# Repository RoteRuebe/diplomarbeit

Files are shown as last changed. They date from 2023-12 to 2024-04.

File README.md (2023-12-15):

Repository mit allen Files für die Diplomarbeit. An der Diplomarbeit arbeiten:

1. Lukas Lucut     (Hardware)
2. Bastian Eismann (3D - Modeling)
3. Yannick Zickler (Software)

---

# Hardware

Hier sind die Kicad - Platinendesigns von Roboter und Controller zu finden. Beide haben jeweils zwei Versionen, Rev A und Rev B.

# 3D - Modeling

Hier werden alle 3D Modelle und Cura 3D Setting sein.

# Software

Hier sind alle Codes der Diplomarbeit zu finden. Es gibt Testcodes für einzelne Module sowie die zusamengesetzten Hauptcodes

# Misc.

Außerdem sind die derzeitige Version der Diplomarbeit, Arbeitzeiterfassung (AZE) und der Projektplan hochgeladen.

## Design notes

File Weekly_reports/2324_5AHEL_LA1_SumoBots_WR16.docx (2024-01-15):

Weekly Report 16

Jahrgang/Klasse: 5AHEL
Übungsleiter: | Prof. Dipl.-Ing. Michael Zatl
Übungsdatum: | 01.01.2024 – 06.01.2024
Abgabedatum: | 13.01.2024
Gruppe: | SumoBots
Projektteilnehmer: | Lukas Lucut Yannick Zickler Bastian Eismann
Beurteilung:
Vermerke des Übungsleiters:

Inhaltsverzeichnis

# 1 Tätigkeiten

## 1.1 3D-Design und Konstruktion (EISMANN)

Aufgrund von mehreren Arbeitsaufträgen und Prüfungen, konnte im Arbeitspaket 3D-Desgin und Konstruktion nicht gearbeitet werden.

## 1.2 Hardware-Entwicklung (LUCUT)

Da noch auf die PCB-Bestellung gewartet wird, wurde die Zeit genutzt, um weitere Kapiteln in der Diplomarbeit zu schreiben, sowie ältere Kapiteln zu Verbessern.

## 1.3 Software-Entwicklung (ZICKLER)

Es wurde ein Code geschrieben, mit welcher die Sensordaten vom Roboter auf einer HTML-Seite in einem Diagramm illustriert werden. Des Weiteren wurden einige Kapitel in der Diplomarbeit überarbeitet und hinzugefügt.

# 2 Next Steps

## 2.1 3D-Design und Konstruktion (EISMANN)

Der Designprozess des letzten Gehäuses wird mit der Ankunft des PCBs begonnen.

## 2.2 Hardware-Entwicklung (LUCUT)

Falls kommende Woche die Platine da sein sollte, wird diese Bestückt und bereits in Betrieb genommen.

## 2.3 Software-Entwicklung (ZICKLER)

Mit einer fertig bestückten Platine, beginnt der Debug-Ablauf von neu, um alle Funktionen des Mikrocontrollers sicherzustellen. Dazu werden die Sensoren in den Code implementiert, um diese mit dem Funkmodul an einem Raspberry Pi zu senden, welcher diese auf einer Website in einem Diagramm darstellt.

LABOR Seite 11 von 11

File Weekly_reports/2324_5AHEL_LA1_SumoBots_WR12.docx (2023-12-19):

Weekly Report 12

Jahrgang/Klasse: 5AHEL
Übungsleiter: | Prof. Dipl.-Ing. Michael Zatl
Übungsdatum: | 08.12.2023
Abgabedatum: | 15.12.2023
Gruppe: | SumoBots
Protokollersteller: | Lukas Lucut
Übungsteilnehmer: | Yannick Zickler
| Bastian Eismann
Beurteilung:
Vermerke des Übungsleiters:

Inhaltsverzeichnis

# 1 Tätigkeiten

## 1.1 3D-Design und Konstruktion (EISMANN)

Im Laufe der Woche traten vermehrt Druckprobleme und Instabilitäten bei den 3D-Drucken auf, welche sich nach einiger Fehlersuche als ein Problem mit dem Extruder des Ender 3s herausstellte. Bei diesem ist eines der beiden Zahn-räder bis auf den letzten Zahn abgerundet worden, wodurch sich oben genannte Probleme zeigten. Die nötigen Ersatzteile wurden bestellt. Ein weiterer Punkt der Woche war die Verbesserung von alten 3D-Modellen, um auf die Wünsche der anderen Abteilungen einzugehen. Dies beinhaltet: Sensorenhalterungen, LCD-Screen-Aushebung, Platzierung des An-Aus-Schalters sowie die Inkludierung einer RGB-Status-LED.

## 1.2 Hardware-Entwicklung (LUCUT)

Zunächst wurden die Sensoren für das Roboter Rev B PCB ausgewählt und die jeweilige KiCAD Library wurde recherchiert und nach Richtigkeit überprüft. Die jeweiligen Sensoren wurden bereitgestellt und werden in nächster Zeit programmiert, um sie nach der Bestückung der Platine, auf Funktion testen zu können. Die restliche Zeit wurde für die Dokumentation der bereits vollbrachten Arbeit investiert, um mit dem konkurrierenden Aufbaulehrgang mitzuhalten.

## 1.3 Software-Entwicklung (ZICKLER)

Die Verbindung zwischen den Roboter und einem Raspberry mit einem Funkmodul wurde ermöglicht, ohne das die Kommunikation zwischen Controller und Roboter zu stören. Damit wurde ein Meilenstein der Diplomarbeit vollbracht, welche durch den gezielten Einsatz von Alufolie, ermöglicht wurden.

# 2 Next Steps

## 2.1 3D-Design und Konstruktion (EISMANN)

Es sollen erhaltene Ersatzteile des Druckers verbaut und getestet werden und im anschluss weitere Drucke gestartet werden.

## 2.2 Hardware-Entwicklung (LUCUT)

Der Schaltplan wird weiterentwickelt und versucht bis zum Ende der Ferien fertigzustellen. Falls dies nicht zutreffen sollte, werden in den letzten zwei Tagen Vorbereitungen getätigt, um die Arbeit im „Home-Office“ weiterführen zu können.

## 2.3 Software-Entwicklung (ZICKLER)

Es werden Testcodes für jegliche Zusatzmodule geschrieben, die die Arbeit des Debugging erleichtern soll. Falls während diesen Tätigkeiten keine Probleme auftreten sollten, wird an dem vollständigen „Main-Code“ weitergearbeitet.

LABOR Seite 11 von 11

Next Steps

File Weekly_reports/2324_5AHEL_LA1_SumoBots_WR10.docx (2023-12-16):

Weekly Report 10

Jahrgang/Klasse: 5AHEL
Übungsleiter: | Prof. Dipl.-Ing. Michael Zatl
Übungsdatum: | 10-24.11.2023
Abgabedatum: | 21.11.2023
Gruppe: | SumoBots
Projektteilnehmer: | Lukas Lucut Yannick Zickler Bastian Eismann
Beurteilung:
Vermerke des Übungsleiters:

Inhaltsverzeichnis

# 1 Tätigkeiten

## 1.1 3D-Design und Konstruktion (EISMANN)

Im Bereich 3D-Design und Konstruktion wurden Anpassungen am Gehäuse und am Antriebssystem vorgenommen. Eine Umstrukturierung bestimmter Komponenten im Gehäuse ermöglicht nun einen kompakteren Aufbau. Feste Positionen für die Antenne des Funkmoduls, den Farbsensor, einen Ausschalter, eine Status-LED und weitere Komponenten wurden erfolgreich festgelegt. Die Konstruktion des Controller-Gehäuses hat erste Design-Schritte durchlaufen, um eine grobe Bauart und Größe zu ermitteln.

## 1.2 Hardware-Entwicklung (LUCUT)

Es wurden alte Schaltungen und Komponenten überdacht. Dabei wurde besonderes Augenmerk auf die Integration zusätzlicher Sensoren gelegt. Die Umleitung einzelner Komponenten wie dem Funkmodul, dem Farbsensor und der Ladebuchse auf feste Positionen im Gehäuse wurde mit der 3D-Moedllierung besprochen. Die Anpassung der alten Akkuschrauber Trigger mit einem Tiefpass zur Bestückung des Controllers wurde ebenfalls als Plan festgelegt.

## 1.3 Software-Entwicklung (ZICKLER)

Es wurde sich konzentrierte auf weitere Tests zur Verbindung der Funkmodule. Die ersten Tests zur Integration des Raspberry Pi zur Ausarbeitung der Daten der vorgesehenen Sensoren wurden gestartet. Die Verbindungen zwischen dem Roboter und dem Controller wurden weiter überarbeitet, um die Funktion der Status-LED als verbessertes Diagnose-Tool zu nutzen.

# 2 Next Steps

## 2.1 3D-Design und Konstruktion (EISMANN)

Weitere Verbesserung an sowohl Roboter als auch Controller Gehäuse mit Rücksicht auf die Wünsche der anderen Abteilungen.

## 2.2 Hardware-Entwicklung (LUCUT)

Erstellung der neuen Roboterplatine nach Sicherstellung einer stabilen Funkmodul Verbindung in Zusammenarbeit mit der Abteilung Software.

## 2.3 Software-Entwicklung (ZICKLER)

Weiter Tests in Sachen Verbindung des Roboters und Controllers sowie Fehler Behebung bei der Raspberry Verbindung.

LABOR Seite 11 von 11

Next Steps

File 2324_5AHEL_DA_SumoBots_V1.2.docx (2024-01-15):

# DIPLOMARBEIT

# SumoBots

# Schuljahr 2023/24

Ausgeführt im Schuljahr 2023/24 von:

EISMANN Bastian | 5AHEL

LUCUT Ioan Lukas | 5AHEL

ZICKLER Yannick | 5AHEL

Betreuer/Betreuerin:

DI (FH) Michael Zatl

Erklärung über die eigenständige Verfassung

der Diplomarbeit

Wir, die Herren Bastian EISMANN, Ioan LUCUT und Yannick ZICKLER, Schüler der Klasse 5AHEL der Höheren Technischen Bundeslehranstalt Wien 10, erklären hiermit an Eides statt, dass wir die vorliegende Diplomarbeit selbständig und ohne fremde Hilfe verfasst haben, einschließlich auch andere als die angegebenen Quellen und Hilfsmittel nicht benutzt und die benutzten Quellen, wörtlich und inhaltlich entnommenen Stellen, als solche erkenntlich in der Diplomarbeit gekennzeichnet haben.

Wien am 31.05 2024

Verfasser:

Bastian EISMANN | 5AHEL U: ___________________

Ioan Lukas LUCUT | 5AHEL U: ___________________

Yannick ZICKLER | 5AHEL U: ___________________

# 1 Danksagung

xxxxxxxx

# 2 Zusammenfassung (Deutsch)

Das Ziel dieser Diplomarbeit war es, einen Fahrzeugroboter, welcher durch eine Funkverbindung mit einem selbst entwickeltem Controller, gesteuert werden kann, zu entwickeln und konstruieren. Joystick und Schultertasten des Controllers geben Geschwindigkeit und Richtung des Roboters vor.

In diesem Projekt werden zwei separate Printed Circuit Boards (PCBs) entwickelt, die mithilfe von KiCAD entworfen werden. In jeden der beiden Platinen ist ein AVR-Mikrocontroller integriert, der für die Steuerung der jeweiligen Schaltung verantwortlich ist. Die Kommunikation zwischen den beiden erfolgt über das NRF24L01+ Funkmodul.

In der Diplomarbeit spielen die Auswahl des richtigen Materials und die Kalibrierung der 3D-Drucker eine zentrale Rolle. Die Gewährleistung des Druckererfolgs erforderte wesentliche Verbesserungen am Drucker. Ein weiterer entscheidender Schwerpunkt liegt auf der Modellierung von Gehäusen, Rädern, Antriebssystemen und dem Controller. Hierbei müssen zahlreiche Variablen berücksichtigt werden, um den Anforderungen verschiedener Abteilungen gerecht zu werden.

Die Mikrocontroller werden mit der Arduino – Umgebung und SPI – Schnittstelle programmiert. Der Code des Controllers muss seine Eingabeelemente einlesen und an den Roboter weiterschicken. Dieser muss die Werte einlesen, berechnen wie stark er den linken und rechten Motor ansteuern muss, und diesen Wert mit PWM – Signal an das Motorshield weiterleiten.

## 2.1 Abstract (English)

The goal of the diploma thesis is to develop and construct a vehicle robot that can be controlled through a wireless connection with a self-designed controller. The joystick and shoulder buttons of the controller determine the speed and direction of the robot.

In this project, two separate Printed Circuit Boards (PCBs) will be developed using KiCAD. Each of these boards will integrate an AVR microcontroller responsible for controlling its respective circuit. Communication between the two will be facilitated through the NRF24L01+ wireless module.

The thesis focuses on the selection of appropriate materials and the calibration of 3D printers, which are crucial for ensuring successful printing. Significant improvements to the printer were necessary to guarantee printing success. Another key emphasis is placed on modeling the robot's housing, wheels, propulsion systems, and the controller. This involves considering numerous variables to meet the requirements of different departments.

The microcontrollers will be programmed using the Arduino environment and SPI interface. The controller's code must read its input elements and transmit them to the robot. The robot, in turn, will need to read these values, calculate how much to control the left and right motors, and send this value to the motor shield using a PWM signal.

# 3 Einleitung – Projektbeschreibung

xxxx

Abbildung 1: Systemarchitektur des Projekts

## 3.1 Vorgeschichte – Ausgangslage

### 3.1.1 Projektwoche 2023

Im Zuge der vergangenen Projektwoche wurde bereits ein Roboter und eine Fernsteuerung entwickelt und in Betrieb genommen. Beide Prototypen wurden von dem
AVR-Mikrocontroller ATMEGA 328p angesteuert. Die Kommunikation zwischen den beiden, wurde durch das Funkmodul NRF24L01+ ermöglicht, welches die Daten vom Controller an den Roboter sendet. Mit diesen Daten steuert das implementierte Motorshield Cytron MDD3A die Motoren. Als Spannungsquelle wurde ein 12V Bleiakku genutzt.

### 3.1.2 CLIL 2023

Während des CLIL-Unterrichts 2023, wurde als Ziel die Weiterentwicklung der entwickelten SumoBots, sowie die Verbesserung von Konstruktion und Hardwarefehlern gesetzt, um die Milestones der Diplomarbeit genau definieren zu können. Bei der Konstruktion wurde auf das Arbeiten mit Fusion 360 gesetzt, um verbesserte und professionellere 3D-Modelle konstruieren zu können. In der Hardwareentwicklung wurde ein Fehler, welcher im Zusammenhang mit den unterschiedlichen Logikpegeln des Mikrocontrollers und Funkmoduls steht, durch einen Logic-Level-Converter verbessert. Des Weiteren wurden einige Recherchen, sowie eine Testschaltung entwickelt. In der Software wurde der Fokus auf
In-System-Programming gelegt, in welchen einige Testcodes geschrieben wurden.

# 4 Struktur des Projekts – Arbeitspakete

## 4.1 Objektstrukturplan (OSP) / Arbeitspakete

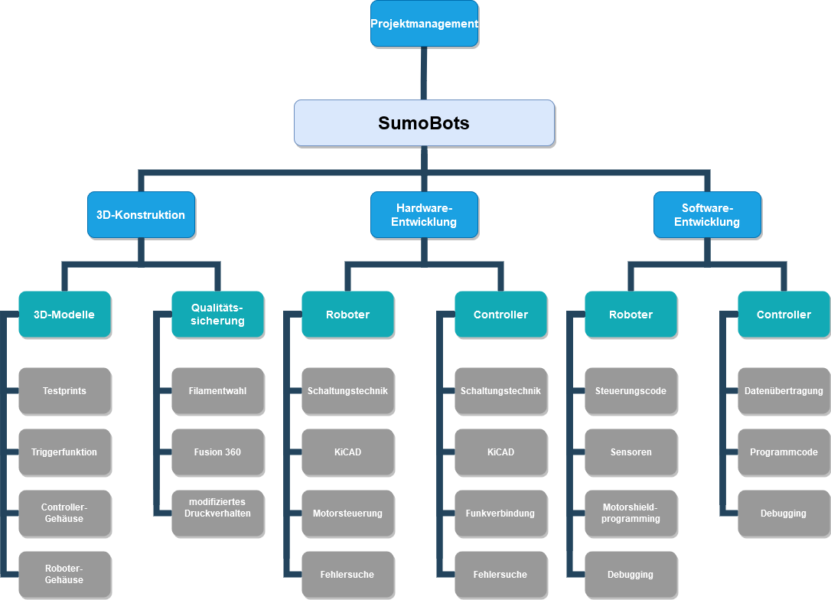
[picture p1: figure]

Abbildung 2: Objektstrukturplan (OSP) / Arbeitspakete

Um einen besseren Einblick der Tätigkeiten, sowie deren Aufteilung in den Arbeitspaketen zu gewähren, wird die Diplomarbeit in einem Objektstrukturplan dargestellt. Hier wurden die dazu gehörigen Hilfsmittel, Aufgaben, sowie die benötigten Fähigkeiten für das jeweilige Arbeitspaket genau beschrieben.

## 4.2 Projektstrukturplan (PSP)

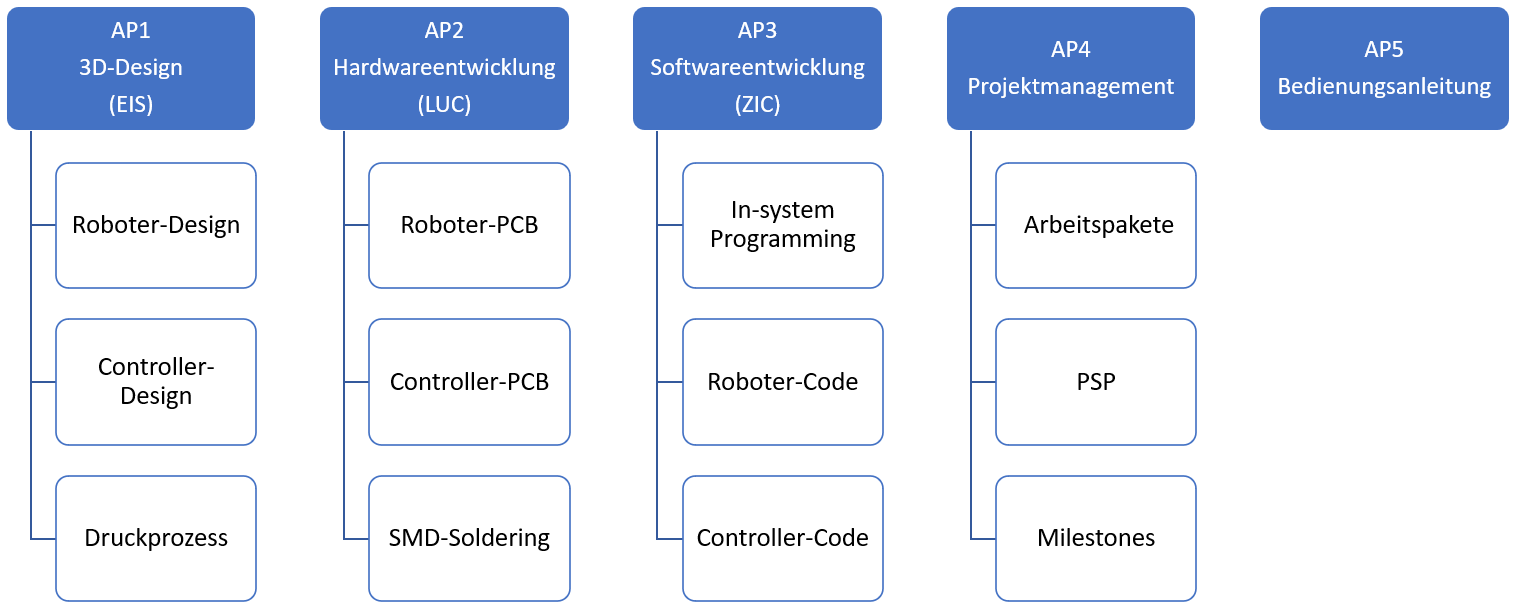
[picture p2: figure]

Abbildung 3:Projektstrukturplan (PSP) AP1-AP6

Die im oberen Diagramm beschriebenen Tätigkeiten wurden in Arbeitspakete und daraufhin auf die Diplomanden aufgeteilt.

## 4.3 Arbeitspaket 1 3D-Design (EIS)

Im Arbeitspaket „3D-Konstruktion“ wird neben den 3D-Modellen, ebenfalls Qualitätssicherung benötigt, da dieses Aufgabengebiet die Stabilität und Qualität der 3D-Prints sicherstellen.

## 4.4 Arbeitspaket 2 Hardware-Entwicklung (LUC)

Die Schaltungsentwicklung wird im Arbeitspaket „Hardware-Entwicklung“ bearbeitet, in welchen der Entwicklungsprozess des Roboters und des Controllers Schrittweise abgebildet ist. Der Hauptfokus liegt hierbei in der Entwicklung des Schaltplans und des darauffolgenden Platinenlayouts, welches in KiCAD designet wird. Es werden hierbei doppelseitige Platinen erstellt, um die in der Projektwoche eingebauten Drahtbrücken zu vermeiden. Diese Platinen werden zum Großteil mit SMD-Bauteilen bestückt, daher ist das SMD-Löten ein wichtiger Bestandteil und stellt damit auch ein Risikofaktor des Arbeitspakets da.

## 4.5 Arbeitspaket 3 Software-Entwicklung (ZIC)

Das Arbeitspaket „Software-Entwicklung“ beinhaltet Softwaredesign, Debugging, Ansteuerung der SPI und I2C Buse zur Programmierung von µC und einlesen verschiedener Sensormodule und die Kommunikation mithilfe von Funkmodulen zwischen Controller und Roboter sowie Roboter und Server.

## 4.6 Arbeitspaket 4 Projektmanagement

Die Struktur, Koordination und Organisation der Diplomarbeit wird im Arbeitspaket „Projektmanagement“ bearbeitet und beinhaltet sämtliche Pläne, Zielsetzung, sowie der dazugehörigen erstellten Milestones-Pläne und Arbeitszeiterfassungen. Um die Arbeitszeiten, samt den Tätigkeiten der Diplomanden im Blick zu behalten, werden diese erfasst und in eine Arbeitszeiterfassung AZE dokumentiert. Des Weiteren werden die Arbeitspakete in einem Projektstrukturplan auf die Diplomanden aufgeteilt, die die Tätigkeiten der Diplomanden auf gewählte Bereiche einschränken. Dazu wird der Fortschritt des jeweiligen Arbeitspakets in einem Granttchart in Projektlibre als Graph dargestellt.

## 4.7 Arbeitspaket 5 Bedienungsanleitung

Um die fertige Diplomarbeit nach Abgabe in Betrieb nehmen zu können, wurde eine Bedienungsanleitung geschrieben, in welcher die Inbetriebnahme, samt weiteren Konfigurationseinstellung, dokumentiert wird.

# 5 3D-Design und Konstruktion

Dieses Kapitel behandelt und beschreibt den Aufbau, sowie die Konstruktion der Mechanik des Roboters und der Controller-Fassung. Für den Bau dieser Komponenten wird das CAD-Programm Autodesk Fusion 360 in Verbindung mit dem Slicer-Programm Cura 3D angewandt. Der gesamte Aufbau des Roboters, sowie des Controllers soll mit eigenerstellten STL-Files 3D-gedruckt werden. Dabei liegt ein beträchtlicher Fokus auf der Wahl des richtigen Materials, beim 3D-Drucken Filament genannt, da diese zwischen den unterschiedlichen Werkstoffen viele differente Eigenschaften aufweisen können.

## 5.1 3D-Drucker Begriffserklärungen

### 5.1.1 Vom CAD-File zum Drucken

Der erste Schritt im 3D-Design und Druckvorgang beinhaltet die Wahl des gewünschten CAD oder auch Computer Aided Design Programmes, welches zum Erstellen der benötigten Dateien benutzt wird. Zur Auswahl stehen hier eine große Ansammlung von verschiedensten CAD-Programmen für den Heim- als auch Firmengebrauch. Durch persönliche Erfahrungen mit dem Programm Fusion 360 von Autodesk, wurde dies für die gesamte Konstruktion von Roboter als auch Controller benutzt. Das verwendete Dateiformat für die Modellierten Teile wurde auf .STL Files festgelegt, da diese am einfachsten durch ein Slicer-Programm weiterzuverarbeiten sind.

Ein sogenannter Slicer wird benötigt um die .STL Dateien auf eine Koordinatenorientierte Programmiersprache mit dem Namen G-Code zu übersetzen. 3D Drucker können diesen Ge-sliced G-Code dann auslesen und nach vorgaben der ursprünglichen .STL Datei nach drucken. Hierbei arbeitet der Drucker mit Seinen 3 Achsen X- , Y- und Z-Achse um die vorgegebenen Koordinaten und befehle im G-Code abzufahren, wodurch das gewünschte Modell entsteht.

Ein anderes Feature der Slicer ist es verschiedene Druckeigenschaften für den bestimmten Druckvorgang zu konfigurieren, wodurch zum Beispiel die Geschwindigkeit, Temperatur, Startposition sowie viele anderen Faktoren individuell für jeden Druck geändert werden können. Als Slicer für alle 3D-Modelle fiel die Wahl auf Ultimaker Cura 3D, wegen seiner vielfältigen Einstellmöglichkeiten und Optionen.

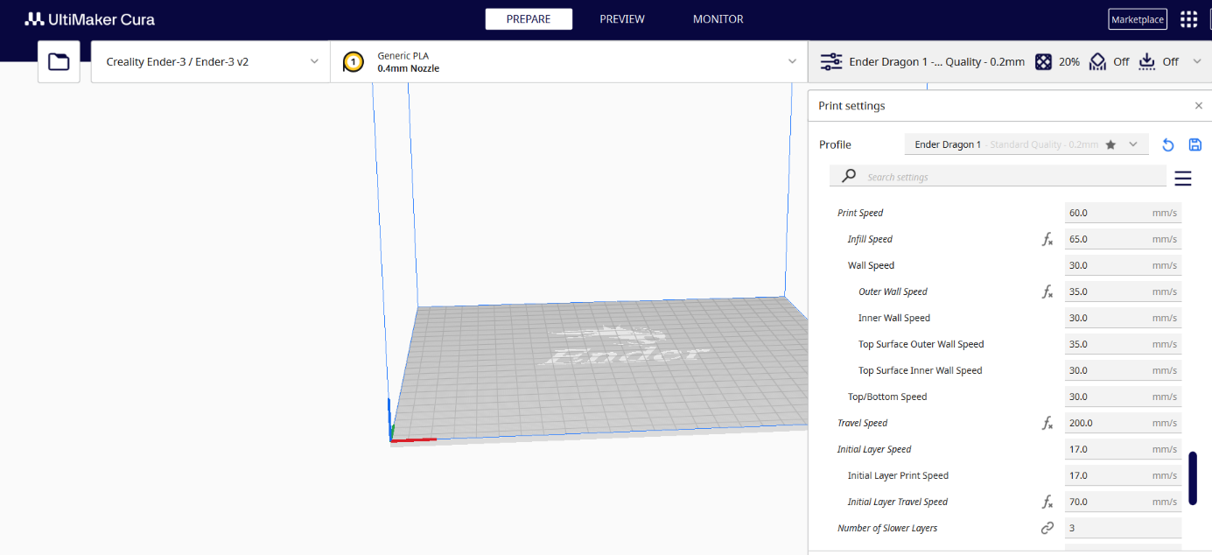
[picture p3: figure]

Wie in Abbildung 4: Cura 3D Interface zu sehen verfügt der Slicer über eine 3D-Ansicht in welcher der geplante Druck inspiziert und verschoben werden kann. Als Beispiel für die Einstellungsmöglichkeiten sind auf der rechten Seite der Abbildung die Geschwindigkeit Settings zu sehen welche den Travel Speed des Hotends sowie der restlichen Stepper-Motoren kontrolliert. Zu hohe Geschwindigkeiten können einen unsauberen Druck auslösen oder im schlimmsten fall sogar zum kompletten Fehldruck, siehe Abbildung 5: Kompletter Druckfehler, führen, welcher auch umgangssprachlich als „Spaghetti“ bekannt ist.

Abbildung 4: Cura 3D Interface

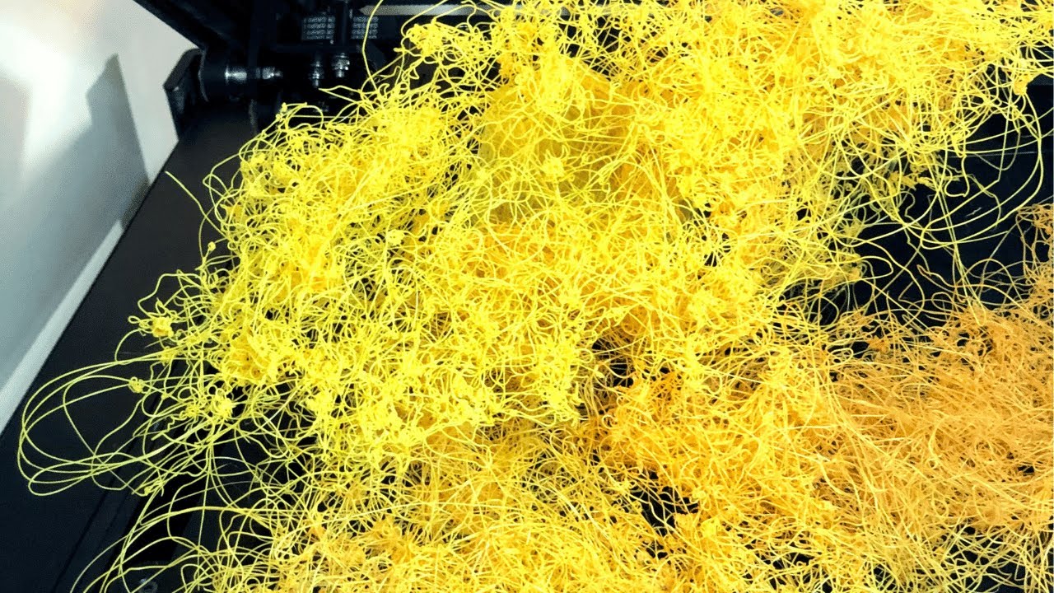
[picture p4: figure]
The Spaghetti Detective - YouTube

Abbildung 5: Kompletter Druckfehler

### 5.1.2 3D Drucker

Im laufe dieses Kapitels werden verschiedene begriffe und Beschreibungen für einzelne Komponenten eines typischen 3D Druckers verwendet. In diesem Abschnitt sollen die wichtigsten Begriffe aufgezeigt und erklärt werden.

## 5.2 Materialeigenschaften

Die Wahl des richtigen Filaments kann massive Auswirkungen auf sowohl Druckqualität wie auch Druckstabilität haben. Dadurch eignen sich manche Werkstoffe besser für gewisse Anwendungen als andere und können anhand verschiedener Anforderungen gewählt werden. Bei den 3D-Drucken verwendete Filamente sind PLA, PLA+, ABS und PETG, welche für diverse Anwendungen gebraucht oder getestet wurden.

### 5.2.1 PLA, PLA+

PLA auch Polylactide genannt, sind aus natürlichen Rohstoffen wie Maisstärke oder Zuckerrohr bestehende Polyester und sind eines der populärsten Filamente der Welt des 3D-Druckens. Das Material bietet eine, zu anderen Werkstoffen verglichen, niedrigere Schmelztemperatur was für einen besseren Druckvorgang und Druckqualität bei Temperaturschwankungen im Hotend des Druckers oder der Umgebungsluft.

Das Drucken von Standard PLA Filament ist theoretisch schon mit einer Temperatur von 190°C möglich, wird jedoch aus gesammelten Erfahrungen am besten mit einer Temperatur von 210-213 °C gedruckt. Dabei entwickelt das Filament die beste Haftung an der sogenannten Buildplate des 3D-Druckers, wodurch die Qualität und Stabilität des Drucks um ein Vielfaches gesteigert wird. Negative Aspekte des Filaments sind jedoch auch vielfach vorhanden. PLA ist durch seine Zusammensetzung aus natürlichem Polyester in der Theorie biologisch abbaubar, jedoch lässt sich aus Erfahrungswerten sagen, dass die Abbauzeit der Konstruktion des Controllers, oder der Roboter, keine beachtliche Rolle spielt da diese selbst mit Einwirkung von Regen, Wind und Sonne bis zu 80 Jahre dauern kann. Allerdings ist das Filament für tragende Anwendungen nicht geeignet, da die Festigkeit des Materials mit der Härte von ABS-Plastik nicht mithalten kann.

Zur Lösung dieses Problems gibt es den Stoff PLA+, welcher auf dem originalen PLA basiert, jedoch aber mit einer Reihe von anderen Stoffen kombinierten wurde, um seine positiven Druckeigenschaften zu verbessern und die Negativen, wo möglich, zu entfernen. So bietet dieses Material eine bis zu 10-mal höhere Schlagfestigkeit ohne die negativen Aspekte eines Stoffes wie ABS-Filament mit sich zu bringen.

### 5.2.2 ABS

ABS-Filament oder auch Acrylnitril-Butadien-Styrol ist ebenfalls ein Polyester, der jedoch auf synthetischer Basis hergestellt wird. Dadurch besitzt er nicht den Nachteil theoretisch biologisch abbaubar zu sein, wie PLA-Filament. Doch in der Praxis ist der bemerkenswerteste Unterschied die Schlagfestigkeit des Filaments. ABS besitz einen viel höheren Härtegrad als das übliche PLA-Filament und kann daher für mehr tragende Rollen eingesetzt werden als PLA.

Jedoch bietet dieses Material einen gewaltigen Nachteil im Gegensatz zu anderen Filamenten in Form eines weitaus schwierigeren Druckverfahrens. Die benötigte Temperatur um ABS-Filament stabil und mit guter Qualität Drucken zu können ist mit bis zu 260 °C weitaus höher und schwieriger konstant zu halten als bei vergleichbaren Stoffen, wodurch sich die Anwendung bei unserer Diplomarbeit als praktisch unmöglich herausstellte. Durch diese hohe Drucktemperatur ist das Filament äußerst anfällig für äußere Temperaturschwankungen der Umgebungsluft oder auch Druckplatte, wodurch ein Fehler namens Warping auftreten kann, siehe Abbildung 4 Warping.

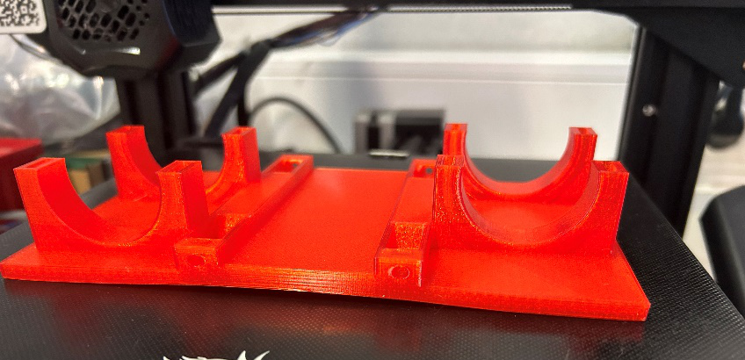
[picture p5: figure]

Abbildung 6: Warping

Hierbei „Warped“ oder verformt sich das Filament aufgrund von Temperaturschwankungen und vor allem große Flächen können deformiert und bis zur Unbrauchbarkeit verbogen werden. In der Theorie kann jeder Filament Stoff solche Ergebnisse hervorbringen, jedoch treten diese Fehler am häufigsten bei hohen Drucktemperaturen wie bei denen von ABS auf. Diese Instabilitäten kann durch konstante Temperaturhaltung ausgeglichen werden, jedoch erwies sich dies als unnötig für unsere Anwendungen da für ein solches Vorhaben eine Art „Druck-Behälter“ oder Kammer gebraucht wird.

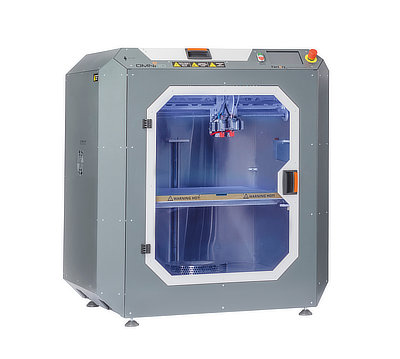
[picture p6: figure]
Omni3D Factory 2.0 NET Industrieller 3D-Drucker | 3D Prima - Top 3D-Drucker, 3D-Scanner, Filament, Resin & Zubehör günstig kaufen

Abbildung 7: 3D Druck Kammer

Diese sind meist extern Beheizt, um eine konstante Temperatur zu bieten und haben eine Luftfiltereinheit verbaut wodurch die Feinstaub- und Geruchs-belastung des ABS-Filament Druckvorgangs ebenfalls verringert wird. Diese Kammern, siehe Abbildung 5: 3D Druck Kammer, sind aber meist mit einem hohen Anschaffungspreis verbunden, wodurch die Hauptkonstruktion des Roboters nicht mit ABS-Filament vorgenommen wurde.

## 5.3 Konstruktionsvorgänge

Ein wichtiger Bestandteil der 3D Konstruktion besteht aus der Wahl der richtigen Teilkomponenten und passenden Verbindungsart.

### 5.3.1 Antriebsarten

Die Wahl der gewünschten Antriebsart wurde durch mehrere Tests und Prototypen festgelegt und durchlief teils massiven Veränderungen. Als Anfangskonzept wurde ein symmetrisches Motorlayout gewählt, bei dem der Roboter zwar nur über zwei Motoren verfügt, diese jedoch mit einer Übersetzung die anderen beiden Räder mitdrehen, um somit einen Allrad Antrieb zu haben der auf einem Ähnlichen Prinzip eines Kettenfahrzeugs oder Panzers basiert.

Durch die Symmetrie der beiden Roboterhälften wurde sowohl der Arbeitsaufwand als auch die Druck-Schwierigkeit enorm verringert.

### 5.3.2 Rahmen des Roboters

### 5.3.3 Verschraubungen und Normen

### 5.3.4 Embedded Components (EC)

## 5.4 3D-Modellierung des Roboters

## 5.5 3D-Modellierung des Controllers

# 6 Hardwareentwicklung

Im folgenden Kapitel werden die Funktionen, sowie die jeweiligen Entwicklungsschritte der Hardware des Roboters und Controllers erklärt. In Zuge dessen wird das Konzept der Steuerung, sowie der Kommunikation mit der dazugehörigen elektronischen Schaltung aufgegriffen.

## 6.1 Konzept

xxx

## 6.2 Entwicklungsablauf

Da in diesen Teil des Arbeitspakets mehrere Fehler auftreten können, wurde ein Flussdiagramm erstellt, das die Abläufe der Entwicklung, sowie weitere optionale Schritte darstellt. Das Vorplanen der Tätigkeiten ist hier besonders wichtig, aufgrund der aufkommenden Kosten der durch die PCB-Bestellungen von externen Firmen entsteht.

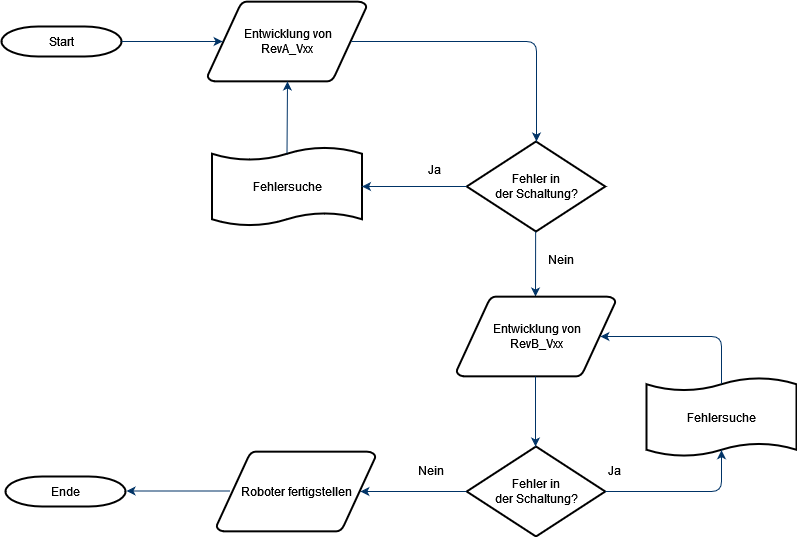
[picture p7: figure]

Abbildung 6 Entwicklungsablauf der Roboter Hardware

Dabei wurde die Hardware des Roboters in Revision A (RevA) und Revision (RevB) geteilt. In
Revision A wird eine Platine mit den elektronischen Grundkomponenten entworfen, die benötigt werden, um den Roboter zum Fahren zu bringen. Bei Revision A wird der Fokus auf dem Ermitteln und Korrigieren von vermeintlich auftretenden Fehlern. Falls in der ersten Version des PCBs gravierende Fehler auftreten, die das in Betrieb nehmen der Schaltung nicht ermöglichen, wird eine weitere Version von Revision A entwickelt. Wenn dieser optionale Fall nicht eintritt, wird die Revision B Schaltung entwickelt, bei der die funktionsfähige Schaltung von Revision A mit Sensoren und weiteren Bauelementen aufgewertet wird.

## 6.3 Hardware-Design Roboter Revision A

Wie bereits beschrieben, beschränken sich die Hauptaufgaben dieses Schaltungsentwurfs auf die Kommunikation mit einem Controller, die Steuerung der Motoren durch diesen sowie die In-System-Programmierung.

Abbildung 7 Blockschaltbild von Roboter Rev A V1.00

Als Mikrocontroller wird der ATMEGA2560 eingebaut, der als essentieller Teil der Schaltung gilt. Damit dieser funktioniert, muss eine 5V Gleichspannungsquelle und ein digitales Taktsignal vorhanden sein. Diese Versorgungsspannung wird durch das Motorshield ermöglicht, da auf diesem ein Spannungsregler verbaut ist, der die 12V vom Bleiakku in 5V umwandelt. Die 12V vom Bleiakku werden benötigt, um die Motoren zu versorgen. Das Taktsignal wird durch einen externen Quarzoszillator mit 16MHz generiert, der die Geschwindigkeit der Programmabläufe beeinflusst. Des Weiteren wird eine 3.3V Spannungsquelle benötigt, um das Funkmodul NRF24L01+ in Betrieb zu nehmen. Das Funkmodul arbeitet hierbei mit unterschiedlichen Logikpegeln als der Mikrocontroller. Um Fehler bei der Übertragung von Daten zu vermeiden, wird ein Logik-Pegel-Wandler (Logic Converter) dazwischengeschaltet, der die Pegeln von 3.3V auf 5V umwandelt. Da es sich hierbei um ein selbstentwickeltes PCB handelt, ist keine serielle Schnittstelle vorhanden. Um den Mikrocontroller programmieren zu können, wird über den SPI-Bus programmiert. Die
SPI-Pins (MOSI, MISO, SCK) sind auf den ICSP-Header vorhanden.

### 6.3.1 Roboter Revision A V1.00 PCB-Design

Das im Kapitel Error: Reference source not found illustrierte Blockschaltbild wurde in KiCAD als Schaltplan, sowie als Platinenlayout realisiert. Aufgrund der dünnen Bahnen von 0,25mm können beim Ätzen Fehler auftreten. Daher wird für die Roboterplatinen auf den schulexternen Hersteller Aisler zurückgegriffen.

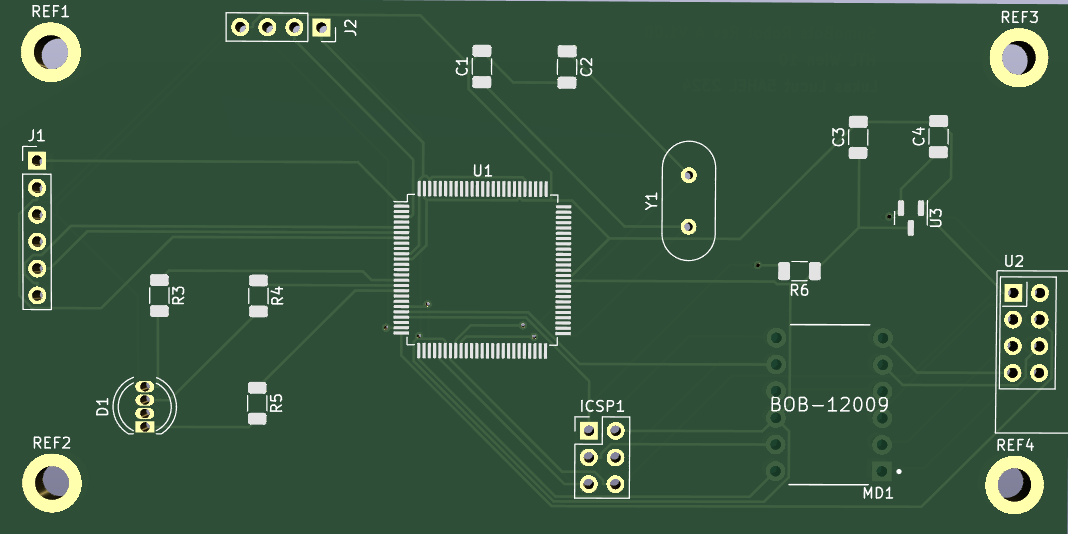
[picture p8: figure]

Abbildung 8 Roboter Rev A V1.00 PCB

Da hier das Löten mit SMD-Komponenten im Vordergrund steht, wurde der Platz zwischen den Bauteilen vergrößert, um leichter Fehler, die durch das Löten mit Heißluft zustande kommen, auszubessern. Im Fokus liegt hierbei der Mikrocontroller, der durch die Anzahl von 100 Pins, welche jeweils 0,25mm breit sind, fehleranfällig auf Kurzschlüsse ist. Der Quarz Y1, der als Taktgeber für den Mikrocontroller dient, sollte möglichst nah platziert werden, um kurze Signalwege zu gewährleisten. Durch die Minimierung von Leitungslängen werden Laufzeitverzögerungen reduziert, was die präzise Synchronisation des Mikrocontrollers verbessert. Gleichzeitig verringert dies die Anfälligkeit für elektromagnetische Störungen und trägt zur Gesamtstabilität und Leistungsfähigkeit des elektronischen Systems bei. Da das Motorshield über keine eigene KiCAD-Bibliothek verfügt, wurde stattdessen ein 6x1-Pinheader J1 implementiert, auf welchen dieser draufgelötet wird. Ein weiterer Grund für die Positionierung lag an seiner Größe und den Verbindungen, bei denen breitere Drähte mit den Motoren und dem Bleiakku verbunden werden müssen. Der 4x1 Pinheader J2 besteht aus zwei digitalen Pins, Vcc und Masse. Diese waren dazu vorgesehen, weitere Komponenten anzuschließen und auf Fehler zu überprüfen. Um das In-System-Programming zu ermöglichen wurde dieser ICSP-Header als 2x3 Pinheader ICSP1 realisiert. Dabei wurde die Reihenfolge der Pins vom Arduino UNO übernommen, um Fehler zu vermeiden. Das Funkmodul U2 wurde aufgrund seiner herausstechenden Antenne, am Rand der Platine positioniert, sodass ein Großteil des Gehäuses sich außerhalb des PCB befindet. Da für die Kommunikationskomponente eine Bibliothek existiert, gibt KiCAD bei dem Design Rule Check (DRC) eine Warnung aus, dass die Lötstoppmaske geschnitten wird. Aus diesem Grund wurde, wie in Abbildung 8 Roboter Rev A V1.00 PCB dargestellt, nur ein Teil des Umrisses (Front Silkscreen) auf der Platine realisiert. Für den Logik-Pegel-Wandler wurde eine Bibliothek genutzt, die ein anderes Modell, aber dasselbe Footprint mit derselben Reihenfolge von Pins, beinhaltet. Wie in Abbildung 8 Roboter Rev A V1.00 PCB zu erkennen ist, sind die Pin-Verbindungen nicht vergoldet. Dies hat zur Folge, dass es nicht möglich ist, den Logik-Pegel-Wandler an die Platine zu löten. Der Grund hierfür liegt an dem vorkonfiguriertem Footprint, dessen Pins keinem Layer (Front Mask/ Back Mask) zugewiesen wurden.

Bild vom fertig gelötetem PCB Vorderseite

Der Mikrocontroller wurde zunächst auf den Lötpads positioniert, und anschließend wurde jeder einzelne Pin mittels einer dünneren Lötspitze mit Flussmittel verlötet. Durch diesen Prozess konnten die Anzahl der Kurzschlüsse minimiert werden und leichter ausgebessert werden. Die restlichen SMD-Komponenten (Widerstände, Kondensatoren, Längsregler) wurden mit einer Lötpaste auf die Lötpads platziert, welche durch eine Erhitzung einer Heißluftstation, in den Schaltkreis implementiert wurde. Da es sich bei den restlichen Komponenten um THT-Bauteile handelt, wurden diese mit einem herkömmlichen Lötkolben verlötet.

### 6.3.2 Roboter Revision A V1.00 Erkenntnisse

Nach dem Erhalt der Platinen machte sich der Fehler, welcher durch den Logik-Pegel-Wandler zustande kam, bemerkbar. Dadurch war das Funkmodul nicht mit dem SPI-Bus verbunden. Da jedoch der ICSP-Header mit den benötigten Pins des Buses verbunden ist, wurden vom Funkmodul an den Pins MOSI, MISO, SCK Drähte an die entsprechenden Pins des ICSP-Headers verlötet. Zusätzlich wurden zwei digitale Pins (CE, CSN) benötigt, welche durch den Pinheader J2 zur Verfügung standen. Diese wurden ebenfalls mit einer Drahtbrücke miteinander verbunden. Zunächst wurden der Logik-Pegel-Wandler dazwischen gelötet, um den entwickelten Schaltplan zu befolgen. In diesem wird beschrieben, dass MISO, MOSI und SCK auf 5V konvertiert werden. Nach diesem Aufbau konnte das Funkmodul zwar eine Verbindung herstellen, bekam allerdings nur zufällige fehlerhafte Werte.

Der Fehler lag hierbei an dem MISO-Pin, welcher nicht umgewandelt werden durfte. Als dieser Fehler verbessert wurde, konnten die richtigen Werte erhalten werden. Nach diesem Test wurde aus dem Datenblatt die Information entnommen, in welcher beschrieben wird, dass kein Logik-Pegel-Wandler benötigt wird, da der NRF24L01+ 5V tolerant ist. Daher wurde für einen weiteren Test der Wandler nicht mit eingebaut.

Xx Bild von der Rückseite der Platine xX

Mit der anschließenden bestückten Platine konnte die Kommunikation, samt der Fernsteuerung des Motorshields getestet werden und resultierte eine erfolgreiche Schaltung.

## 6.4 Komponenten des Roboters Revision A

### 6.4.1 Motorshield

Da die Information, die der Mikrocontroller ausgibt, lediglich 0 oder 1 ist (0V / 5V) kann ein einzelner DC-Motor diese nicht verarbeiten. Bei einer direkten Verbindung zwischen dem Motor und des Mikrocontroller würde sich dieser nur mit einer konstanten Geschwindigkeit in einer Richtung oder gar nicht bewegen. Deswegen ist es möglich mit Hilfe eines dazwischen geschalteten Motorshields einen Motor mit Software in verschiedenen Modi anzusteuern.

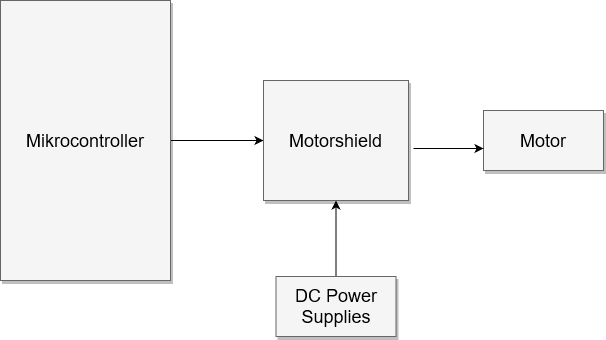
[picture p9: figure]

Abbildung 9 Motorshield-Blockschaltbild

Das Motorshield steuert den Motor mittels einer „H-Brücke“ mit PWM-Signalen an. Je nach Motorgröße ist eine zusätzliche Spannungsquelle notwendig, da nicht jeder mit 5V in Betrieb genommen werden kann. Da in der Diplomarbeit ein 12V Motor verwendet wurde, wird im Blockschaltbild die entsprechende Spannungsquelle integriert.

### 6.4.2 H-Brücke

Eine H-Brücke besteht aus vier Transistoren, die in einer „H“-Form geschaltet sind, um den Stromfluss in zwei Richtungen durch den Motor steuern zu können. In diesem Motorshield besteht die H-Brücke aus N- und P-Channel MOSFETs.

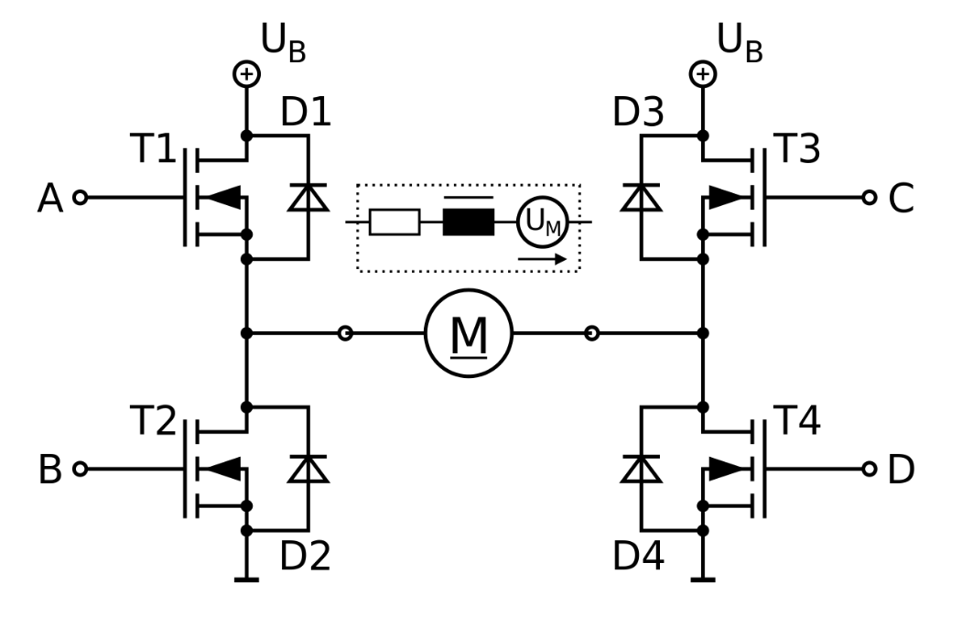
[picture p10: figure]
undefined

Abbildung 10 H-Brücke Schaltplan ( https://de.wikipedia.org/wiki/Vierquadrantensteller)

Um die Steuerung eines Motors zu ermöglichen, werden die Gate-Eingänge an den PWM-Pins des Mikrocontroller angeschlossen. Durch das Duty-Cycle-Verhältnis ist es nun möglich den Motor in verschiedenen Drehrichtungen mit einer dazugehörigen Geschwindigkeit rotieren zu lassen.

### 6.4.3 NRF24L01+ Funkmodul

Die Kommunikation zwischen dem Controller und dem Roboter wird durch das Funkmodul NRF24L01+ ermöglicht. Das Funkmodul arbeitet auf einem 2.4GHz ISM-Frequenzband, mit welchen ein drahtloser Austausch ermöglicht wird. Entwickelt von der Firma Nordic Semiconductor, zeichnet sich der NRF24L01+ durch seine hohe Effizienz und niedrige Leistungsaufnahme. Zusätzlich zur integrierten Antenne, die die Grundlage für die drahtlose Kommunikation bildet, besteht die Möglichkeit, externe Antennen anzuschließen, um die Reichweite des Moduls zu erweitern. Im Vergleich zum Vorgänger NRF24L01 bietet dieses Modell eine größerer Reichweite und unterstützt höhere Datenraten bis zu 2Mbit/s, je nach Konfiguration.

Abbildung 11 NRF24L01+ Funkmodul

Die Funktionsweise kann im folgenden Blockschaltbild abgelesen werden:

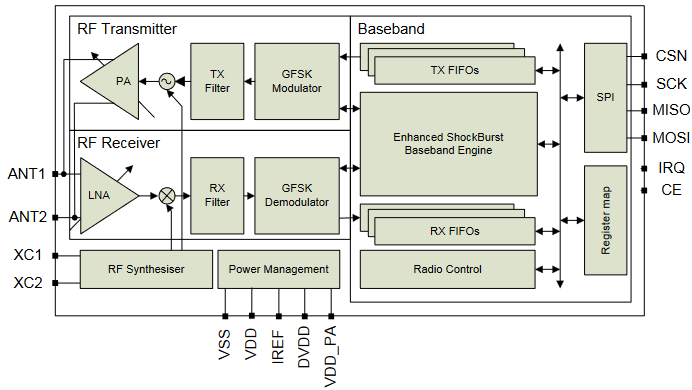
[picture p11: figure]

Abbildung 12 NRF24L01 Blockschaltbild (https://www.sparkfun.com/datasheets/Components/SMD/nRF24L01Pluss_Preliminary_Product_Specification_v1_0.pdf)

Die Informationen werden mittels der GFSK-Modulation (Gaussian frequency-shift keying) übertragen. Bei dieser handelt es sich um eine Art der Frequenzmodulation, bei der zwei Frequenzen für die Übertragung von Binärdaten verwendet werden. Hierbei verwendet der Sender RF-Transmitter („Radio Frequency“) das GFSK-Modulationsverfahren, wodurch digitale Daten in hochfrequente Funksignal im 2,4GHz-Band umgewandelt werden. Diese modulierten Signale enthalten Informationen für die drahtlose Übertragung an andere NRF24L01+-Empfänger. Zusätzlich implementiert dieser Kollisionsvermeidungstechniken, um sicherzustellen, dass mehrere Module im gleichen Netzwerk nicht gleichzeitig senden und kollidieren. Die Möglichkeit automatischer Wiederholungen von Datenpaketen kann bei Bedarf aktiviert werden, um eine zuverlässige Kommunikation zu gewährleisten. Der RF-Receiver übernimmt die Rolle des Empfänger der Signale. Er dekodiert hochfrequente Funksignale, die durch den RF-Transmitter moduliert wurden. Der Empfänger des NRF24L01+ nutzt das GFSK-Verfahren, um die Frequenzverschiebungen im Signal zu interpretieren und die ursprünglichen digitalen Daten wiederherzustellen. Der Baseband-Block im NRF24L01+ ist für die Verarbeitung der digitalen Daten auf der Basisbandebene verantwortlich. Dieser übernimmt die Aufgabe der Modulation der digitalen Daten in ein hochfrequentes Funksignal, die Implementierung von GFSK, sowie der Demodulation empfangener Signale. Durch den SPI-Bus kann das Modul die empfangenen Daten an einem Mikrocontroller übertragen oder weitere Informationen übertragen und gesteuert werden.

#### 6.4.3.1 Spannungsversorgung des Funkmoduls

Für den Betrieb des Funkmoduls ist eine Spannungsversorgung von 3,3V erforderlich. Daher wird eine Schaltung benötigt, die die 5V Betriebsspannung des Mikrocontrollers in 3,3V umwandelt. Um dies zu ermöglich wird der MCP1703A als Längsregler eingebaut, da dieser einen simplen Schaltungsaufbau zur Stabilisierung der Spannung bietet. Aufgrund der Fehler, die durch Spannungsabweichungen beim Übertragen, sowie Senden der Daten auftreten können, können Fehler vorgebeugt werden. Ein Längsregler ist ein Spannungsregler, der überschüssige Energie in Form von Wärme abführt, um die Ausgangsspannung zu stabilisieren. Im Gegensatz zu einem Querregler kann die Ausgangsspannung mittels Dimensionierung von Widerständen nicht geändert werden, da diese vom Hersteller in der Entwicklung festgelegt wurden.

Abbildung 13 3,3V-Längsreglerschaltung

Um Spannungsschwankungen und Rauschauftreten zu verhindert, wird im Datenblatt empfohlen zwei gleichgroße Kondensatoren am Eingang und Ausgang parallel zu schalten. Durch den Kondensator C1 wird sichergestellt, dass der Reger in einem stabilen Betriebszustand bleibt. Der Ausgangskondensator C2 dient dazu, die Ausgangsspannung zu stabilisieren und Spannungsspitzen zu minimieren, damit die Ausgangsspannung auch bei sich ändernden Lastbedingungen konstant bleibt.

#### 6.4.3.2 Spannungsschwankungen des NRF24L01

Wenn man das Funkmodul als Receiver betreibt, können Spannungsschwankungen beim Empfangen von Daten auftreten, die den Datenaustausch hindern können.

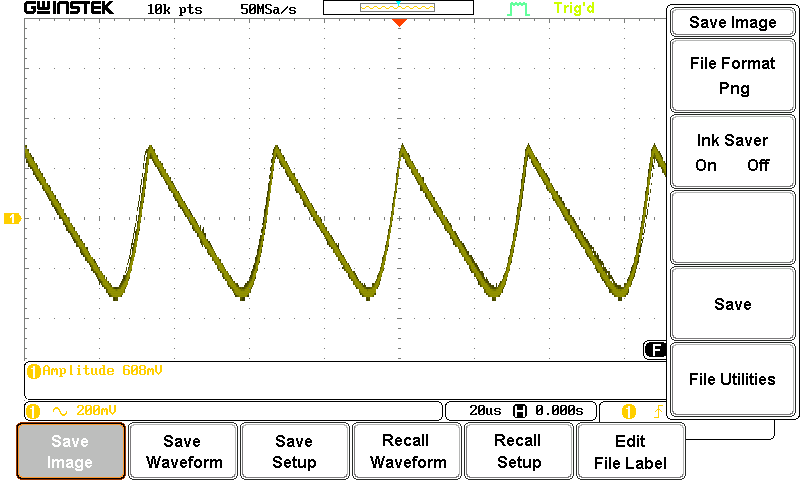
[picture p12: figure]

Abbildung 14 NRF24L01 Messung der Spannungsversorgung

In der oberen Messung wurde die Versorgungsspannung des Funkmoduls mit einem Oszilloskop gemessen. Hierbei kann man die Schwankungen, welche von 600mV – 800mV variieren erkennen, die während der Kommunikation zwischen zwei Modulen auftreten. Daher wurde ein C=10µF Elko zwischen den der Spannungsversorgung eingebaut. Um die resultierende Messung besser interpretieren zu können, wurde ein GPIO-Pin des Arduinos auf „1“ geschaltet.

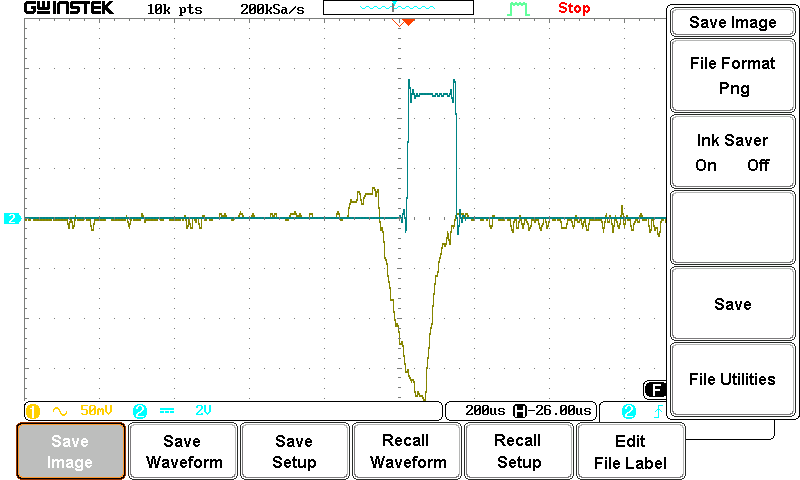
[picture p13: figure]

Abbildung 15 NRF24L01 Messung der Spannungsversorgung mit C = 10µF Elko und Logiksignal

Die in der oberen Messung erkennbaren Störung tritt nur einmal zu Beginn des Datenaustausch auf. Mit einem größeren Kondensator ist eine Verbindung, samt einen korrekten Datenaustausch möglich.

### 6.4.4 Serial Peripheral Interface Bus

Die Serial Peripheral Interface (SPI) ist ein synchroner serieller Bus ermöglicht eine effiziente bidirektionale Datenübertragung zwischen einem Master-Gerät und mehreren Slave-Geräten. Der Bus besteht typischerweise aus vier Hauptleitungen, wobei jede Leitung eine spezifische Funktion erfüllt.

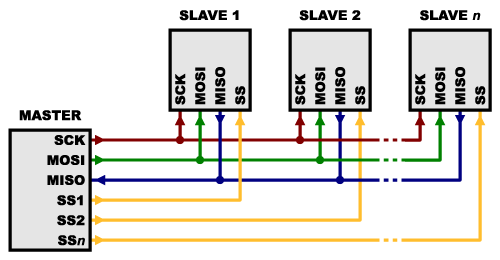
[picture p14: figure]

Abbildung 16 SPI-Bus (https://www.rc-modellbau-portal.de/index.php?threads/spi-schnittstelle-beim-arduino-co.6994/)

Die MOSI-Leitung (Master Out Slave In) dient dazu, dass der Master Daten an die Slaves übertragen kann. Umgekehrt ermöglicht die MISO-Leitung (Master In Slave Out) den Slaves, Daten an den Master zu senden. Die SCLK-Leitung (Serial Clock) überträgt den Takt vom Master an die Slaves, wodurch eine synchronisierte Datenübertragung möglich wird. Die SS/CS-Leitung (Slave Select/Chip Select) wird für jedes Slave-Gerät separat verwendet, um es auszuwählen und die Kommunikation mit dem Master zu initiieren.

Abbildung 17 SPI-Bus CLK-Konfiguration (https://edistechlab.com/wp-content/uploads/2020/11/Screenshot-2020-11-22-at-09.37.57.png)

Des Weiteren muss eine Synchronisation des Protokolls geeinigt werden, welche mit der CLK-Leitung gewählt wird. Dadurch ist es möglich den Zeitpunkt der Datenübertragung, welche durch fallende oder steigender Flanke, sowie des aktiven Zustandes (LOW/HIGH) zu konfigurieren.

Abbildung 18 SPI-Bus Kommunikation (https://edistechlab.com/wie-funktioniert-spi/?v=fa868488740a)

Die Kommunikation erfolgt durch das gleichzeitige Senden und Empfangen von Daten, in einem vorher festgelegten Taktzyklus. Zuerst wird mit der CS-Leitung bestimmt, ob der Master oder der Slave senden darf. Danach kommt es auf die Konfiguration des Clocksignal an, in welcher bestimmt wird, wann die Daten übertragen werden. Als letztes werden die Daten über der MOSI- oder MISO-Leitung Bit für Bit in Serie versendet.

### 6.4.5 In-System-Programming Hardware-Setup

XXX

### 6.4.6 Pierce-Oszillator

Da für die Inbetriebnahme des Mikrocontrollers ein Taktsignal benötigt wird, ist eine Oszillatorschaltung notwendig. Mit den Informationen aus dem Datenblatt wird ein Quarzoszillator dazu gebaut, der den ATMEGA2560 mit einem Rechtecksignal mit 16MHz versorgt.

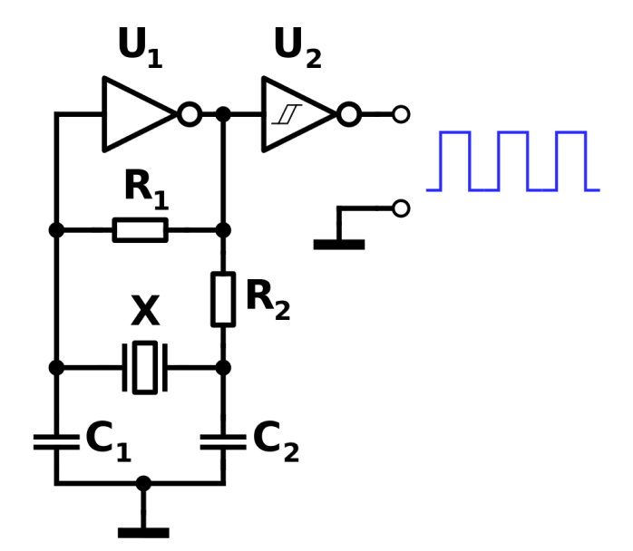
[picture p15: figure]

Abbildung 19 Schaltplan Pierce-Oszillator (https://de.wikipedia.org/wiki/Quarzoszillator)

Die Bauteile sind essentiell, um die Erzeugung und Stabilisierung der Taktfrequenz zu sichern. Der Quarz fungiert als frequenzbestimmendes Element, indem er aufgrund seiner piezoelektrischen Eigenschaften Schwingungen erzeugt, die als präzise Taktfrequenz dienen. Die Kondensatoren sind in der Regel parallel zum Quarz geschaltet. Sie dienen dazu, die nötige Kapazität für die Schwingungsbildung des Quarzes bereitzustellen. Die Kondensatorwerte von 22pF wurden gemäß den Angaben im Datenblatt ausgewählt, das die Gleichheit der Kapazitäten für beide vorschrieb. In einigen Schaltungen werden Widerstände parallel zu den Kondensatoren geschaltet, um die Impedanz des Oszillators zu beeinflussen. Die Widerstände können dazu beitragen, die Schwingungsfrequenz zu stabilisieren und unerwünschte Schwingungsmoden zu unterdrücken. Der Inverter U1 erzeugt eine um 180° phasenverschobene Ausgangsspannung, die für die positive Rückkopplung und Stabilisierung der Schwingungen im Oszillatorkreis, insbesondere bei Verwendung eines Quarzresonators, entscheidend ist. Der Schmitt-Trigger dient dazu, das Ausgangsignal des Oszillators zu stabilisieren und sicherzustellen, dass das Signal sich im Pegelbereich des Mikrocontroller befindet. Beim ATMEGA 2560 ist der Großteil der Oszillatorschaltung im IC implementiert, daher sieht die Beschaltung wie folgt aus:

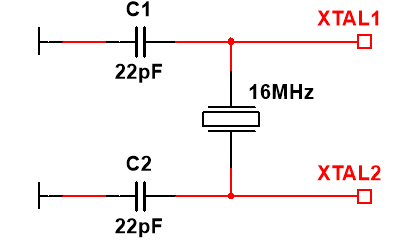
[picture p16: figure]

Abbildung 20 Oszillatorschaltung beim ATMEGA2560

Da der Mikrocontroller mit einer Taktfrequenz von 16MHz arbeitet, wird ein Quarz mit diesem Wert eingebaut. Die Pins XTAL1 und XTAL2 stellen hierbei die Anschlüsse des im IC eingebauten Oszillator da. Die Frequenz kann somit mit dem Wert des Quarzes gewählt werden.

## 6.5 Hardware-Design Roboter Revision B

Aufgrund der funktionierenden Schaltung im Kapitel 7.3 Hardware-Design Roboter Revision A wird der Entwicklungsplan konsequent umgesetzt. und ein Nachfolger der Roboterschaltung mit Verbesserungen entworfen. Es wird eine Weiterentwicklung der Roboterschaltung mit gezielten Verbesserungen konzipiert, wobei diese als zusätzliche Features integriert werden, ohne die grundlegende Fahrzeugsteuerung zu beeinträchtigen. Die primäre Zielsetzung besteht darin, den Roboter aufzuwerten. Die implementierten Erweiterungen sind im nachfolgenden Blockschaltbild detailliert dargestellt:

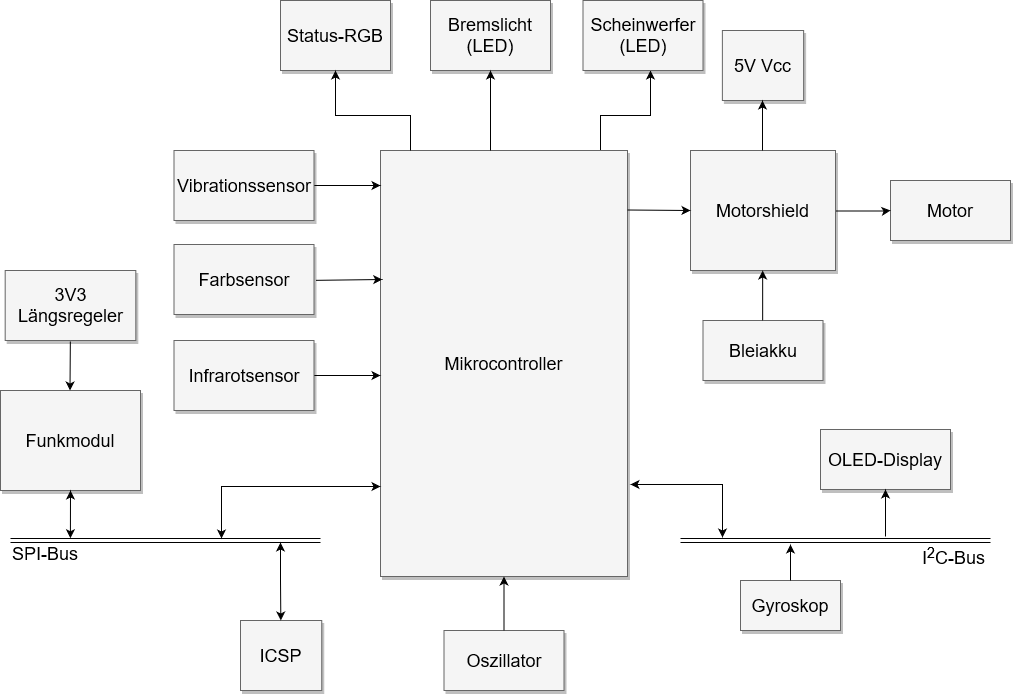
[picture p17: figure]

Abbildung 21 Blockschaltbild von Roboter Rev B V1.00

Wie bereits in der vorherigen Version bleiben die Grundkomponenten (Motoransteuerung, Funkmodul, Oszillator), welche für das Ansteuern des Fahrzeugs benötigt werden unverändert. Allerdings wird der Logik-Pegel-Wandler nicht mehr verwendet, da dieser für den Datentausch zwischen den Funkmodul und dem Mikrocontroller nicht notwendig ist. Der genaue Grund für diese Entscheidung wird im Kapitel 7.3.2 Roboter Revision A V1.00 Erkenntnisse beschrieben. Um dem Roboter autonomes Fahren zu ermöglichen, werden Infrarotsensoren integriert. Diese Sensoren ermöglichen es dem Fahrzeug, Hindernisse eigenständig zu umfahren, ohne dabei von der Steuerung beeinflusst zu werden. Zu diesem Zweck werden drei Infrarotsensoren eingebaut, um eine präzise Erfassung der Umgebung sicherzustellen. Ergänzend dazu wird ein Farbsensor integriert, der es dem Roboter ermöglicht, Farben in seiner Umgebung zu erkennen und darauf zu reagieren. Dadurch sollen einprogrammierte Software-Funktionen ausgeführt werden. Darüber hinaus wird im Fahrzeug ein Vibrationssensor eingebaut, der bei intensiven Bewegungen des Roboters ein HIGH-Signal an den Mikrocontroller sendet. Auch mit diesem Sensor können Softwareprogramme aufgerufen werden. Zusätzlich ermöglicht ein Gyroskop eine Messung der Geschwindigkeit, welches durch ein 3-Achsen Accelerometer die Messwerte ermittelt. Des Weiteren ist dieser in der Lage die Temperatur seines Umfelds zu erfassen. Die Kommunikation mit dem Mikrocontroller erfolgt über den integrierten I²C-Bus. Hierfür wird ein OLED-Display eingebaut, das durch einen Softwarealgorithmus auf Sensoren reagiert. Zusätzlich empfängt das OLED-Display Informationen über den I²C-Bus. Um den Roboter mit zusätzlicher Unterhaltungselektronik auszustatten, werden LEDs als Scheinwerfer- und Bremslichter eingebaut. Die Software wird darauf zugreifen und die entsprechenden LEDs aktivieren, abhängig von der Fahrtrichtung des Roboters.

### 6.5.1 Roboter Revision B V1.00 PCB

Das Blockschaltbild, wie in 7.5 Hardware-Design Roboter Revision B dargestellt, wurde erfolgreich in KiCAD als Schaltplan und Platinenlayout umgesetzt. Wie bereits bei seinem Vorgänger wird für die Produktion dieses PCBs auf dem externen Dienstleister Aisler zurückgegriffen.

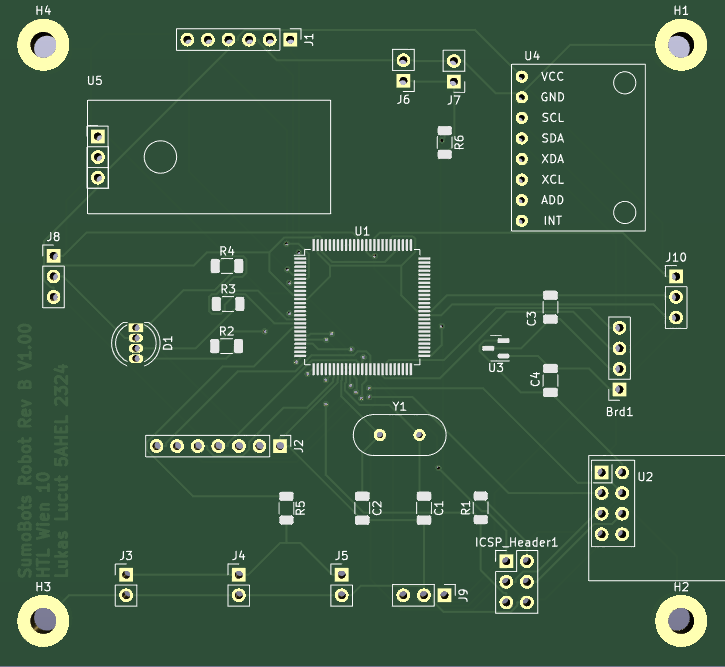
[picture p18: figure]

Abbildung 22 Roboter Rev B V1.00 PCB

Durch die gewonnenen Erkenntnisse im Fachbereich SMD-Löten wurde der damit verbundene Risikofaktor eliminiert, was es ermöglichte, die Platine mit kleineren Abmessungen zu dimensionieren. Zusätzlich zu den implementierten Sensoren befinden sich nun mehrere Bauteile auf der Platine. Einige dieser Bauteile, wie das OLED-Display, LEDs, Funkmodul und Farbsensor, müssen am Gehäuse des Roboters befestigt werden, um ihre Funktion sicherzustellen. Diese wurden auf einer Lochrasterplatine verlötet und mit Drähten an der Hauptplatine angeschlossen, weshalb sie als Pinheader auf dem PCB realisiert wurden. Dies führte dazu, dass die Positionierung dieser Bauteile ein zu berücksichtigender Faktor während des Designs wurde.Aus diesem Grund wurden die LEDs J6 & J7, die als Scheinwerfer fungieren sollen, an der Vorderseite des PCB positioniert. Gleiches gilt für die LEDs J3 & J4 & J5, die als Bremslichter dienen sollen. Die RGB-LED bleibt auf der Hauptplatine, da sie dazu dient, das Debuggen zu erleichtern. Der Farbsensor wird an der Unterseite des Robotergehäuses angebracht, um während der Fahrt die darunter liegenden Farben zu erkennen. Der Vibrationssensor und das Gyroskop werden hingegen auf der Platine befestigt, da sie aufgrund ihrer einstellbaren Sensitivität auf ruckartige Bewegungen reagieren würden und somit eine präzise Messung gewährleisten sollen. Zusätzlich wurden die Bohrlöcher, durch die die Platine am Gehäuse befestigt wird, mit der Masse verbunden.

### 6.5.2 Roboter Revision B V1.00 Erkenntnisse

Noch nicht da ☹

## 6.6 Komponenten des Roboters Revision B

In diesem Abschnitt werden die Erweiterungen des Roboters in Revision B im Detail erläutert. Da die bereits in Revision A verbauten Bauteile in Kapitel in Kapitel 7.4 Komponenten des Roboters Revision A beschrieben wurden, wird hier auf eine erneute Beschreibung verzichtet.

### 6.6.1 I²C-Bus

xxxx

### 6.6.2 OLED Display XXX

Xxx

### 6.6.3 Vibrationssensor SW-420

Das SW-420 Vibrationssensor-Modul besteht aus einem SW-420 Vibrationsschalter und einem LM393 Spannungsvergleicher. Im SW-420 Vibrationsschalter befinden sich eine Feder und ein Stab innerhalb eines Rohres. Bei auftretenden Vibrationen kommt es zum Kontakt zwischen der Feder und dem Stab, wodurch der Stromkreis geschlossen wird. Der integrierte Vibrationssensor im Modul erfasst diese Schwingungen und wandelt sie in elektrische Signale um. Der LM393 Komparator vergleicht diese Signale mit einer Referenzspannung, die über den Trimmer eingestellt wird. Wenn die Amplitude des Signals die Referenzspannung überschreitet, gibt der Komparator ein HIGH-Signal aus, andernfalls ein LOW-Signal. Auf der Platine befinden sich auch LED-Anzeigen für die Stromversorgung und den digitalen Ausgangsstatus. Es hat eine einfache und klare 3-Pin-Schnittstelle: VCC, GND und DO (digitaler Ausgang). Es unterstützt eine Stromversorgung von 3,3V oder 5V. Dieses Modul ist mit jedem Mikrocontroller kompatibel, der über einen digitalen Eingang verfügt. Daher sind natürlich auch beliebte Mikrocontroller wie PIC, Arduino und Raspberry Pi kompatibel.

Abbildung 23 Vibrationssensor SW-420 (https://www.canadarobotix.com/products/1886)

### 6.6.4 Infrarotsensor XXX

Xxx

### 6.6.5 Gyroskop MPU6050

Der MPU6050 – Sensor verfügt über ein 3-Achsen Accelerometer, ein 3-Achsen Gyroskop und einen Temperatursensor. Der MPU6050 besitzt intern einen eigenen DMP (Digital Motion Processor). Der DMP wurde ausgelegt für Sensorfusion und Bewegungserkennung. Der Prozessor kombiniert die Daten des Accelerometer und des Gyroskop, um Fehler innerhalb der einzelnen Sensoren zu minimieren. Er kann die Daten außerdem verrechnen und das Ergebnis in Euler-Winkel umrechnen. Der Algorithmus, auf welche Weise die Daten kombiniert werden, wird vom Hersteller Invensense nicht offen gelegt. Die Daten werden über den I2C – Bus eingelesen. Im Sensor befinden sich MEMS (= „Micro-Electrical-Mechanical Systems“). Das sind winzige elektro-mechanische Systeme die billig und in Masse produziert werden können.

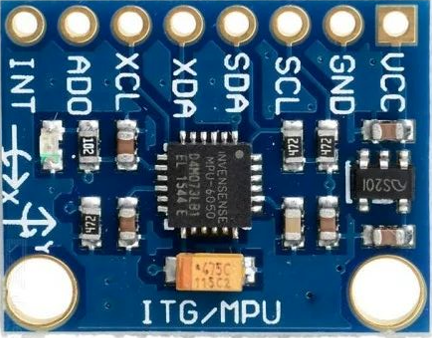
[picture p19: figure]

Abbildung 24 Gyroskop MPU6050

Im rechten Bild von Abb. 9 drückt die Beschleunigung nach links die mittlere Kondensatorplatte näher zur rechten. Das verändert die Kapazität zwischen den Platten. Misst man die Kapazitäten kann man so auf die Beschleunigung rückschließen.

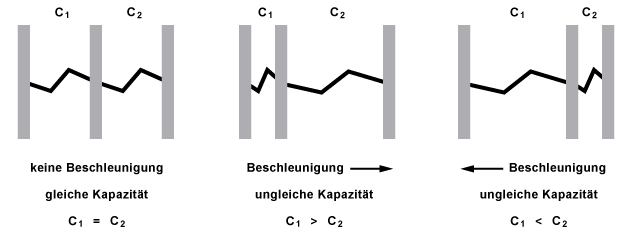
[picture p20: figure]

Abbildung 25 Funktionsweise des Accelerometers (https://www.elektronik-kompendium.de/sites/bau/1503041.htm)

Der Accelerometer misst Beschleunigungen entlang der x, y, z-Achsen, während das Gyroskop Geschwindigkeiten um die x,y,z – Achsen misst.

## 6.7 Hardware-Design Controller

Die Steuerung des Roboters erfolgt über einen eigens dazu entwickelten Controller. Der Controller verfügt über zwei Joysticks, mit dem der Roboter hinsichtlich der Bewegung gesteuert werden kann. Zusätzlich……(welche weiteren Funktionen ?)

Die Daten, die von den Bedienelementen des Controllers durch den uC erfasst werden, werden mittels des Funkmoduls NRF24L01+ zum Receiver, welcher hierbei der Roboter ist, übertragen.

xxxxxBlockschaltbildxxxxxx

Als Mikrocontroller wird der ATMEGA328p genutzt, welcher für die Nutzung des Controllers ausreichend ist. Das Taktsignal wird durch einen externen Quarzoszillator mit 16MHz generiert, der die Geschwindigkeit der Programmabläufe beeinflusst.

Die Platine wird mit 4,5V betrieben, die durch drei 1,5V AAA-Batterien zustande kommen.

Die Spannungsversorgung wird mit einem Schalter getrennt, der ein Ausschalten der kompletten Hardware ermöglicht. Des Weiteren wird eine 3.3V Spannungsquelle benötigt, um das Funkmodul NRF24L01+ in Betrieb zu nehmen. Da der Controller als Transmitter fungiert ist kein Logik-Pegel-Konverter notwendig und kann das Funkmodul direkt mit den Pins des SPI-Bus verbunden werden. Der ATMEGA328p wird mit einem Sockel in die Schaltung integriert und wird für die Programmierung in einem Arduino UNO Evaluierungsboard eingesteckt. Daher wird die Schaltung nicht über den SPI-Bus programmiert und kein ICSP-Header wird benötigt.

Um die Fahrrichtung des Roboters ändern zu können, wird ein Joystick eingebaut, welcher einen Widerstandswert besitzt und von den Analog-Digital-Converter des Mikrocontrollers zu einem Wert bis 1024 konvertiert, da dieser eine Auflösung von 10 Bit besitzt. Des Weiteren besitzt der Joystick einen eingebauten Pushbutton, mit welchen XXXnoch fehlende FunktionXXX.

xxxxxTriggerfunktionxxxx

## 6.8 Hardware-Komponenten Controller

### 6.8.1 xxxTriggerxxx

### 6.8.2 Joystick

Die Fahrtrichtung des Roboters wird mittels eines 2-Achsen-Joysticks bestimmt, der sich in allen Richtungen bewegen lässt. Dieser besitzt jeweils einen Potentiometer für die X- und Y-Achse, welche als veränderbare Spannungsteiler fungieren.

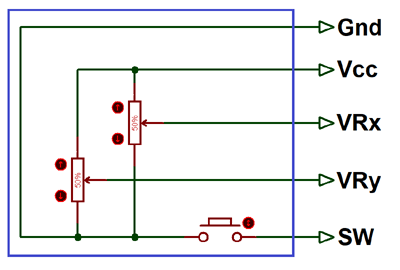
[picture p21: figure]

Abbildung 26 Joystick Schaltplan

Um die Daten des Spannungsteilers auslesen zu können, müssen die Pins VRx und VRy an den ADC-Pins des Mikrocontrollers verbunden sein. Dafür muss der Joystick zunächst mit 5V versorgt werden, da ansonsten unerwünschte Fehler beim Konvertieren auftreten könnten. Des Weiteren bietet der Joystick einen eingebauten Taster an, der eine logische „0“ oder „1“ ausgibt, daher wird der Pin SW an einem digitalen Pin angeschlossen.

< BILD : Verbindung Arduino Joystick >

# 7 Softwareentwicklung

In diesem Kapitel wird die Softwareentwicklung, für dieses Projekt, erklärt. Das reicht von: „Wie laden wir den Code hoch?“, „Wie dokumentieren wir Änderungen an den Codes?“,
„Wie benennen wir Variablen und Funktionen“ bis hin zu „Wie funktioniert der Code, was soll er tun?“

Alle Codes die in diesem Kapitel verwendet werden, sind an C angelehnte „Pseudocodes“. Diese sind nicht in einer Programmiersprache verfasst und sollen nur die Funktionsweise des tatsächlichen Codes erklären. Dabei können gewisse Funktionsaufrufe, Variablendeklarationen, Typecasting und andere Kleinigkeiten, die der Erklärung der eigentlichen Funktionsweise des Codes im Weg stehen könnten, ausgelassen werden. Teilweise wird auf diese Kleinigkeiten in Fußnoten eingegangen. Im Anhang ist allerdings eine gut kommentierte Version der tatsächlich verwendeten Codes zu finden.

## 7.1 Konzept, Programmierung und Debugging

### 7.1.1 Konzept

Grundsätzlich beinhaltet das Projekt drei separate Codes die alle mit RF24 – Funkmodulen miteinander kommunizieren:

1) Der Controller, welcher Buttons einlesen und an den Roboter weiterschicken soll.

2) Der Roboter, welcher Daten des Controllers engegenehmen soll, Motoren ansteuern soll und Sensordaten an den Server weiterschicken soll und

3) Der Server, welche Sensordaten des Roboters entgegennehmen soll.

Da wir den µC eines Arduinos verwenden, kann in der gewöhnlichen Arduino-Umgebung programmiert werden. Versioniert und gespeichert werden die Programmie mithilfe von GitHub. Ein Link zum Repository ist im Anhang zu finden. XXX noch nicht

### 7.1.2 Programmierung und Debugging

In diesem Kapitel wird der Style Guide definiert und die Weise, wie wir den Code hochladen und Textnachrichten vom µC bekommen erklärt. Der Roboter und Controller verwenden jeweils den atMega2560 und atMega328p µC. Das sind beides µC die für verschiedene Arduino Boards verwendet werden, weshalb für die Softwareentwicklung die gewöhnliche Arduino Umgebung verwendet werden kann. Ein gewöhnliches Arduino-Board wird mit einem USB – Kabel mit dem Computer verbunden. Ein zweiter µC ermöglicht „Serial over USB“ also eine (virtuelle) serielle Verbindung über die USB – Schnittstelle. Auf dem Arduino läuft ein Bootloader, ein kleines Programm welches beim Hochfahren des Arduinos startet, und das Programmieren über die Serielle Verbindung ermöglicht. Über diese können auch Debug – Nachrichten an den Computer übertragen werden. Wir haben allerdings weder den zweiten µC noch den Bootloader, da wir die µC direkt vom Händler kaufen. Deshalb mussten für Programmierung und Debugging andere Methoden verwendet werden, die folgend näher beschrieben werden.

### 7.1.3 In-System-Programming über SPI-Bus

Um Funktionalitäten von Arduino-Boards verwenden zu können schalten wir für Programmierung und Debugging einen zweiten Arduino dazwischen, wie folgt:

Abbildung 27: Blockschaltbild In-System-Programming

Programmiert kann der µC über den SPI – Bus werden. Für diesen Zweck haben Arduinos einen veränderten SPI - Bus am ICSP[^1] – Header ausgeführt:

Abbildung 28: ICSP – Header der Arduinos

Verändert, weil statt dem üblichen „Slave Select“, der „Reset“ Pin ausgeführt ist. Auf unserem PCB ist der gleiche Header implementiert.

Das Programmieren erfolgt wie folgt:

1. Zunächst muss das Programmierer-Board selbst den Code „Programmer.ino“ hochgeladen bekommen.
2. Danach kann man die von uns erstellten ICSP – Stecker miteinander verbinden. Der Stecker mit zusätzlichem Jumper-Draht wird auf die ICSP - Schnittstelle des Programmierer-Boards angesteckt, das zusätzliche Kabel auf Pin 10. Dieser ist mit Pin 5: „reset“ verbunden. Die andere Seite wird auf das ICSP – Interface des zu programmierenden Boards angesteckt. Die schwarz angemalte Seite zeigt nach oben, ist also näher an Pin 1 der Schnittstelle.
3. Nun kann das Programm hochgeladen werden. Als Board wird „Arduino Mega2560“ ausgewählt, als Programmer „ArduinoISP“ und „Upload with Programmer“ betätigt.
    5.1.4. Debugging over Serial

Für das Debugging müssen einfach nur die seriellen Schnittstellen von µC und Arduino verbunden werden. Der Computer bekommt dann die Nachrichten des µC, als würden sie vom Arduino kommen.

### 7.1.4 Versionsverwaltung und Style – Guide

Jedes Programm bekommt einen Header, in folgender Form:

/**

* Author: Author

*

* Desc: Kurzbeschreibung des Programms

*/

### 7.1.5 Variablen- und Funktionsnamen

Alle Variablen und Funktionen sind Englisch[^2] und im „Camel case“ benannt. Statt einem Abstand wird also das nächste Wort großgeschrieben (z.B. doDebug). Konstanten beginnen mit einem Großbuchstaben.

Alle Pinnummern beginnen mit p_. Einige Wörter werden so oft verwendet, dass sie mit einzelnen Buchstaben abgekürzt werden dürfen:

l … left, r … right

b … backwards, f … forwards

Die Reihenfolge ist Left / Right dann Backwards / Forwards. Der Pin, mit dem der Rechte Motor nach vorne angesteuert werden kann heißt somit:

p_rf

In den Pseudo-Codes der Diplomarbeit sind diese Wörter der Klarheit halber oft ausgeschrieben.

## 7.2 Software-Design Controller

In diesem Kapital wird der Code des Controllers erklärt. Dieser soll die elektronische Komponente auslesen, die Daten kurz verarbeiten und anpassen, um diese dan an den Roboter weiterzusenden. Um den Status zu erkennen, soll eine Status-LED angesteuert werden.

### 7.2.1 Ansteuerung der Status-LED

Die ersten Zeilen im Code des µC schalten die LED ein. Das zeigt 1) das der richtige Code hochgeladen ist und 2) das der µC mit Strom versorgt ist. Danach wird das Funkmodul gestartet und es wird versucht, ein Paket an den Roboter zu senden. Wird diese angenommen, blinkt die LED kurz auf und leuchtet dann wieder konstant. Somit kann auf einem Blick erkannt werden, ob eine Verbindung hergestellt wurde.

### 7.2.2 Auslesen der Elektronik

Der Controller muss die verschiedenen elektrischen Komponenten, also den Joystick und die Schultertasten auslesen und an den Roboter weiterschicken. Unabhängig von der Hardware wurden die Wertebereiche in Kapitel 8.4.2 definiert. Die Schultertasten entsprechen diesem Standard bereits, der Wertebereich des Joysticks muss jedoch darauf angepasst werden. (XXX richtiger code in lukas laptop)

array[0] = analogRead(p_joyX)

array[1] = analogRead(p_joyY)

array[2] = analogRead(p_lSchoulder)

array[3] = analogRead(p_rShoulder)

radio.write(array)

“radio.write()” verwendet das Funkmodul, um diese Daten an den Roboter zu senden. Die Ansteuerung des Funkmoduls wird im Kapitel 8.4.1 genauer beschrieben.

## 7.3 Software-Design Roboter

In diesem Kapitel wird der Code des Roboters erklärt. Dieser soll Daten des Controllers empfangen, und damit die Motoren ansteuern. Um den Status zu erkenn soll eine RGB-LED angesteuert werden.

### 7.3.1 Ansteuerung der Status-LED

Die ersten Zeilen im Code des µC schalten die LED auf Rot. Das zeigt, dass 1) der richtige Code hochgeladen ist und 2) dass der Roboter mit Strom versorgt ist. Danach wird das Funkmodul gestartet und es wird versucht, ein Paket vom Controller zu empfangen. Ist das geschehen, blinkt die LED kurz auf und leuchtet dann konstant grün. Somit kann auf einem Blick erkannt werden, ob eine Verbindung hergestellt wurde.

### 7.3.2 Berechnung der Motorsteuerung

Als Input – Größen bekommt der Roboter die Position des Joysticks und der zwei Schultertasten. Die Ansteuerung der Motoren wird anhand dieser berechnet. Die Schultertaste bestimmt die Geschwindigkeit der Motoren, das Verhältnis zwischen den Motoren bleibt aber unverändert. Je nachdem ob die rechte oder linke Schultertaste gedrückt wird, fährt der Roboter nach vorne oder hinten. Es wird der Wert der stärker gedrückten Schultertasten verwendet. Durch die Wrapper – Funktion, auf die später noch eingegangen wird, laufen Motoren durch negative Werte rückwärts. Die linke Schultertaste gibt also dieselbe Magnitude, aber ein negatives Vorzeichen.

Damit kommen wir auf folgenden Code:

if (rSchulter > lSchulter)

speed = rSchulter

else

speed = -lSchulter

lMotor = lMotorTurn * speed

rMotor = rMotorTurn * speed

lMotorTurn und rMotorTurn geben das Verhältnis zwischen linkem und rechtem Motor an. Sie sind also Variablen, die von -1 bis 1 gehen und sich aus der x-Achse des Joycons berechnen lassen.

Nimmt man an, das „joyX“ eine floating-point-Zahl ist, die von -1 (ganz links) bis +1 (ganz rechts) geht[^3], kommen wir auf folgendes Diagramm:

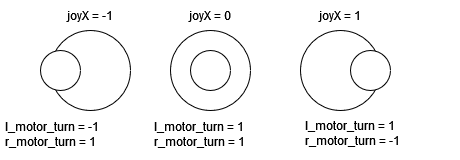
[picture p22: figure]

Abbildung 29: Diagramm für Veranschaulichung der Berechnung von motorTurn Werten

Ist der Stick ganz links positioniert, soll der Roboter sich im Stand nach links drehen. Deshalb soll sich die linke Kette Rückwärts und die rechte vorwärts bewegen. Die Anderen Positionen können mit einer ähnlichen Argumentation verstanden werden. Zwischen diesen Extrempositionen sollen die Variablen kontinuierlich und linear alle Zwischenwerte einnehmen. Mittels map – Befehl[^4] werden diese Wertebereiche aneinander angepasst.

if (joyX < 0) {

l_motor_turn = map(joyX, -1, 0, -1, 1)

r_motor_turn = 1

}

else if (joyX >= 0) {

l_motor_turn = 1

r_motor_turn = map(joyX, 0, 1, 1, -1)

}

lMotor = lMotorTurn * speed

rMotor = rMotorTurn * speed

Steuert dieser Code die Motoren direkt an und falls der Fahrer nicht vorsichtig ist und schnelle Richtungsänderungen vornimmt, kann das die Motorbrücke überlasten (XXX Erklärung im Hardware teil?). Deshalb sollen diese Änderungen nur langsam übernommen werden. Der Controller ändert nur die „_soll Werte“, tatsächlich an das Motorshield weitergegeben werden die „_ist Werte“. Sind ein Soll-Wert und Ist-Wert nicht gleich, wird der Ist-Wert nur einen Schritt Richtung Soll-Wert verändert.

lMotor_soll = lMotorTurn * speed

if (lMotor_ist > lMotor_soll)

lMotor_ist -= 1

else if (lMotor_ist < lMotor_soll)

lMotor_ist += 1

Dieser Code gilt genauso für den rechten Motor.

### 7.3.3 Ansteuerung des Motorshields

Wie die Motorbrücke funktioniert wurde im Kapitel 7.4 bereits genauer beschrieben, wird hier aber noch einmal zusammengefasst. Er hat für beide Motoren zwei Pins die ein PWM – Signal akzeptieren; eins, falls sich der Motor nach vorne drehen soll, eins falls sich der Motor rückwärts drehen soll. Diese Ansteuerung wurde, wie oben bereits erwähnt, durch eine Wrapper – Funktion „versteckt“ werden. Diese könnte auf unterschiedliche Weise designed werden, es wurde aber beschlossen, dass sie für rechten und linken Motor Werte von -255 bis 255 akzeptieren soll. Negative Werte stehen hier für einen sich rückwärts-drehenden Motor. Wie man im vorherigen Kapitel erkennen konnte, macht das die Mathematik ein wenig bequemer.

In der Funktion muss dann nur abgeprüft werden, ob der Wert negativ oder positiv ist, und je nachdem auf den Vorwärts- oder Rückwärtspin der absolute Wert[^5] des Arguments als PWM – Signal angelegt werden.

Wie im Kapitel XXX zu sehen ist der linke Motor des Roboters verkehrt herum eingebaut. Deshalb indem negieren wir den linken Wert und kehren somit seine Fahrtrichtung um.

drive(left, right) {

left = -left

if (left > 0) {

analogWrite(left_forward, |left|)

analogWrite(left_backward, 0)

}

else {

analogWrite(left_forward, 0)

analogWrite(left_backward, |left|)

}

}

Auch dieser Code gilt, abseits der Negation des Wertes, genauso für den rechten Motor.

### 7.3.4 Gyroskop – Code

Abbildung 30 Setup- Code für das Gyroskop

Am Anfang werden Wertebereiche des MPUs definiert. Der Accelerometer misst jetzt bis zu ± 8G also bis zu 78.4 m/s². Das Gyro ±500 °/s. setFilterBandwidth() setzt die Grenzfrequenz eines digitalen Filters, der Teil des Moduls ist. Ist die Grenzfrequenz niedriger wird über mehr Messdaten integriert. Das macht den Sensor langsam aber weniger „shaky“. Des Weiteren wurde das Modul zunächst kalibriert. Es wurde eine Messung im Ruhezustand getätigt und diese wurden von folgenden Messungen abgezogen. Das lässt Gravitation und Potentielle Sensor-Drifts wegfallen. Dann wurden die absoluten Werte aller Sensoren addiert und ausgegeben.

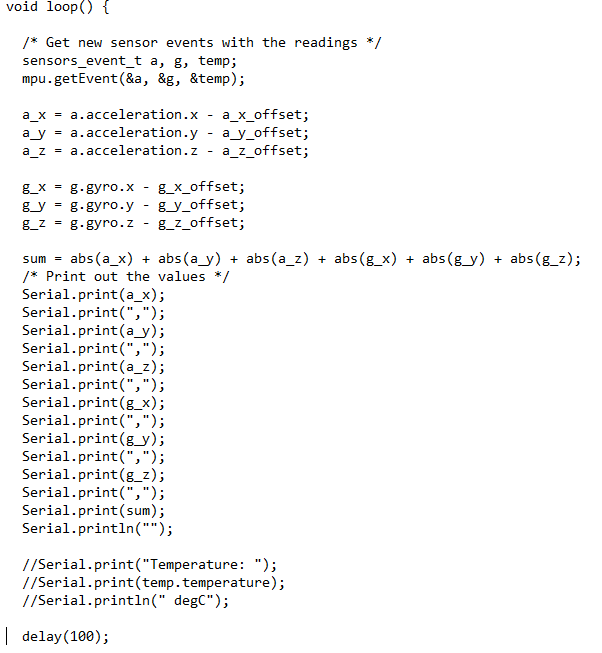
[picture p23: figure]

Abbildung 31 Main-Loop für Gyroskop

Im Zuge der Recherche fiel jedoch auf, dass hier lineare Beschleunigungen einfach mit Winkelgeschwindigkeiten addiert werden, was nur bedingt Sinn macht. Für einen sehr groben Richtwert genügt es jedoch.

### 7.3.5 Einstellen des Timers

Der Timer soll eingerichtet werden, um einen periodischen Interrupt alle 150ms zu erzeugen. In der dazugehoerigen Interrupt Service Routine werden Sensoren eingelesen und die eingelesenen Daten an den Server weitergeleitet.

### 7.3.6 Debug - Mode

Um das Projekt debuggen zu können wurde ein Debug – Mode implementiert. Der Roboter bekommt die Daten des Controllers, steuert aber nicht die Motoren an, sondern gibt die vom Controller kommenden Daten und die sich ausgerechneten Daten an den Serial Monitor aus. Dieser besteht also nur aus einer if – Anweisung und einer Reihe an „Serial.print“ befehlen vor dem Wert wird der Name des Wertes und sein Wertebereich angegeben.

if (doDebug) {

Serial.print("X: ")

Serial.println(inputs[0])

Serial.print("Y: ")

Serial.println(inputs[1])

…

}

## 7.4 Networking

Es gibt drei verschiedene Komponente, die über das im Kapitel XXX beschriebene Funkmodel miteinander kommunizieren. Außerdem sollen beliebig Viele Roboter miteinander kommunizieren können.[^6] Das daraus resultierende Netzwerk kann durch folgendes Diagramm veranschaulicht werden:

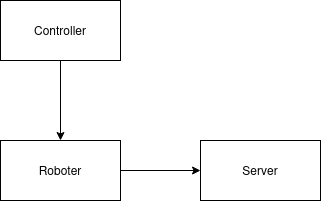
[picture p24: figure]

Abbildung 32: Blockschaltbild der Netzwerkarchitektur

Der Controller schickt dem Roboter die (verarbeiteten) Zustände des Joysticks und der Schultertasten. Der Roboter schickt dem Server im 250ms Takt Daten seiner verschiedenen Sensoren.

### 7.4.1 Initialisierung des Moduls

Software-seitig verwenden wir für die Ansteuerung des Funkmoduls die dazugehörige Library “nRF24L01.h”. Einige der anfänglichen Befehle zur Initialisierung des Moduls bleiben bei allen Komponenten gleich.

RF24 radio(p_CE, p_CSN);

radio.begin();

Der Sender, startet eine „Pipe“ also eine Verbindung mit einem anderen Modul mit “radio.openWritingPipe(address)”, der Empfänger mit “radio.openReadingPipe(n, address)“. Jedes Modul kann eine Writing-pipe und 6 Reading-pipes offen haben. Es kann also einem Modul schreiben, aber Daten von 6 anderen Modulen empfangen. Jede Pipe muss einer Unterschiedlichen Adresse zugeteilt werden. Um zwischen Schreib-Modus und Lese-Modus zu wechseln gibt es die Befehle “radio.stopListening()” und “radio.startListening()”.

radio.openReadingPipe(controllerAddress)

radio.startListening()

radio.read(inputData)

if ( 250ms passed ) {

radio.stopListening()

radio.openWritingPipe(serverAddress)

radio.write(sensorData)

radio.startListening()

}

Für die Verbindung zwischen Funkmodul und Roboter verwenden wir das nRF24L01+ Modul. Die elektrischen Charakteristiken sind im Kapitel XXX beschrieben, hier wird auf die Software-seitige Ansteuerung eingegangen. Das Modul wird angesteuert über die nRF24L01.h library.

(XXX Quelle: https://nrf24.github.io/RF24/classRF24.html#a025fcbad6f062d18252485c1d6ba574f)

### 7.4.2 Standard – Datenpakete

Zwischen Controller und Roboter werden Packete in folgender Form gesendet:

[lSchulter, rSchulter, joyX, joyY]

lSchulter 0 (losgelassen) … 255 (vollstaendig gedrueckt)

rSchulter 0 (losgelassen) … 255 (vollstaendig gedrueckt)

joyX -255 (ganz links) … 255 (ganz rechts)

joyY -255 (ganz unten) … 255 (ganz oben)

Zwischen Roboter und Server werden Pakete in folgender Form gesendet:

[sensor0, sensor1 , …]

(XXX wie viele und was für Sensoren wir haben noch nicht klar)

# 8 Projektmanagement

xxx

# 9 Bedienungsanleitung

# 10 Finale Ergebnisse

# 11 Tabellen und Abbildungsverzeichnis

# 12 Literaturverzeichnis und Quellenangaben

# 13 Anhänge

# 14 3D-Modelle und Konstruktionszeichnungen

# 15 Schaltpläne und PCB Designs

# 16 Programm-Codes

# 17 Mess & Labor-Protokolle

[^1] ICSP (= „In Circuit Serial Programming“), ist eine andere Abkürzung für ISP (= „In System Programming“) und meint das Programmieren eines µC, während dieser im System eingebaut ist.
[^2] Die einzigen Ausnahmen sind die _soll und _ist Suffixe.
[^3] Tatsächlich ist diese nach Kapitel 8.4.2 eine Integer-Zahl zwischen -255 und 255. Diese wird zuerst auf einen Float gecasted und dann durch 256 dividiert, um auf den Wertebereich [-1; 1] zu kommen.
[^4] Der Map – Befehl von Arduino verwendet nur Integer Mathematik. Deshalb ist im Code ein eigener floating-point-map Befehl implementiert. lMotor und rMotor werden dann wieder zurück auf einen Integer – Wert gecasted, um als PWM – Signal an das Motorshield weitergeleiten werden zu können.
[^5] Im Code wurde der Einfachheit halber, der positive Wert gelassen und der Negative negiert.
[^6] Tatsächlich sind wir dank technischer Limitationen des Funkmodul auf 6 Roboter begrenzt.

SumoBots Diplomarbeit 23/24

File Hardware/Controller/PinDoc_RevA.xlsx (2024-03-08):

Connector | Arduino-Pin | ATMEGA-Pin
Funkmodul
CSN | PB1 | 9
CE | PB2 | 10
Joystick
X-Achse | PC0 | A0
Y-Achse | PC1 | A1
Button | PD0 | 0
RGB
R | PD4 | 4
G | PD5 | 5
B | PD6 | 6
LCD-Display (I2C)
SDA | PC4 | A4
SCL | PC5 | A5
Trigger
Gas | PC2 | A2
Rückwerts | PC3 | A3
Buzzer 🤠
Dig | PB0 | 8

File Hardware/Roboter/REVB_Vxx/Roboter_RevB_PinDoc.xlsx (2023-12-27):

Connector | Arduino-Pin | ATMEGA-Pin
Funkmodul
CSN | 12 | PB6
CE | 13 | PB7
Motorshield
M1A | 5 | PE3
M1B | 2 | PE4
M2A | 3 | PE5
M2B | 4 | PG5
Gyroscope
SCL | 21 | PD0
SDA | 20 | PD1
OLED
SCL | 21 | PD0
SDA | 20 | PD1
SW-420 Vibrationsensor
DO | 46 | PL3
Farbsensor
S0 | 45 | PL4
S1 | 44 | PL5
S2 | 48 | PL1
S3 | 47 | PL2
OUT | 49 | PL0
Status-RGB
DO | 8 | PH5
VDD | 7 | PH4
DI | 6 | PH3
Bremslicht-LED
Dig | 9 | PH6
Scheinwerfer-LED
Dig | 41 | PG0
seitlicher Infrarotsensor_1
Vo | A12 | PK4
seitlicher Infrarotsensor_2
Vo | A8 | PK0
mittlerer Infrarotsensor
Vo | A10 | PK2

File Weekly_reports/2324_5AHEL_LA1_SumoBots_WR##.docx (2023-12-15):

Weekly Report XXX

Jahrgang/Klasse: 5AHEL
Übungsleiter: | Prof. Dipl.-Ing. Michael Zatl
Übungsdatum: | XXXXXX
Abgabedatum: | XXXXX
Gruppe: | SumoBots
Projektteilnehmer: | Lukas Lucut Yannick Zickler Bastian Eismann
Beurteilung:
Vermerke des Übungsleiters:

Inhaltsverzeichnis

# 1 Tätigkeiten

## 1.1 3D-Design und Konstruktion (EISMANN)

XXX

## 1.2 Hardware-Entwicklung (LUCUT)

XXX

## 1.3 Software-Entwicklung (ZICKLER)

XXX

# 2 Next Steps

## 2.1 3D-Design und Konstruktion (EISMANN)

XXX

## 2.2 Hardware-Entwicklung (LUCUT)

XXX

## 2.3 Software-Entwicklung (ZICKLER)

XXX

LABOR Seite 11 von 11

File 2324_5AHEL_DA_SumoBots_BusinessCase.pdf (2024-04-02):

# Businessplan SumoBots

## Jahrgang/Klasse: 5AHEL

Projektteilnehmer: | Lukas Lucut
| Yannick Zickler
| Bastian Eismann

Beurteilung:

Vermerke des
Übungsleiters:

### Executive Summary (LUCUT)

__________________________________________________________________________________

Diplomarbeit | Seite 1 von 10

## Inhaltsverzeichnis

### Executive Summary (LUCUT)

### 1 Executive Summary (LUCUT)

Geschäftsidee

In vielen höheren Schulen ist es eine Herausforderung für Professoren, Schüler für Technik zu begeistern. Oft sind Lernkits komplex gestaltet und erfordern ein gewisses Vorwissen oder Lehrerunterstützung, um sich in der Technik zurechtzufinden. Aus diesem Grund wird ein einfacher Fahrzeugroboter entwickelt, der speziell für den technischen Unterricht in Schulen konzipiert ist. Dieser Roboter wird mit klaren Anweisungen und einer Schritt-für-Schritt-Anleitung geliefert, um Schülern und Studenten praxisnahe Erfahrungen zu vermitteln.

Zielgruppe

❖ HTL mit Schwerpunkt im technischen Bereich ❖ Workshops für Technik
❖ AHS
❖ Interessierte Studenten bzw. Hobbybastler

Marktpotenzial

Das Marktpotenzial für SumoBots und verwandte Technologien ist bedeutend, da sie eine vielfältige Anwendungspalette haben und die steigende Nachfrage nach Robotertechnologien in Bildungseinrichtungen, Unterhaltungssektoren und der Industrie reflektieren, wobei spezifische Punkte wie das Wachstum im Bildungssektor und die Nutzung im Unterhaltungssektor hervorgehoben werden.

Kundennutzen

Durch die innovative Entwicklung und den einfachen Aufbau kann ein SumoBot problemlos von Lehrkräften, auch ohne Abschluss in technischen Studiengängen, im Unterricht eingesetzt werden, um bei Heranwachsenden das Interesse an Technik zu wecken.

Unique Selling Point

Aufgrund ihrer Entwicklung nach dem Technologiestandard des Jahres 2023/24 bieten SumoBots im Vergleich zu Konkurrenten wie Arduino mehr Möglichkeiten für die Umsetzung kreativer und innovativer Ideen, bleiben jedoch trotz des technologischen Fortschritts in derselben Preisklasse, was ihre erfolgreiche Positionierung im Markt unterstützt und Schulleiter oder Organisatoren an Universitäten dazu neigen lässt, sich für SumoBots anstelle der Konkurrenz zu entscheiden.

### Detailbeschreibung (LUCUT)

Meilensteine

### 2 Detailbeschreibung (LUCUT)

Die SumoBots sind eigenständig konstruierte und entwickelte Fahrzeugroboter, die mithilfe einer selbstentwickelten Fernsteuerung gesteuert werden können. Diese Fernsteuerung ermöglicht es, das Fahrzeug in einem Umkreis von bis zu 1 km zu steuern. Der Roboter ist mit diversen programmierbaren Sensoren ausgerüstet, die es ihm ermöglichen, in verschiedenen Umgebungen eingesetzt zu werden. Zusätzlich stellt das Projekt eine Open-Source-Programmierumgebung bereit, die es leichter ermöglichen, Software-Änderung durchzuführen.

### 3 Unique Selling Proposition USP (LUCUT)

Da die SumoBots gemäß dem Technologiestandard des Jahres 2023/24 entwickelt wurden, bieten sie im Vergleich zu ihren Konkurrenten, wie beispielsweise Arduino, mehr Möglichkeiten, kreative und innovative Ideen umzusetzen. Trotz des technologischen Fortschritts befinden sie sich in derselben Preisklasse, was ihnen ermöglicht, sich erfolgreich im Markt zu behaupten.

Basierend auf diesen Fakten würden Schulleiter oder Organisatoren an einer Universität sich eher für die SumoBots als für die Konkurrenz entscheiden.

### SWOT-Analyse (LUCUT)

### 4 SWOT-Analyse (LUCUT)

SWOT-Analyse | Interne Analyse
Stärken (Strenghts) | Schwächen (Weaknesses)
| Chancen (Opportunities) | Aufgrund der begrenzten Anzahl von Wettbewerbern kann das Produkt durch einen herausra-genden Qualitätsstandard eine wettbewerbsfähige Position auf dem Markt einnehmen. | Da bisher wenig Erfahrung auf dem internationalen Markt ge-sammelt wurden, kann das zu Problemen führen. Daher wird überlegt, das Produkt auf Social-Media erstmalig zu bewerben.
| Gefahren (Threats) | Die Optimierung der SumoBots durch Upgrades und die Erschlie-ßung neuer Marktsegmente stärken ihre Position gegenüber Konkurrenten und fördern lang-fristiges Wachstum. | Durch Fortbildung der Mitarbei-ter, um das Produkt aktuell zu hal-ten, beabsichtigt das Projekt, neue Märkte zu erschließen und das Produktangebot mit mehre-ren Modellen zu variieren.

Externe Analyse

### 5 Kundennutzen (LUCUT)

Das Angebot, die SumoBots als „Lernkit“ an technischen Universitäten und Höheren Technischen Lehranstalten einzusetzen, eröffnet eine vielversprechende Perspektive. Durch die Integration in den Lehrplan können Studierende im technischen Bereich nicht nur ihr theoretisches Wissen vertiefen, sondern auch ihre kreative Entfaltung fördern. Die SumoBots bieten eine innovative Plattform, die es den Studierenden ermöglicht, ihre Ideen in die Praxis umzusetzen und dabei programmierbare Sensoren sowie selbstentwickelte Fernsteuerungen zu nutzen. Diese praxisorientierte Herangehensweise stärkt nicht nur die technischen Fähigkeiten der Studierenden, sondern ermöglicht auch eine anwendungsbezogene Auseinandersetzung mit aktuellen technologischen Entwicklungen.

### Entwicklungsstand (EISMANN)

### 6 Entwicklungsstand (EISMANN)

Die ersten Prototypen der SumoBots wurden vor zwei Jahren fertiggestellt, um das Konzept und die Funktion für den zukünftigen Verlauf zu garantieren. Seitdem wurden mehrere funktionierende Prototypen und neue Versionen der SumoBots zum Test gebaut, um eventuelle Problembereiche und Konstruktionsschwächen zu erkennen. Der aktuelle Prototyp mit dem stand 2023/24 verfügt über eine neu entwickelte Elektronik, neue Sensoren, einen eigenen Server zur Verarbeitung der Sensordaten und einen neuen Gehäuseaufbau, der die Modularität der Roboter noch weiter fördern soll. Die ersten Konstruktionskonzepte des Controllers wurden begonnen, um die Elektronik- und Softwarekommunikation zwischen dem Controller und dem Roboter kontinuierlich zu testen und zu verbessern.

### 7 Schutzrecht (EISMANN)

Da die SumoBots als Lern- und Übungsroboter konzipiert sind, steht die Open-Source-Philosophie und Modularität im Vordergrund. Dies ermöglicht es den Kunden, die Technologie an verschiedene Lernszenarien oder Übungen anzupassen. Sowohl der Programmiercode als auch die Konstruktionspläne werden frei zur Verfügung gestellt. Durch diese Offenheit können Lehrer, Studenten und Entwickler die SumoBots an ihre spezifischen Bedürfnisse anpassen und anpassen, sei es durch die Implementierung neuer Funktionen, die Anpassung an unterschiedliche Lehrpläne oder die Integration in spezifische Projekte.

### 8 Marktvolumen (EISMANN)

In Österreich gibt es laut den Daten von 2022/23 etwa 1,5 Millionen Schüler, die auf insgesamt 5661 schulischen Einrichtungen verteilt sind. Davon befinden sich 996 im höheren Ausbildungsbereich, was als das Hauptmarktpotenzial für SumoBots angesehen werden kann. Es ist jedoch schwierig, das genaue Marktvolumen für SumoBots zu ermitteln, da es kein vergleichbares Angebot an Lernrobotern gibt, anhand dessen man die Zahlen genau einschätzen könnte. Dennoch deutet die beträchtliche Anzahl von Schulen und Schülern darauf hin, dass das Marktpotenzial für SumoBots erheblich ist und durch gezielte Marketingstrategien und die Bereitstellung innovativer Lösungen weiter ausgeschöpft werden kann.

### 9 Marktpotenzial/Marktvolumen (Zickler)

Das Marktpotenzial für Sumobots und verwandte Technologien ist signifikant, da sie eine breite Palette von Anwendungen und Einsatzmöglichkeiten bieten. Die steigende Nachfrage nach Robotertechnologien in Bildungseinrichtungen, Unterhaltungssektoren und der Industrie unterstreicht das wachsende Interesse an solchen Produkten. Einige spezifische Punkte könnten sein:

- Wachstum des Bildungssektors: Bildungseinrichtungen integrieren vermehrt Robotik und Technologie in ihre Lehrpläne, was die Nachfrage nach Lernrobotern wie Sumobots erhöht. Gerade in HTLs oder anderen Berufsbildenden Schulen könnte es Interesse geben.

### Marktsegmentierung (Zickler)

- Unterhaltungssektor: Sumobots bieten ein unterhaltsames Erlebnis für Menschen aller Altersgruppen und könnten in Freizeitparks, auf Messen oder bei Veranstaltungen eingesetzt werden.

### 10 Marktsegmentierung (Zickler)

Die potenziellen Zielgruppen für Sumobots können vielfältig sein:

- Bildungseinrichtungen: Schulen, Universitäten und Bildungszentren, die Robotik in ihren Lehrplan integrieren möchten.
- Freizeit- und Unterhaltungssektor: Freizeitparks, Veranstaltungsorganisatoren und Unternehmen, die nach einzigartigen Unterhaltungsmöglichkeiten suchen.
- Technologie-Enthusiasten: Einzelpersonen und Gruppen, die sich für Robotik, Programmierung und technische Innovationen interessieren.

### 11 Wettbewerbsanalyse (Zickler)

Direkte Konkurrenten:

Andere Sumobot-Hersteller: Es gibt bereits Unternehmen, die Sumobots herstellen und auf dem Markt anbieten. Diese Unternehmen könnten etablierte Produkte und einen bestehenden Kundenstamm haben. Außerdem ermöglicht hier Massenprodultion niedrigere Herstellkosten.

Markteintrittsbarrieren:

Technische Expertise: Die Entwicklung und Herstellung von Sumobots erfordert fundierte Kenntnisse in den Bereichen Robotik, Elektronik und Programmierung.

Ressourcen: Der Zugang zu Finanzierungsmöglichkeiten und Produktionskapazitäten könnte eine Hürde für neue Unternehmen sein.

Differenzierung zur Konkurrenz:

- Innovative Technologie: Unser Sumobot-System könnte sich durch fortschrittliche Sensortechnologie, präzise Steuerung und benutzerfreundliche Schnittstellen von anderen Produkten abheben.
- Einzigartige Funktionen: Die Integration von Funktionen wie automatischem Labyrinthfahren und Echtzeitdatenvisualisierung könnte unseren Sumobots einen Wettbewerbsvorteil verschaffen.
- Kundensupport und Schulungen: Wir könnten einen erstklassigen Kundensupport sowie Schulungen und Ressourcen für Lehrkräfte und Technologie-Enthusiasten anbieten.

### Produktpolitik (Zickler)

Positionierung am Markt:

- Unser Ziel ist es, hochwertige Sumobots anzubieten, die sowohl für Bildungseinrichtungen als auch für den Freizeit- und Unterhaltungssektor attraktiv sind.
- Wir streben danach, einen Ruf für Innovation, Zuverlässigkeit und erstklassigen Kundensupport aufzubauen.
- Durch kontinuierliche Produktverbesserungen und die Berücksichtigung der Bedürfnisse unserer Kunden möchten wir langfristige Beziehungen und Partnerschaften aufbauen.

### 12 Produktpolitik (Zickler)

Robotyping bietet anderen Unternehmen das Entwickeln, Testen und Bestellen von PCBs (=”Printed Circuit Boards”). Die bestellten PCBs können ebenfalls, für einen Aufpreis, bestückt werden. Sollte das Unternehmen das brauchen kann es bei uns auch Beratungen im Vorhinein beanspruchen.

### 13 Preispolitik (Zickler)

Da wir ein sehr individualisiertes Produkt anbieten, wird auch der erzielte Preis je nach Größe des Auftrags stark variieren müssen. Wir erwarten uns aber jedenfalls Preise im hohen 3 – bis 4 stelligen Bereich. Es kann während dem Testen des Auftrags zu unvorhergesehenen Komplikationen kommen. In Absprache mit dem Unternehmen können Änderungen am Produkt vorgenommen werden. Alle zusätzlichen Kosten die in diesem Fall anfallen werden von uns übernommen; Wir bieten somit eine Preisgarantie. Auch Qualität wird garantiert: sollte ein Fehler in unseren PCBs bis zu 3 Jahre nach Abschluss des Auftrags zu Komplikation geführt haben, erstellen wir kostenlos neue Platinen mit überarbeitetem Design.

### 14 Vertriebspolitik (Eismann)

### 15 Kommunikationspolitik (Eismann)

### Unternehmen und Management (Lucut)

### 16 Unternehmen und Management (Lucut)

Firmenname | SumoBots
Standort | Landgutgasse 53/3, Wien 1100
Gründungsdatum | 01.04.2024
Rechtsform | GmbH
Geschäftsführer | Lukas Lucut

Teammitglieder und deren Kompetenzen

Lukas Lucut | Hardware-Entwicklung, Team-Koordination
Bastian Eismann | 3D-Design und Konstruktion
Yannick Zickler | Software-Entwicklung, Planung
Unternehmensgegenstand | Ingenieurbüro

Externe Partner

Steuerberater | Wolfgang Waltner (https://www.waltner.at/Default.htm)
Lieferant | Aisler (https://aisler.net/)

Kooperationsverträge

Sponsoring der Bauelemente | Conrad

### Finanzierung (Zickler)

### 17 Finanzierung (Zickler)

Das Gründen einer GmbH benötigt ein Stammkapital von 10.000 EUR. Zu den Fixkosten im ersten Jahr zählt nur die Inneneinrichtung des Büros, was sich auf 3500 EUR beläuft. Da wir nur Schaltungen designen und bei anderen Firmen herstellen lasse, fallen hier keine zusätzlichen Kosten an. Dazu kommen laufende Kosten: ein Unternehmerlohn von 2.500 EUR netto also ca. 3.500 EUR brutto pro Person und Monat und eine Miete für das Büro von 700 EUR pro Monat. Insgesamt beträgt das 134.400 EUR die es pro Jahr zu decken gilt.

Gerade in den ersten Jahren müssen wir die Firma zu fast 100% aus Fremdkapital finanzieren. Das langfristige Ziel ist jedoch die 100% Eigenkapitalfinanzierung, mittelfristig nur 30%. Bevor das nicht erreicht wird, kommen neue Investitionen oder das Anstellen von weiterem Personal nicht in Frage.

Um ein Jahr vollständig finanzieren zu können, bräuchte es, je nach Größe des Auftrags, 130 bis 150 verschiedene Aufträge, da außerhalb der Miete und des Lohns keine weiteren Kosten anfallen. Für eine Eigenkapitalquote von 30% ca. 40 bis 45. Dieses mittelfristige Ziel soll zumindest innerhalb der ersten fünf Jahre erreicht werden.

### 18 Finanzierungsformen (Eismann)

Der Businessplan der SumoBots umreißt ein Projekt mit dem Fokus auf Technologie, Modularität, und Open-Source-Programmierumgebung wodurch sich das Angebot insbesondere an technische Universitäten und Höhere Technische Lehranstalten richtet. Angesichts dieser spezifischen Merkmale und des Zielmarktes können mehrere Finanzierungsformen in Betracht gezogen werden, um das Projekt Sponsoren. Es ist ratsam, eine Kombination dieser Finanzierungsquellen zu verwenden, um die Risiken zu diversifizieren und eventuellen Krisen vorzubeugen.

1. Eigenfinanzierung: Die Gründer könnten persönliche Ersparnisse einsetzen, um die ersten Phasen der Entwicklung und Markteinführung zu finanzieren. Diese Methode birgt jedoch das Risiko persönliche Finanzen zu gefährden.
2. Fördermittel und Zuschüsse: Aufgrund des innovativen und bildungsorientierten Ansatzes der SumoBots könnten spezielle Förderprogramme von der Regierung, der EU oder des Staates in Frage kommen.
3. Angel-Investoren und Venture Capital (VC): Investoren, die sich auf Startups im Technologie- und Bildungssektor spezialisieren, könnten an einer Finanzierung interessiert sein. Angel-Investoren bringen oft neben Kapital auch wertvolles Know-how und Netzwerke mit, während VC-Firmen größere Summen für die Skalierung bereitstellen können.

### Finanzierungsformen (Eismann)

4. Crowdfunding: Plattformen wie Kickstarter oder Indiegogo bieten eine Möglichkeit, sowohl Kapital zu sammeln als auch Marktinteresse und -validierung zu testen. Durch Vorverkäufe oder Spenden kann das Projekt finanziert werden, während gleichzeitig ein Markt aufgebaut wird.
5. Bankkredite und Kreditlinien: Traditionelle Kreditoptionen können für die Finanzierung von Produktion und Expansion in Betracht gezogen werden.
6. Partnerschaften mit Bildungseinrichtungen: Durch die direkte Zusammenarbeit mit technischen Universitäten oder anderen höheren technischen Lehranstalten könnten sowohl finanzielle als auch ressourcenbasierte Partnerschaften entstehen. Diese Einrichtungen könnten an einer Beteiligung interessiert sein, um ihren Schülern neue Lernwerkzeuge anzubieten.

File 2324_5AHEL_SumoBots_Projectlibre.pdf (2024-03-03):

2 | 2 | Recherche | 1 tag | 07.12.23 08:00 | 07.12.23 17:00
3 | 2.1 | Recherche Elektronik | 1 tag | 07.12.23 08:00 | 07.12.23 17:00
4 | 2.2 | Recherche Software | 1 tag | 07.12.23 08:00 | 07.12.23 17:00
5 | 2.3 | Recherche Konstruktion | 1 tag | 07.12.23 08:00 | 07.12.23 17:00
6 | 2.4 | Recherche Lieferanten | 1 tag | 07.12.23 08:00 | 07.12.23 17:00
7 | 3 | Planung | 1 tag | 08.12.23 08:00 | 08.12.23 17:00 | 2
8 | 3.1 | Bestellung | 1 tag | 08.12.23 08:00 | 08.12.23 17:00
9 | 3.2 | 3D - Drucker aufsetzen | 1 tag | 08.12.23 08:00 | 08.12.23 17:00
10 | 3.3 | Lötgeräte anschaffen | 1 tag | 08.12.23 08:00 | 08.12.23 17:00
11 | 4 | Konstruktion | 14 tage | 08.12.23 08:00 | 27.12.23 17:00
12 | 4.1 | Materialauswahl | 1 tag | 08.12.23 08:00 | 08.12.23 17:00 | 5
13 | 4.2 | Qualitätssicherung | 1 tag | 11.12.23 08:00 | 11.12.23 17:00 | 12
14 | 4.3 | 3D - Modeillieren | 10 tage | 12.12.23 08:00 | 25.12.23 17:00 | 13
15 | 4.4 | Druckvorgang sicherstellen | 2 tage | 26.12.23 08:00 | 27.12.23 17:00 | 14
16 | 5 | Elektronik | 14 tage | 08.12.23 08:00 | 27.12.23 17:00 | 3
17 | 5.1 | Entwickeln und Planen | 9 tage | 08.12.23 08:00 | 20.12.23 17:00
18 | 5.2 | Auswahl von Sensoren | 1 tag | 08.12.23 08:00 | 08.12.23 17:00
19 | 5.3 | Entwicklung von Fernste... | 5 tage | 08.12.23 08:00 | 14.12.23 17:00
20 | 5.4 | Fehlerbehebung | 5 tage | 21.12.23 08:00 | 27.12.23 17:00 | 17;19
21 | 6 | Software | 14 tage | 08.12.23 08:00 | 27.12.23 17:00 | 4
22 | 6.1 | Testcodes für einzelne M... | 2 tage | 08.12.23 08:00 | 11.12.23 17:00
23 | 6.2 | Debugging von Testcodes | 2 tage | 12.12.23 08:00 | 13.12.23 17:00 | 22
24 | 6.3 | Hauptprogramm schreiben | 5 tage | 14.12.23 08:00 | 20.12.23 17:00 | 23
25 | 6.6 | Debugging Haubtprogramm | 5 tage | 21.12.23 08:00 | 27.12.23 17:00 | 24
26 | 7 | Prototyping | 9 tage | 28.12.23 08:00 | 09.01.24 17:00 | 11;16;21
27 | 7.1 | Bau des Prototyps | 1 tag | 28.12.23 08:00 | 28.12.23 17:00
28 | 7.2 | Fehlersuche | 5 tage | 29.12.23 08:00 | 04.01.24 17:00 | 27
29 | 7.3 | Fertigstellung von finale... | 3 tage | 05.01.24 08:00 | 09.01.24 17:00 | 28
PSP | Name | Dauer | Start | Ende | Vorgänger | Ressourcen

SumoBots - Seite1

4 Dez 23; 11 Dez 23; 18 Dez 23; 25 Dez 23; 1 Jän 24; 8 Jän 24; 15 Jän 24; 22 Jän 24; 29 Jän 24; Fertigstellung A...; SumoBots - Seite2

F | S | S | M 5 Feb 24
D | M | D

SumoBots - ...

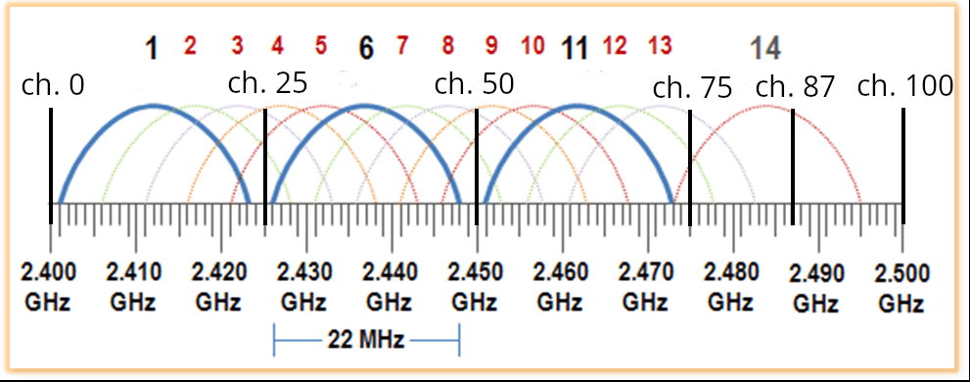
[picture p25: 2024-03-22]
code/wifi-channels+.png

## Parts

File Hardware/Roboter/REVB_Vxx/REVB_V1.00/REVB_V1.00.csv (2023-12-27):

Source: | C:\Users\lukas\Desktop\Diplomarbeit\Hardware\Roboter\REVB_V1.00\REVB_V1.00.kicad_sch
Date: | 27.12.2023 16:48:39
Tool: | Eeschema (6.0.10)
Generator: | C:\Program Files\KiCad\6.0\bin\scripting\plugins/bom_csv_grouped_by_value.py
Component Count: | 29
Individual Components:
Item | Qty | Reference(s) | Value | LibPart | Footprint | Datasheet
 |  | Brd1 | SSD1306 | SSD1306-128x64_OLED:SSD1306 | Connector_PinSocket_2.54mm:PinSocket_1x04_P2.54mm_Vertical
 |  | C1 | 22p | Device:C | Capacitor_SMD:C_1206_3216Metric | ~
 |  | C2 | 22p | Device:C | Capacitor_SMD:C_1206_3216Metric | ~
 |  | C3 | 470nF | Device:C | Capacitor_SMD:C_1206_3216Metric | ~
 |  | C4 | 470nF | Device:C | Capacitor_SMD:C_1206_3216Metric | ~
 |  | D1 | APA-106-F5 | LED:APA-106-F5 | LED_THT:LED_D5.0mm-4_RGB | https://cdn.sparkfun.com/datasheets/Components/LED/COM-12877.pdf
 |  | ICSP_Header1 | Conn_02x03_Odd_Even | Connector_Generic:Conn_02x03_Odd_Even | Connector_PinHeader_2.54mm:PinHeader_2x03_P2.54mm_Vertical | ~
 |  | J1 | Motorshield | Connector:Conn_01x06_Male | Connector_PinHeader_2.54mm:PinHeader_1x06_P2.54mm_Vertical | ~
 |  | J2 | Farbsensor TCS230 | Connector:Conn_01x07_Male | Connector_PinHeader_2.54mm:PinHeader_1x07_P2.54mm_Vertical | ~
 |  | J3 | Bremslicht_1 | Connector:Conn_01x02_Male | Connector_PinHeader_2.54mm:PinHeader_1x02_P2.54mm_Vertical | ~
 |  | J4 | Bremslicht_2 | Connector:Conn_01x02_Male | Connector_PinHeader_2.54mm:PinHeader_1x02_P2.54mm_Vertical | ~
 |  | J5 | Bremslicht_3 | Connector:Conn_01x02_Male | Connector_PinHeader_2.54mm:PinHeader_1x02_P2.54mm_Vertical | ~
 |  | J6 | Scheinwerfer_1 | Connector:Conn_01x02_Male | Connector_PinHeader_2.54mm:PinHeader_1x02_P2.54mm_Vertical | ~
 |  | J7 | Scheinwerfer_2 | Connector:Conn_01x02_Male | Connector_PinHeader_2.54mm:PinHeader_1x02_P2.54mm_Vertical | ~
 |  | J8 | Seitensensor_2 | Connector:Conn_01x03_Male | Connector_PinHeader_2.54mm:PinHeader_1x03_P2.54mm_Vertical | ~
 |  | J9 | MittlererSensor | Connector:Conn_01x03_Male | Connector_PinHeader_2.54mm:PinHeader_1x03_P2.54mm_Vertical | ~
 |  | J10 | Seitensensor_1 | Connector:Conn_01x03_Male | Connector_PinHeader_2.54mm:PinHeader_1x03_P2.54mm_Vertical | ~
 |  | R1 | 10k | Device:R | Resistor_SMD:R_1206_3216Metric | ~
 |  | R2 | 330E | Device:R | Resistor_SMD:R_1206_3216Metric | ~
 |  | R3 | 330E | Device:R | Resistor_SMD:R_1206_3216Metric | ~
 |  | R4 | 330E | Device:R | Resistor_SMD:R_1206_3216Metric | ~
 |  | R5 | 220E | Device:R | Resistor_SMD:R_1206_3216Metric | ~
 |  | R6 | 220E | Device:R | Resistor_SMD:R_1206_3216Metric | ~
 |  | U1 | ATmega2560-16A | MCU_Microchip_ATmega:ATmega2560-16A | Package_QFP:TQFP-100_14x14mm_P0.5mm | http://ww1.microchip.com/downloads/en/DeviceDoc/Atmel-2549-8-bit-AVR-Microcontroller-ATmega640-1280-1281-2560-2561_datasheet.pdf
 |  | U2 | NRF24L01_Breakout | RF:NRF24L01_Breakout | RF_Module:nRF24L01_Breakout | http://www.nordicsemi.com/eng/content/download/2730/34105/file/nRF24L01_Product_Specification_v2_0.pdf
 |  | U3 | MCP1703Ax-120xxTT | Regulator_Linear:MCP1703Ax-120xxTT | Package_TO_SOT_SMD:SOT-23 | http://ww1.microchip.com/downloads/en/DeviceDoc/20005122B.pdf
 |  | U4 | module_mpu6050 | usini_sensors:module_mpu6050 | usini_sensors:module_mpu6050
 |  | U5 | SW-420 | Custom_Symbols:SW-420 | CustomFootprints:SW-420
 |  | Y1 | 16MHz | Device:Crystal | Crystal:Crystal_HC49-4H_Vertical | ~
Collated Components:
Item | Qty | Reference(s) | Value | LibPart | Footprint | Datasheet
1 | 1 | Brd1 | SSD1306 | SSD1306-128x64_OLED:SSD1306 | Connector_PinSocket_2.54mm:PinSocket_1x04_P2.54mm_Vertical
2 | 2 | C1, C2 | 22p | Device:C | Capacitor_SMD:C_1206_3216Metric | ~
3 | 2 | C3, C4 | 470nF | Device:C | Capacitor_SMD:C_1206_3216Metric | ~
4 | 1 | D1 | APA-106-F5 | LED:APA-106-F5 | LED_THT:LED_D5.0mm-4_RGB | https://cdn.sparkfun.com/datasheets/Components/LED/COM-12877.pdf
5 | 1 | ICSP_Header1 | Conn_02x03_Odd_Even | Connector_Generic:Conn_02x03_Odd_Even | Connector_PinHeader_2.54mm:PinHeader_2x03_P2.54mm_Vertical | ~
6 | 1 | J1 | Motorshield | Connector:Conn_01x06_Male | Connector_PinHeader_2.54mm:PinHeader_1x06_P2.54mm_Vertical | ~
7 | 1 | J2 | Farbsensor TCS230 | Connector:Conn_01x07_Male | Connector_PinHeader_2.54mm:PinHeader_1x07_P2.54mm_Vertical | ~
8 | 1 | J3 | Bremslicht_1 | Connector:Conn_01x02_Male | Connector_PinHeader_2.54mm:PinHeader_1x02_P2.54mm_Vertical | ~
9 | 1 | J4 | Bremslicht_2 | Connector:Conn_01x02_Male | Connector_PinHeader_2.54mm:PinHeader_1x02_P2.54mm_Vertical | ~
10 | 1 | J5 | Bremslicht_3 | Connector:Conn_01x02_Male | Connector_PinHeader_2.54mm:PinHeader_1x02_P2.54mm_Vertical | ~
11 | 1 | J6 | Scheinwerfer_1 | Connector:Conn_01x02_Male | Connector_PinHeader_2.54mm:PinHeader_1x02_P2.54mm_Vertical | ~
12 | 1 | J7 | Scheinwerfer_2 | Connector:Conn_01x02_Male | Connector_PinHeader_2.54mm:PinHeader_1x02_P2.54mm_Vertical | ~
13 | 1 | J8 | Seitensensor_2 | Connector:Conn_01x03_Male | Connector_PinHeader_2.54mm:PinHeader_1x03_P2.54mm_Vertical | ~
14 | 1 | J9 | MittlererSensor | Connector:Conn_01x03_Male | Connector_PinHeader_2.54mm:PinHeader_1x03_P2.54mm_Vertical | ~
15 | 1 | J10 | Seitensensor_1 | Connector:Conn_01x03_Male | Connector_PinHeader_2.54mm:PinHeader_1x03_P2.54mm_Vertical | ~
16 | 1 | R1 | 10k | Device:R | Resistor_SMD:R_1206_3216Metric | ~
17 | 3 | R2, R3, R4 | 330E | Device:R | Resistor_SMD:R_1206_3216Metric | ~
18 | 2 | R5, R6 | 220E | Device:R | Resistor_SMD:R_1206_3216Metric | ~
19 | 1 | U1 | ATmega2560-16A | MCU_Microchip_ATmega:ATmega2560-16A | Package_QFP:TQFP-100_14x14mm_P0.5mm | http://ww1.microchip.com/downloads/en/DeviceDoc/Atmel-2549-8-bit-AVR-Microcontroller-ATmega640-1280-1281-2560-2561_datasheet.pdf
20 | 1 | U2 | NRF24L01_Breakout | RF:NRF24L01_Breakout | RF_Module:nRF24L01_Breakout | http://www.nordicsemi.com/eng/content/download/2730/34105/file/nRF24L01_Product_Specification_v2_0.pdf
21 | 1 | U3 | MCP1703Ax-120xxTT | Regulator_Linear:MCP1703Ax-120xxTT | Package_TO_SOT_SMD:SOT-23 | http://ww1.microchip.com/downloads/en/DeviceDoc/20005122B.pdf
22 | 1 | U4 | module_mpu6050 | usini_sensors:module_mpu6050 | usini_sensors:module_mpu6050
23 | 1 | U5 | SW-420 | Custom_Symbols:SW-420 | CustomFootprints:SW-420
24 | 1 | Y1 | 16MHz | Device:Crystal | Crystal:Crystal_HC49-4H_Vertical | ~

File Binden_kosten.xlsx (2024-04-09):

Preis | Stück | Preis / Stück | Name | Stück | Kosten
234 | 4 | 58.5 | Lukas | 1.33 | 77.805
 |  |  | Yannick | 2.34 | 136.89
 |  |  | Basti | 0.33 | 19.305
 |  |  |  | 4.00 | 234

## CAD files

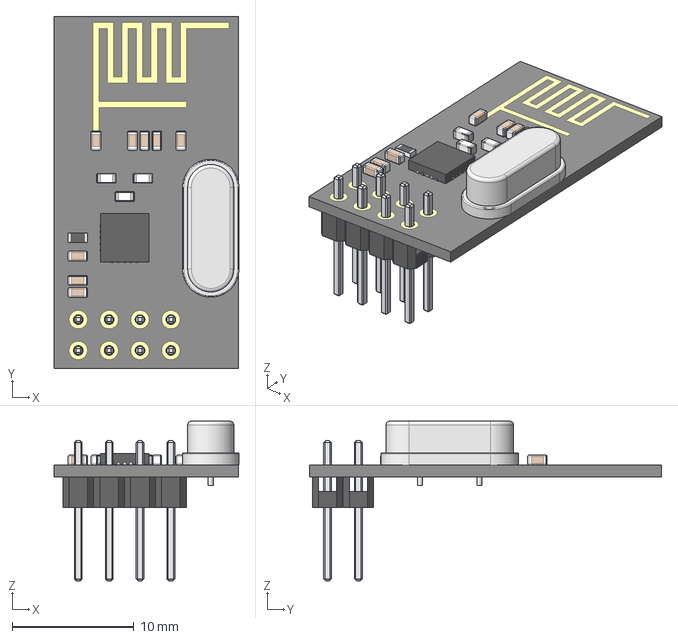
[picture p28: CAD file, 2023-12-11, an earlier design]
Hardware/Roboter/REVA_Vxx/REVA_V1.00/3D_Models_KiCAD/NRF24L01.step
15.2 x 29.0 x 13.1 mm

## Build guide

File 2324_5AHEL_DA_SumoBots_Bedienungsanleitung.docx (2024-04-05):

Bedienungsanleitung:

SumoBots

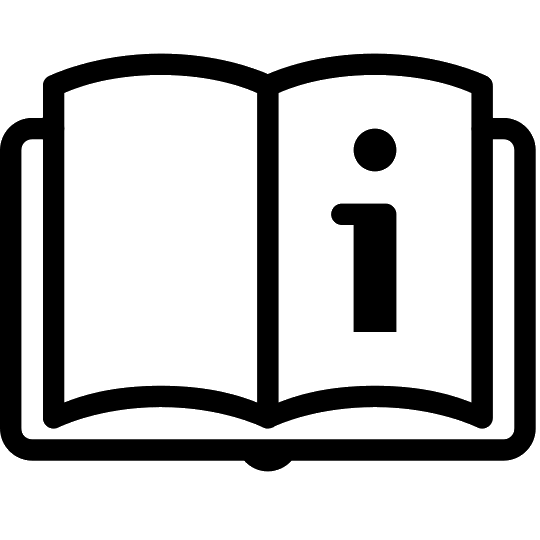
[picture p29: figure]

Inhaltsverzeichnis

# 1 Inbetriebnahme

## 1.1 Controller & Roboter

Mit den Switch auf der Seite, kann dieser eingeschalten werden. Nach dem Einschaltvorgang, kann mit der RGB-LED der Verbindungsstatus des Geräts ermittelt werden. Die Bedeutung der jeweiligen Farbe kann aus folgender Tabelle ausgelesen werden:

RGB-Farbe | Controller | Roboter-Status
Rot | Funkmodul nicht erkannt | Funkmodul nicht erkannt
Grün | Nur Roboter verbunden | Mit allem verbunden
Blau | Funkmodul erkannt, Roboter nicht verbunden | Controller verbunden, Server nicht verbunden
Cyan | --- | Funkmodul erkannt, Server und Controller nicht verbunden
Gelb | --- | Controller nicht verbunden, Server verbunden

Falls es zu Problemen der Verbindung kommen sollte, hilft ein Neustart der Komponenten, indem man diese von der Spannungsversorgung trennt.

## 1.2 Server

Da alle Konfigurationen bereits auf den Betriebssystem durchgeführt wurden, muss der Raspberry Pi lediglich an die Spannungsversorgung angeschlossen werden.

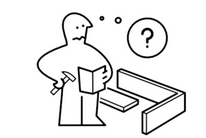
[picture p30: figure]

# 2 Aufladen

Falls der Roboter nicht stark genug beschleunigt, muss dessen Akku aufgeladen werden. Um den Ladevorgang durchzuführen, muss zunächst der Roboter abgeschaltet werden. Als nächstes wird entweder ein Labornetzteil auf 12V Output eingestellt und an den Buchsen (Plus-Ausgang vom Netzteil an roter Buchse und Minus-Ausgang vom Netzteil an schwarzer Buchse) angeschlossen.

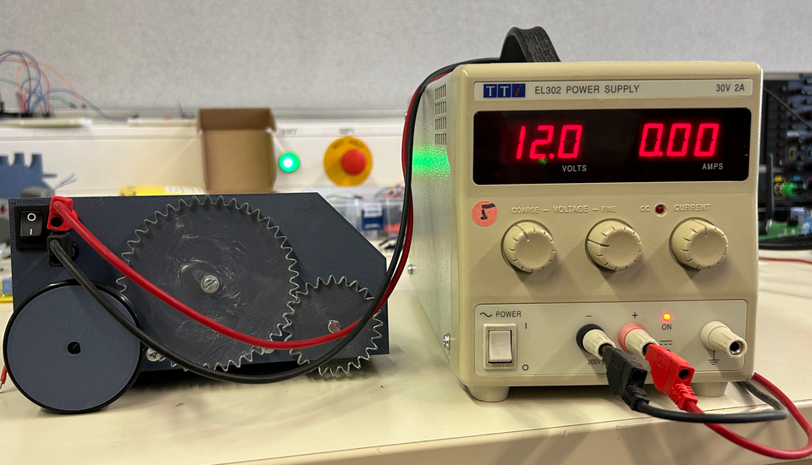
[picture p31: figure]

Falls kein Labornetzteil vorhanden sein sollte, kann ebenfalls ein Akku-Ladegerät genutzt werden und auf die selbe Weise mit den Buchsen verbunden werden.

# 3 Steuerung

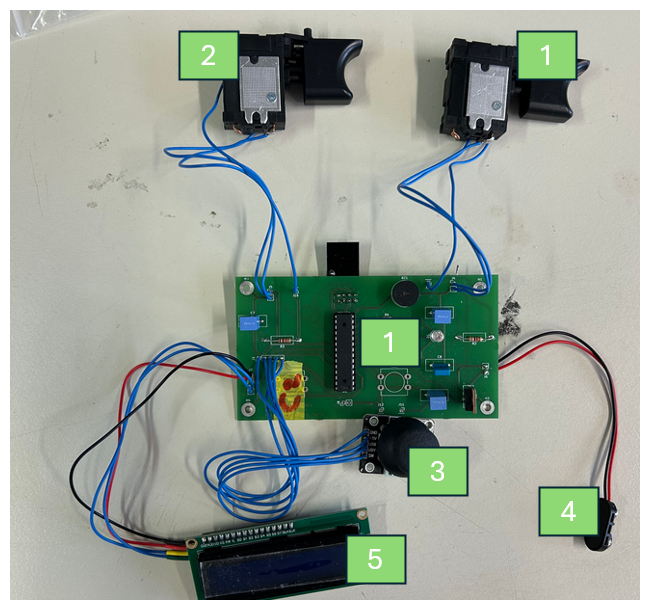
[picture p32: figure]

(1) Rechter Trigger: Geschwindigkeit nach vorne einstellbar
(2) Linker Trigger: Geschwindigkeit nach hinten einstellbar
(3) Joystick: Richtung ansteuern
(4) Akkuhalter: 9V Blockbatterie als Versorgung
(5) LCD-Display: Lädt sich auf, bei vollen Display den Joystick-Button drücken und der Roboter bekommt einen Speed-Boost

# 4 Code hochladen

Um einen neuen Code hochladen zu können und keine serielle Schnittstelle vorhanden ist, muss der Mikrocontroller des Roboters über ICSP programmiert werden. Hierfür muss folgende Vorkehrungen getroffen werden:

1. Arduino Uno als Programmer aufsetzen

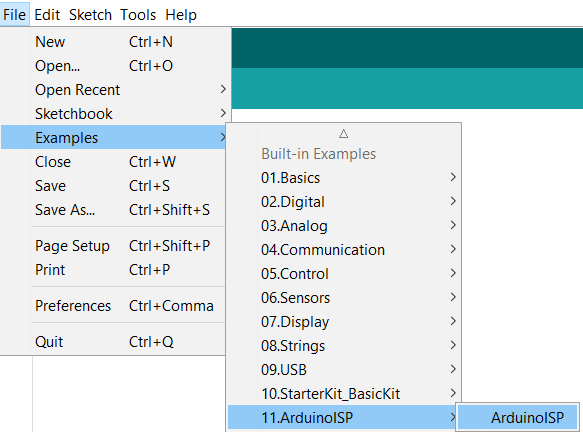
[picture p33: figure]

2. Programmer mit dem ICSP-Header verbinden

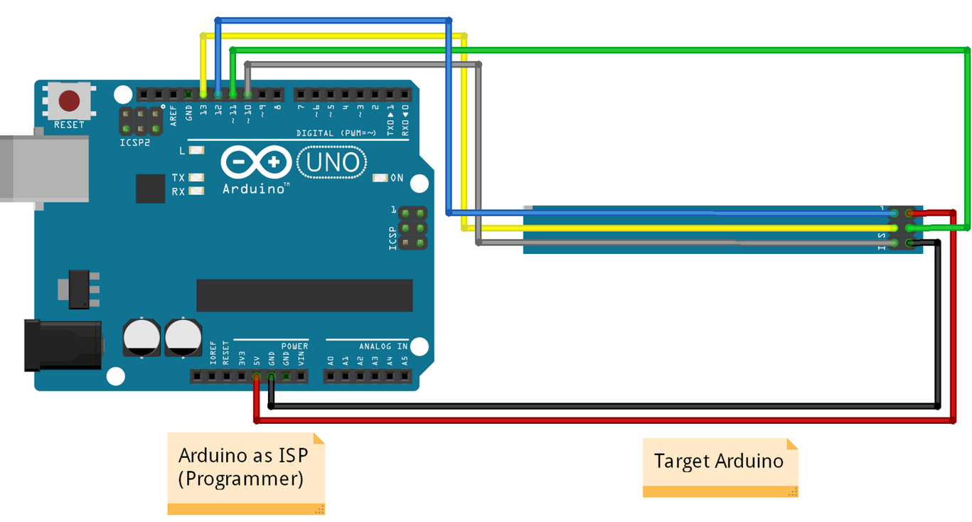
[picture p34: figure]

3. Code über ICSP hochladen

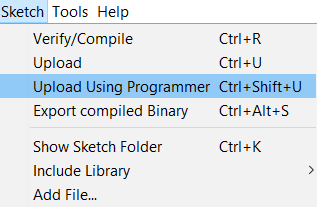
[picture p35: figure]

Nach Betätigung dieser Aktion oder die Tastenkombination Ctrl+Shift+U gedrückt wird, wird ein neuer Code auf dem Microcontroller Atmega2560 hochgeladen.

# 5 Mikrocontroller ausbauen

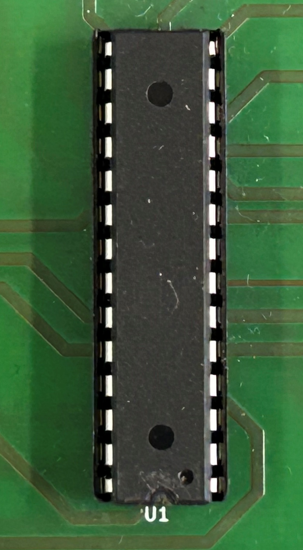
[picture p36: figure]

Wenn die Platine ausgebaut wurde, muss der Mikrocontroller vorsichtig aus dem Sockel entnommen werden. Nach diesem Schritt wird dieser in einem Arduino Uno eingesetzt und ein neuer Code hochgeladen.

Diplomarbeit Seite 11 von 11

Mikrocontroller ausbauen

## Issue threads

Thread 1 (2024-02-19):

Live Data Library

RoteRuebe, 2024-02-19:
chart.js ist eigentlich nicht gebaut um Live daten anzuzeigen. Besser dafür:

https://jscharting.com/tutorials/creating-js-charts/

RoteRuebe, 2024-03-03:
Passt jetzt eh denk ich 😌

Closed 2024-03-03.

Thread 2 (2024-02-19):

Große Textfiles

RoteRuebe, 2024-02-19:
Will man die Diagramme schnell haben, haben die txt files (die mehrmals pro sekunde abgerufen werden) sehr schnelle einige kB. Das verlangsamt alles

RoteRuebe, 2024-02-24:
Flask speichert Daten jetzt in Ringpuffer.

Closed 2024-02-24.

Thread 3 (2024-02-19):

Character array persistent

RoteRuebe, 2024-02-19:
In roboter.ino: sendSensorData() wird ein characterarray für alle radio.write's verwendet. Dieses wird dazwischen nicht neu initalisiert, überschreibt ein sprintf die vorherige Nachricht nicht völlig so bleiben manche der vorherigen Daten über und werden mitübertragen.

Lösung: statt sizeof(data) vllt andere größe nehmen damit er nicht den vollständigen string überträgt?

Closed 2024-02-20.

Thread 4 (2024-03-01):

3D Visualisierung mit MPU6050

RoteRuebe, 2024-03-01:
https://howtomechatronics.com/tutorials/arduino/arduino-and-mpu6050-accelerometer-and-gyroscope-tutorial/
- und dann die 3D - Modelle von unserem Roboter verwenden?

RoteRuebe, 2024-03-03:
Vielleicht mit
https://www.scribd.com/document/113347000/COMPLEMENTARY-FILTER
und
https://threejs.org/
?

RoteRuebe, 2024-04-16:
egal

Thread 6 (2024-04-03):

Tranquillo

RoteRuebe, 2024-04-03:
Ist Frequenzmultiplexc notwendig? Wenn ich mit den 100ms runterschraube (1ms von Controller zu Roboter!) weggehe werden nicht mehr so viele Pakete gesendet. Eine Koalission ist dann ziemlich unwarscheinlich. Und die Pipes unterscheiden mir eh zwischen den Sendern  im Server. Könnte die ganzen Verbindungen ein bisschen stabiler machen.

RoteRuebe, 2024-04-03:
Oder ich verwende statt strings c structs zur übertragung was mir die datenrate auch um so einige 100% verringern würde, bei gleicher Information

https://docs.python.org/3/library/struct.html

RoteRuebe, 2024-04-16:
hab ich jetzt so gemacht

Closed 2024-04-16.

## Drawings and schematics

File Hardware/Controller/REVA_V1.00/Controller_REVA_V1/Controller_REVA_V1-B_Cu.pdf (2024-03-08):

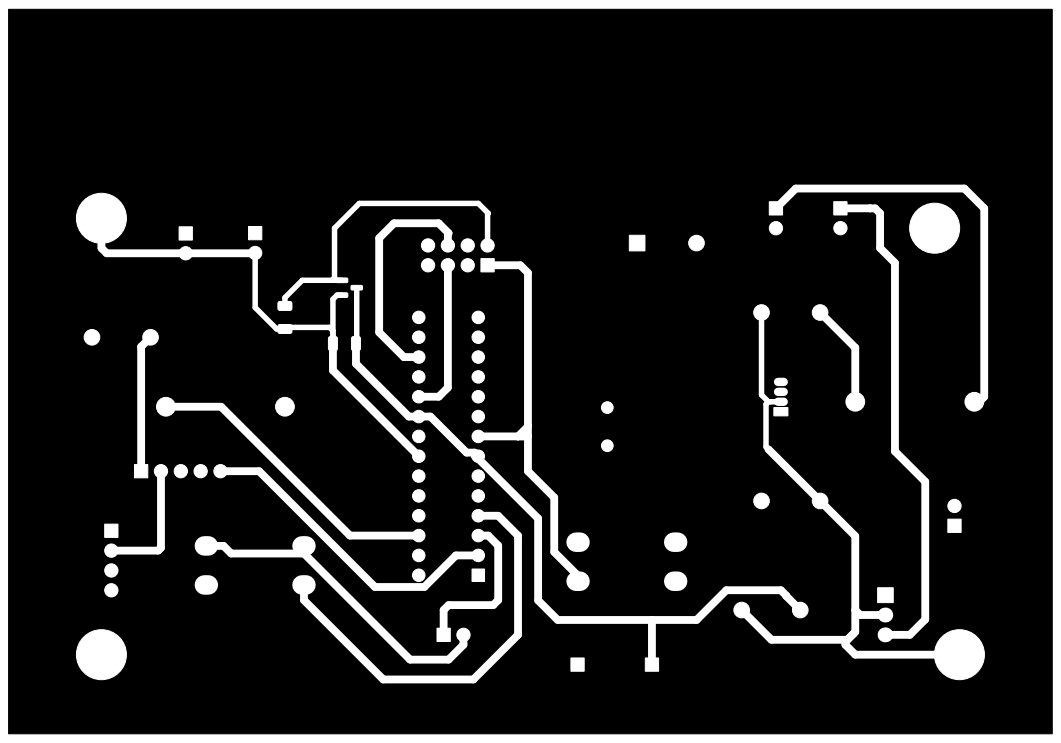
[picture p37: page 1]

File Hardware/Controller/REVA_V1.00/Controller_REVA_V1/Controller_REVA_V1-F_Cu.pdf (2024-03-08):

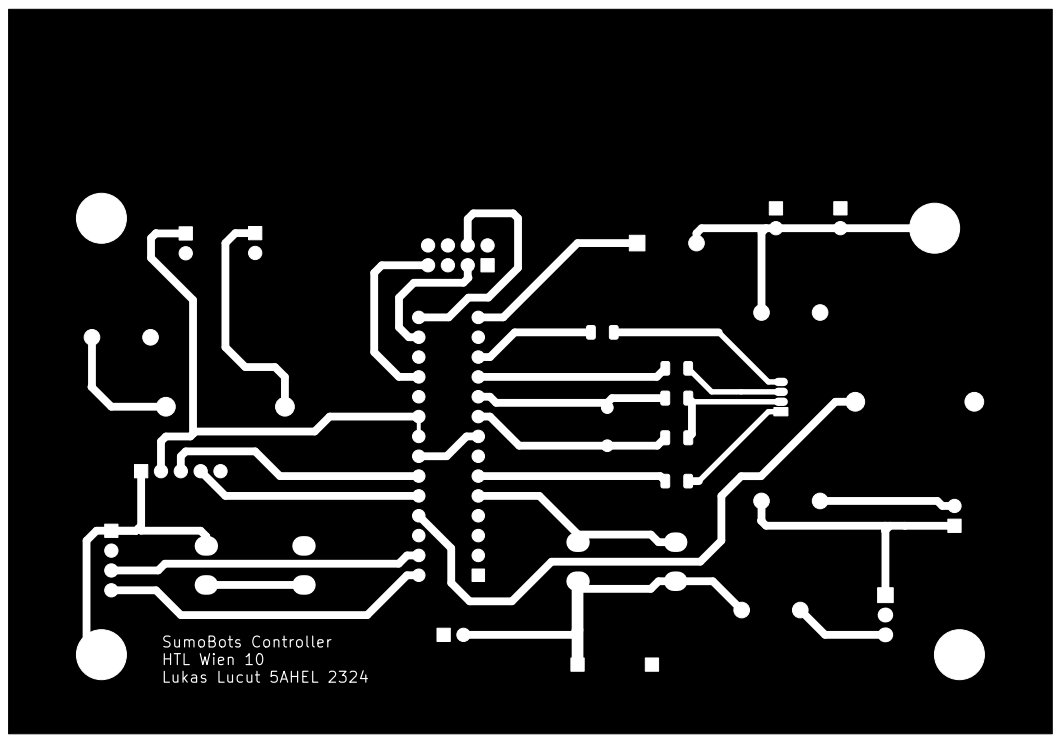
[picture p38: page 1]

SumoBots Controller HTL Wien 10 Lukas Lucut 5AHEL 2324

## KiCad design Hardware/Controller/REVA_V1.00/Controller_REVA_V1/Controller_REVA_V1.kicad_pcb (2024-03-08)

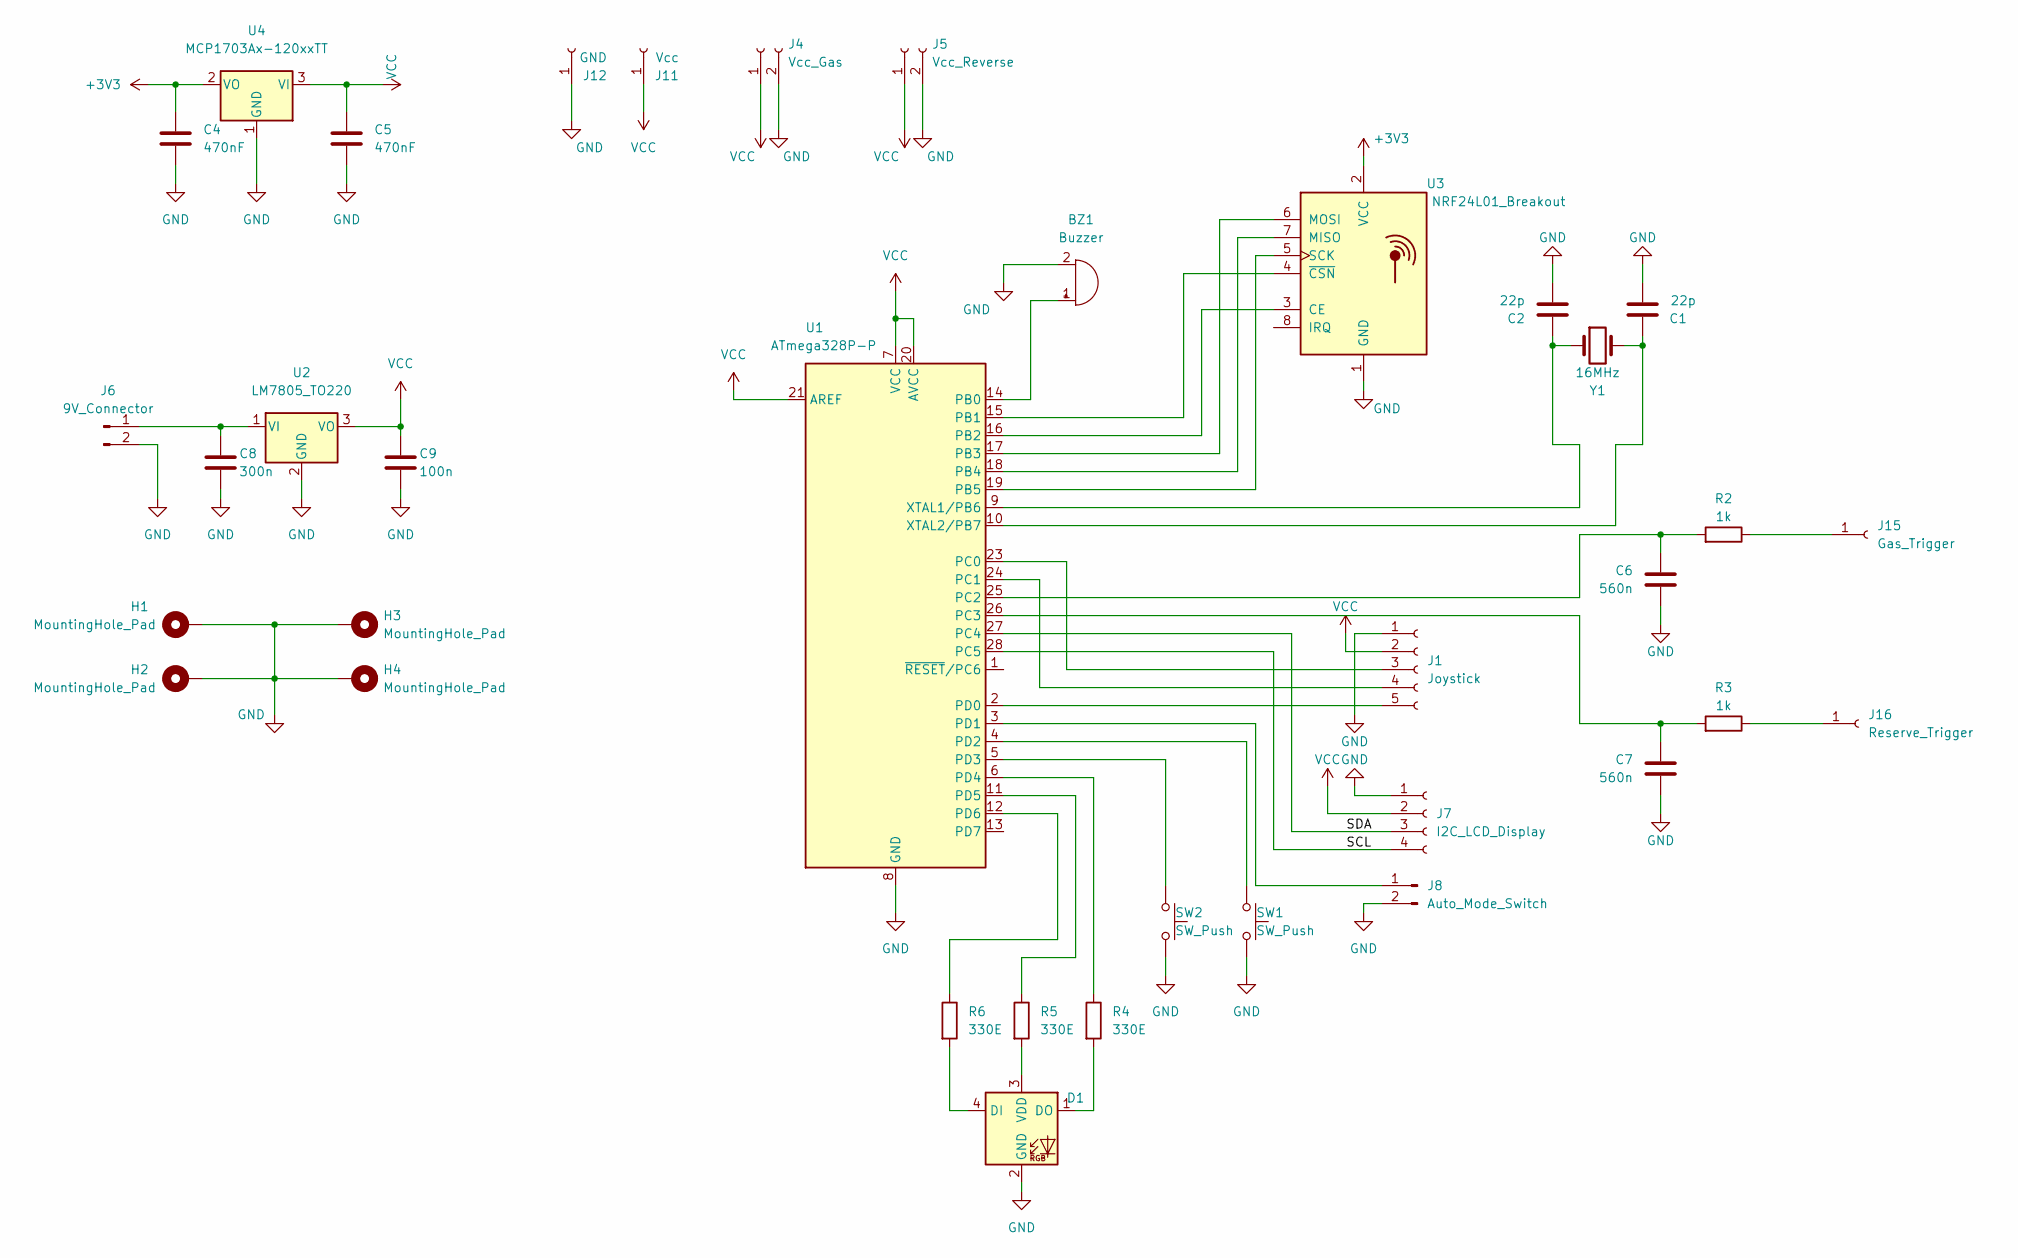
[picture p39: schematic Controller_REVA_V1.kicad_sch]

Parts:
BZ1: Buzzer; Buzzer_12x9.5RM7.6
C1, C2: 22p; C_1206_3216Metric
C4, C5: 470nF; C_1206_3216Metric
C6, C7: 560n; C_Disc_D12.5mm_W5.0mm_P7.50mm
C8: 300n; C_Disc_D12.5mm_W5.0mm_P7.50mm
C9: 100n; C_Disc_D12.5mm_W5.0mm_P7.50mm
D1: APA-106-F5; LED_D5.0mm-4_RGB
H1, H2, H3, H4: MountingHole_Pad; MountingHole_3.2mm_M3_Pad
J1: Joystick; PinHeader_1x05_P2.54mm_Vertical
J4: Vcc_Gas; PinHeader_1x02_P2.54mm_Vertical
J5: Vcc_Reverse; PinHeader_1x02_P2.54mm_Vertical
J6: 9V_Connector; PinHeader_1x02_P2.54mm_Vertical
J7: I2C_LCD_Display; PinHeader_1x04_P2.54mm_Vertical
J8: Auto_Mode_Switch; PinHeader_1x02_P2.54mm_Vertical
J11: Vcc; PinSocket_1x01_P2.54mm_Vertical
J12: GND; PinSocket_1x01_P2.54mm_Vertical
J15: Gas_Trigger; PinHeader_1x01_P2.54mm_Vertical
J16: Reserve_Trigger; PinHeader_1x01_P2.54mm_Vertical
R2, R3: 1k; R_Axial_DIN0411_L9.9mm_D3.6mm_P15.24mm_Horizontal
R4, R5, R6: 330E; R_1206_3216Metric
SW1, SW2: SW_Push; SW_PUSH-12mm_Wuerth-430476085716
U1: ATmega328P-P; DIP-28_W7.62mm
U2: LM7805_TO220; TO-220-3_Vertical
U3: NRF24L01_Breakout; nRF24L01_Breakout
U4: MCP1703Ax-120xxTT; SOT-23
Y1: 16MHz; Crystal_HC49-4H_Vertical

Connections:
+3V3: C4.1, U3.2 (VCC), U4.2 (VO)
/SCL: J7.4, U1.28 (PC5)
/SDA: J7.3, U1.27 (PC4)
GND: BZ1.2 (+), C1.2, C2.2, C4.2, C5.2, C6.2, C7.2, C8.2, C9.2, D1.2 (GND), H1.1, H2.1, H3.1, H4.1, J1.1, J4.2, J5.2, J6.2, J7.1, J8.2, J12.1, SW1.2, SW2.2, U1.8 (GND), U1.22 (GND), U2.2 (GND), U3.1 (GND), U4.1 (GND)
unnamed: BZ1.1 (-), U1.14 (PB0)
unnamed: C1.1, U1.10 (XTAL2/PB7), Y1.2
unnamed: C2.1, U1.9 (XTAL1/PB6), Y1.1
unnamed: C6.1, R2.2, U1.25 (PC2)
unnamed: C7.1, R3.2, U1.26 (PC3)
unnamed: C8.1, J6.1, U2.1 (VI)
unnamed: D1.1 (DO), R4.2
unnamed: D1.3 (VDD), R5.2
unnamed: D1.4 (DI), R6.2
unnamed: J1.3, U1.23 (PC0)
unnamed: J1.4, U1.24 (PC1)
unnamed: J1.5, U1.2 (PD0)
unnamed: J8.1, U1.3 (PD1)
unnamed: J15.1, R2.1
unnamed: J16.1, R3.1
unnamed: R4.1, U1.6 (PD4)
unnamed: R5.1, U1.11 (PD5)
unnamed: R6.1, U1.12 (PD6)
unnamed: SW1.1, U1.4 (PD2)
unnamed: SW2.1, U1.5 (PD3)
unnamed: U1.15 (PB1), U3.4 (~CSN)
unnamed: U1.16 (PB2), U3.3 (CE)
unnamed: U1.17 (PB3), U3.6 (MOSI)
unnamed: U1.18 (PB4), U3.7 (MISO)
unnamed: U1.19 (PB5), U3.5 (SCK)
VCC: C5.1, C9.1, J1.2, J4.1, J5.1, J7.2, J11.1, U1.7 (VCC), U1.20 (AVCC), U1.21 (AREF), U2.3 (VO), U4.3 (VI)

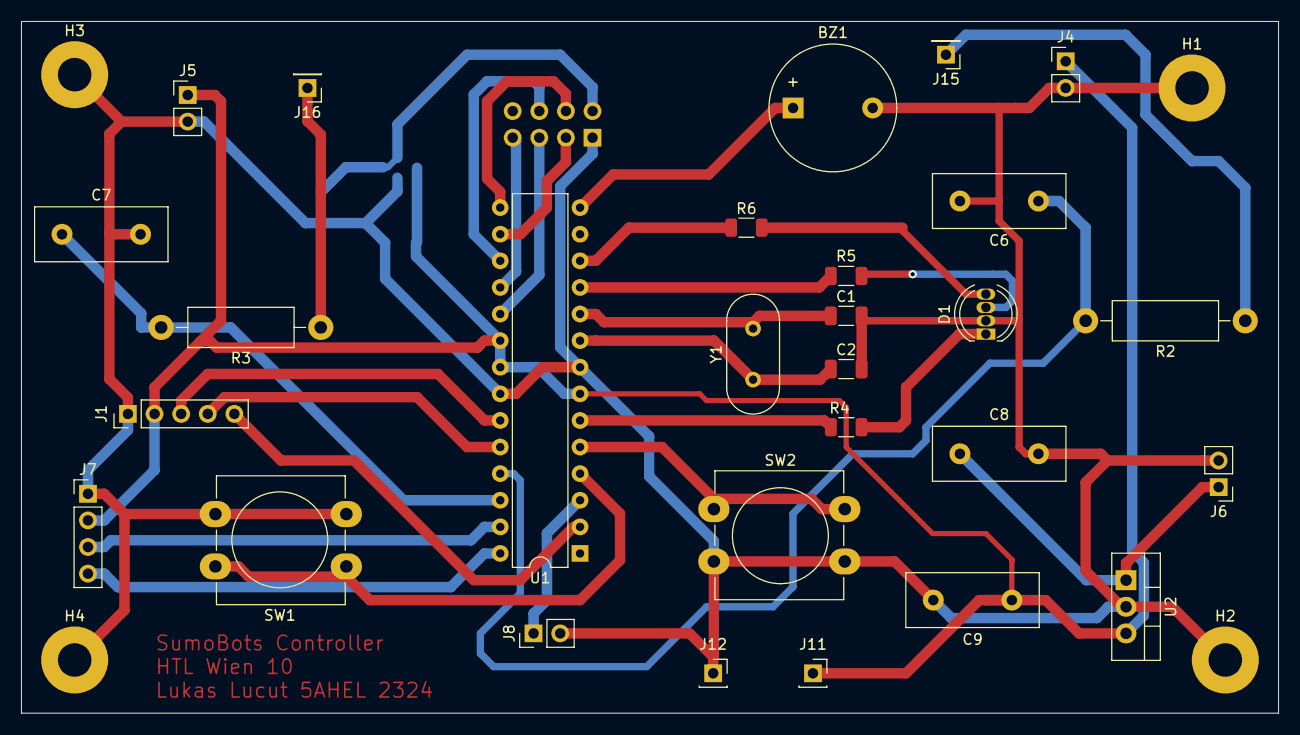
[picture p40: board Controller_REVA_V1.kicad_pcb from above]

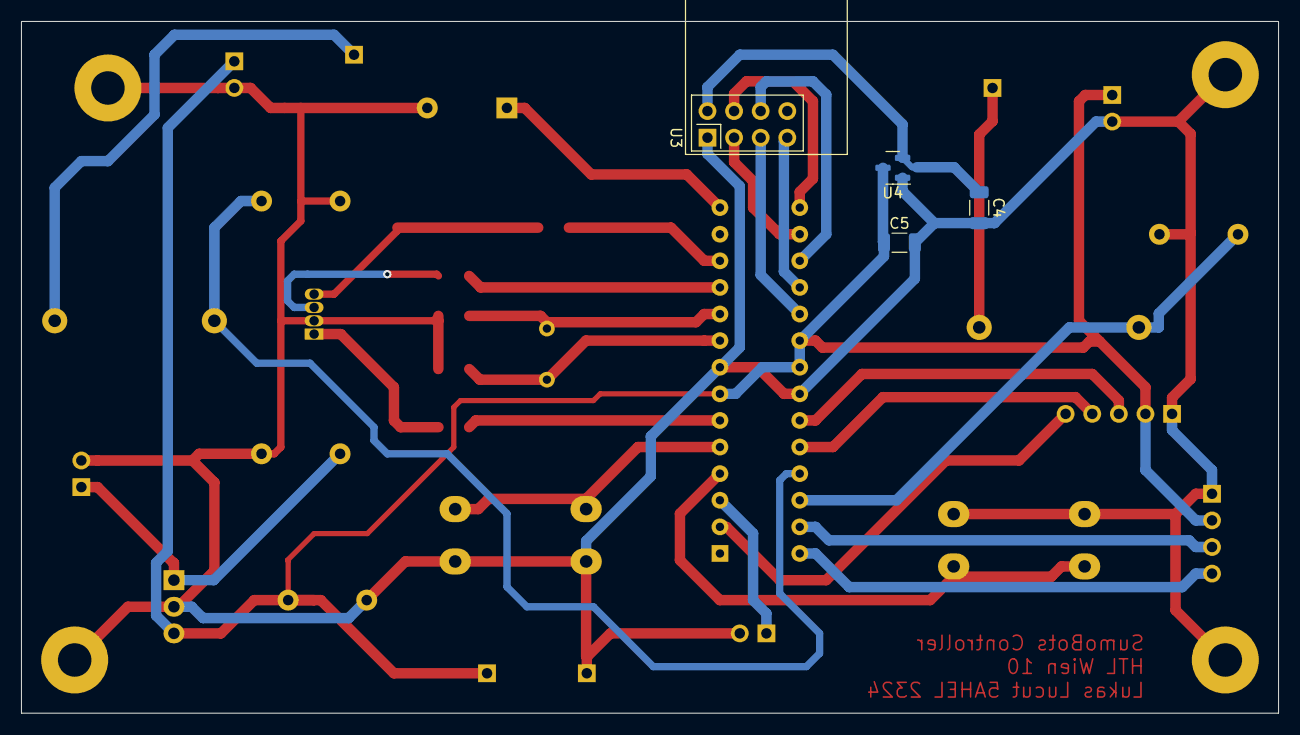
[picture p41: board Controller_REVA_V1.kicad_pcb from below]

Board: 2 copper layers, 120.0 x 66.0 mm, 36 parts (4 on the bottom side), 30 nets.

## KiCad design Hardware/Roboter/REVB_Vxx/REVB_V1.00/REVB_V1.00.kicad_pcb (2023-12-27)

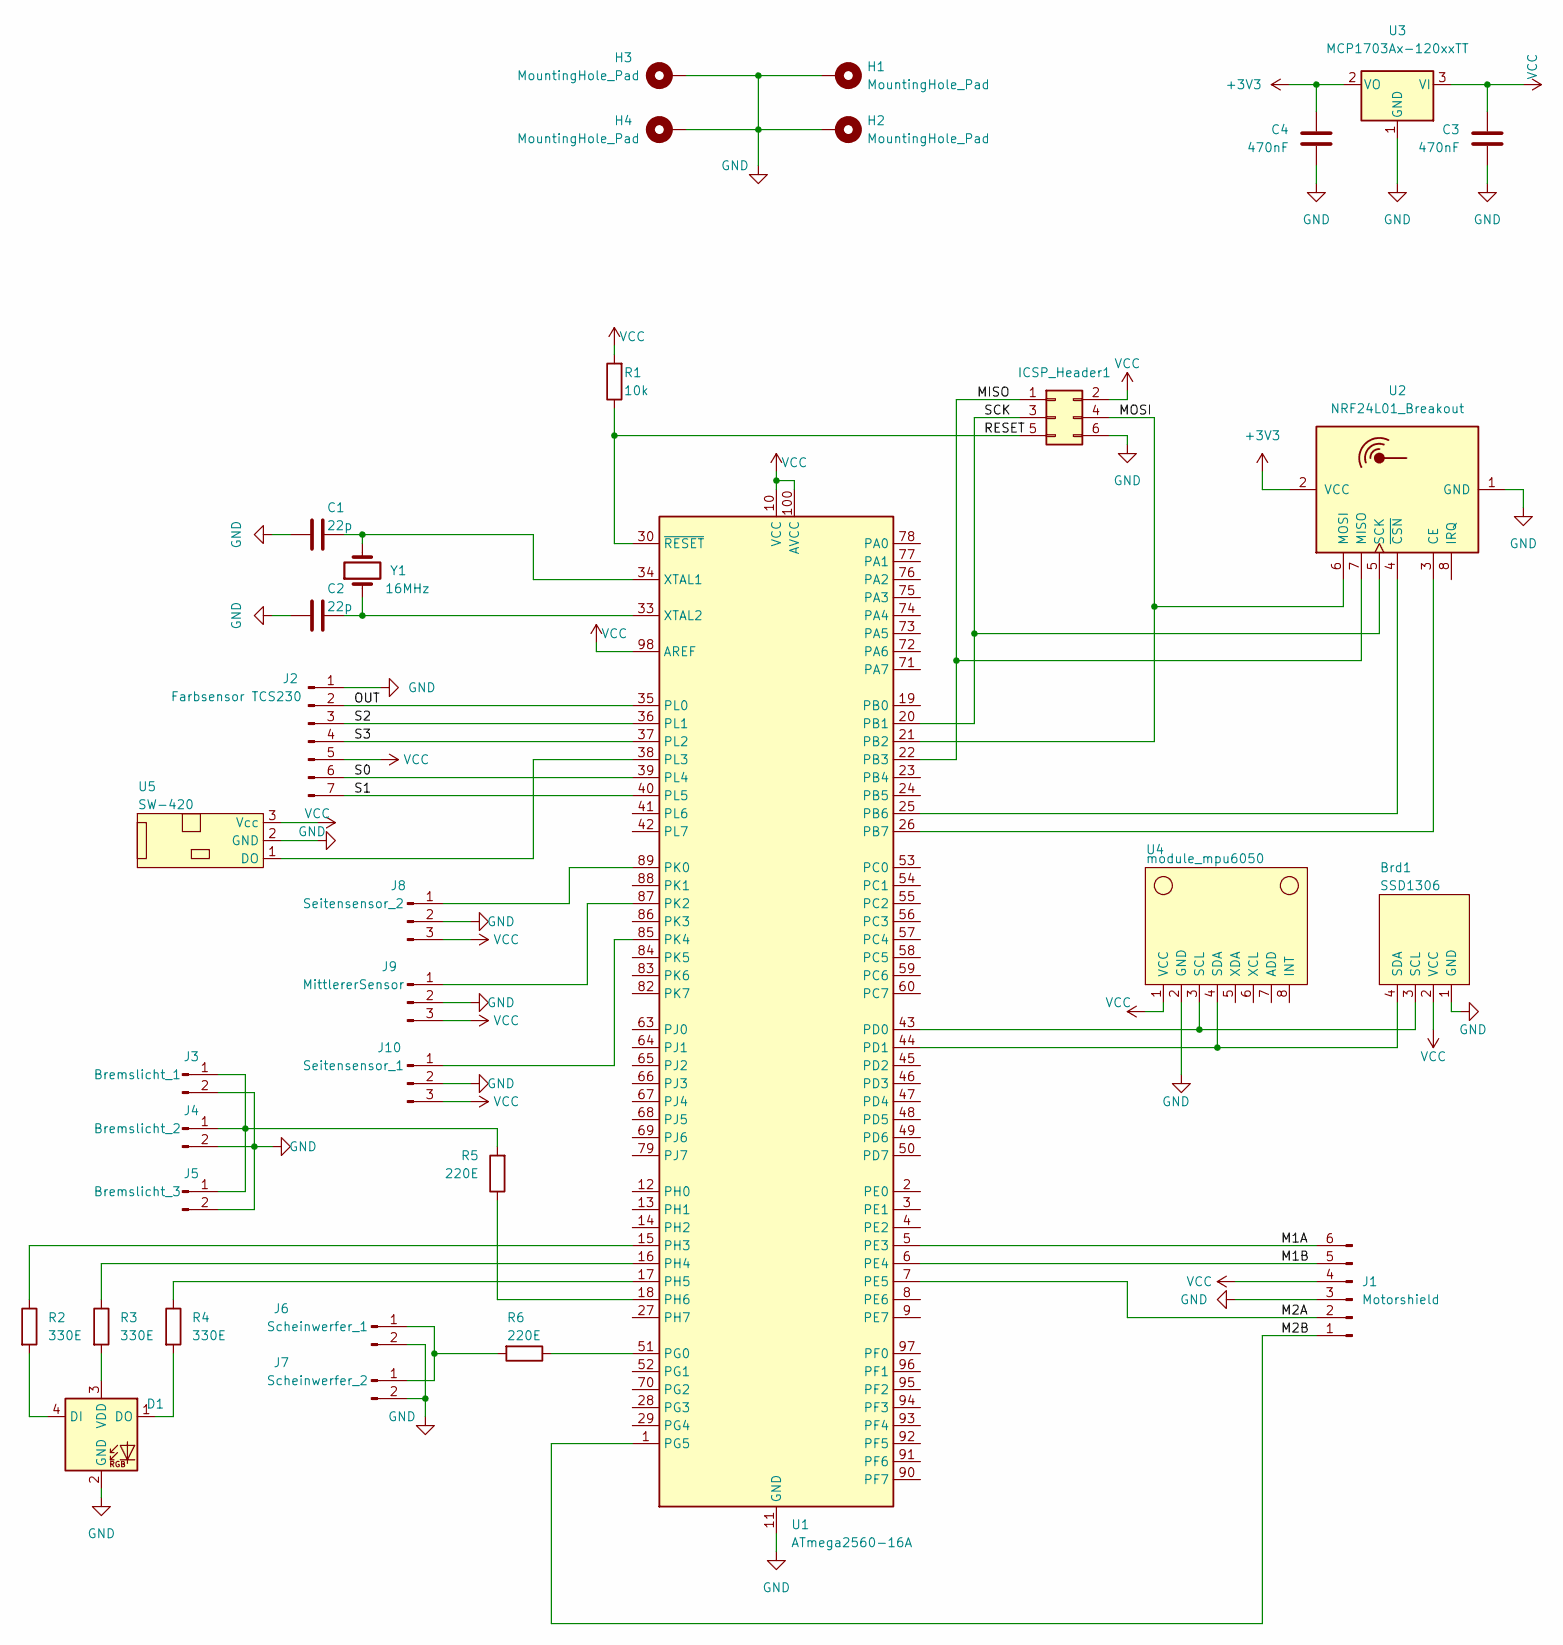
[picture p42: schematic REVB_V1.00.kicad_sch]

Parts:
Brd1: SSD1306; PinSocket_1x04_P2.54mm_Vertical
C1, C2: 22p; C_1206_3216Metric
C3, C4: 470nF; C_1206_3216Metric
D1: APA-106-F5; LED_D5.0mm-4_RGB
H1, H2, H3, H4: MountingHole_Pad; MountingHole_3.2mm_M3_Pad
ICSP_Header1: Conn_02x03_Odd_Even; PinHeader_2x03_P2.54mm_Vertical
J1: Motorshield; PinHeader_1x06_P2.54mm_Vertical
J2: Farbsensor TCS230; PinHeader_1x07_P2.54mm_Vertical
J3: Bremslicht_1; PinHeader_1x02_P2.54mm_Vertical
J4: Bremslicht_2; PinHeader_1x02_P2.54mm_Vertical
J5: Bremslicht_3; PinHeader_1x02_P2.54mm_Vertical
J6: Scheinwerfer_1; PinHeader_1x02_P2.54mm_Vertical
J7: Scheinwerfer_2; PinHeader_1x02_P2.54mm_Vertical
J8: Seitensensor_2; PinHeader_1x03_P2.54mm_Vertical
J9: MittlererSensor; PinHeader_1x03_P2.54mm_Vertical
J10: Seitensensor_1; PinHeader_1x03_P2.54mm_Vertical
R1: 10k; R_1206_3216Metric
R2, R3, R4: 330E; R_1206_3216Metric
R5, R6: 220E; R_1206_3216Metric
U1: ATmega2560-16A; TQFP-100_14x14mm_P0.5mm
U2: NRF24L01_Breakout; nRF24L01_Breakout
U3: MCP1703Ax-120xxTT; SOT-23
U4: module_mpu6050
U5: SW-420
Y1: 16MHz; Crystal_HC49-4H_Vertical

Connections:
+3V3: C4.1, U2.2 (VCC), U3.2 (VO)
/M1A: J1.6, U1.5 (PE3)
/M1B: J1.5, U1.6 (PE4)
/M2A: J1.2, U1.7 (PE5)
/M2B: J1.1, U1.1 (PG5)
/MISO: ICSP_Header1.1, U1.22 (PB3), U2.7 (MISO)
/MOSI: ICSP_Header1.4, U1.21 (PB2), U2.6 (MOSI)
/OUT: J2.2, U1.35 (PL0)
/RESET: ICSP_Header1.5, R1.1, U1.30 (~RESET)
/S0: J2.6, U1.39 (PL4)
/S1: J2.7, U1.40 (PL5)
/S2: J2.3, U1.36 (PL1)
/S3: J2.4, U1.37 (PL2)
/SCK: ICSP_Header1.3, U1.20 (PB1), U2.5 (SCK)
GND: Brd1.1 (GND), C1.2, C2.2, C3.2, C4.2, D1.2 (GND), H1.1, H2.1, H3.1, H4.1, ICSP_Header1.6, J1.3, J2.1, J3.2, J4.2, J5.2, J6.2, J7.2, J8.2, J9.2, J10.2, U1.11 (GND), U1.32 (GND), U1.62 (GND), U1.81 (GND), U1.99 (GND), U2.1 (GND), U3.1 (GND), U4.2 (GND), U5.2 (GND)
unnamed: Brd1.3 (SCL), U1.43 (PD0), U4.3 (SCL)
unnamed: Brd1.4 (SDA), U1.44 (PD1), U4.4 (SDA)
unnamed: C1.1, U1.34 (XTAL1), Y1.2
unnamed: C2.1, U1.33 (XTAL2), Y1.1
unnamed: D1.1 (DO), R4.2
unnamed: D1.3 (VDD), R3.2
unnamed: D1.4 (DI), R2.2
unnamed: J3.1, J4.1, J5.1, R5.2
unnamed: J6.1, J7.1, R6.2
unnamed: J9.1, U1.87 (PK2)
unnamed: J10.1, U1.85 (PK4)
unnamed: R2.1, U1.15 (PH3)
unnamed: R3.1, U1.16 (PH4)
unnamed: R4.1, U1.17 (PH5)
unnamed: R5.1, U1.18 (PH6)
unnamed: R6.1, U1.51 (PG0)
unnamed: U1.25 (PB6), U2.4 (~CSN)
unnamed: U1.26 (PB7), U2.3 (CE)
unnamed: U1.38 (PL3), U5.1 (DO)
unnamed: J8.1, U1.89 (PK0)
VCC: Brd1.2 (VCC), C3.1, ICSP_Header1.2, J1.4, J2.5, J8.3, J9.3, J10.3, R1.2, U1.10 (VCC), U1.31 (VCC), U1.61 (VCC), U1.80 (VCC), U1.98 (AREF), U1.100 (AVCC), U3.3 (VI), U4.1 (VCC), U5.3 (Vcc)

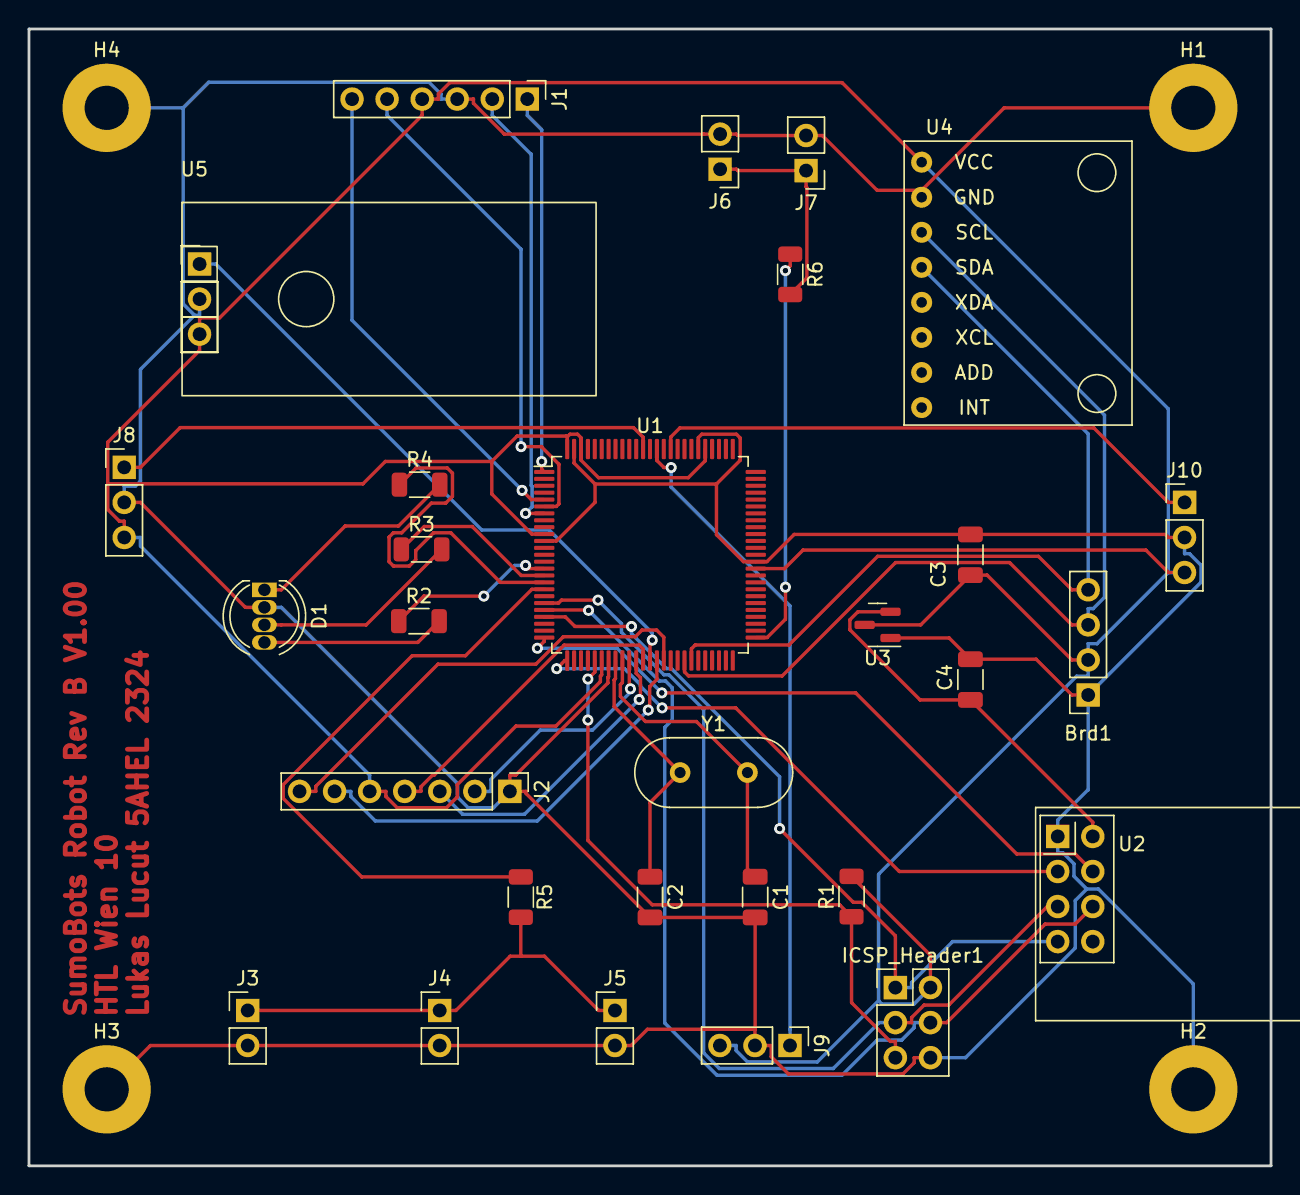
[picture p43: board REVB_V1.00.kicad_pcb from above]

Board: 2 copper layers, 90.0 x 82.4 mm, 33 parts (0 on the bottom side), 36 nets.

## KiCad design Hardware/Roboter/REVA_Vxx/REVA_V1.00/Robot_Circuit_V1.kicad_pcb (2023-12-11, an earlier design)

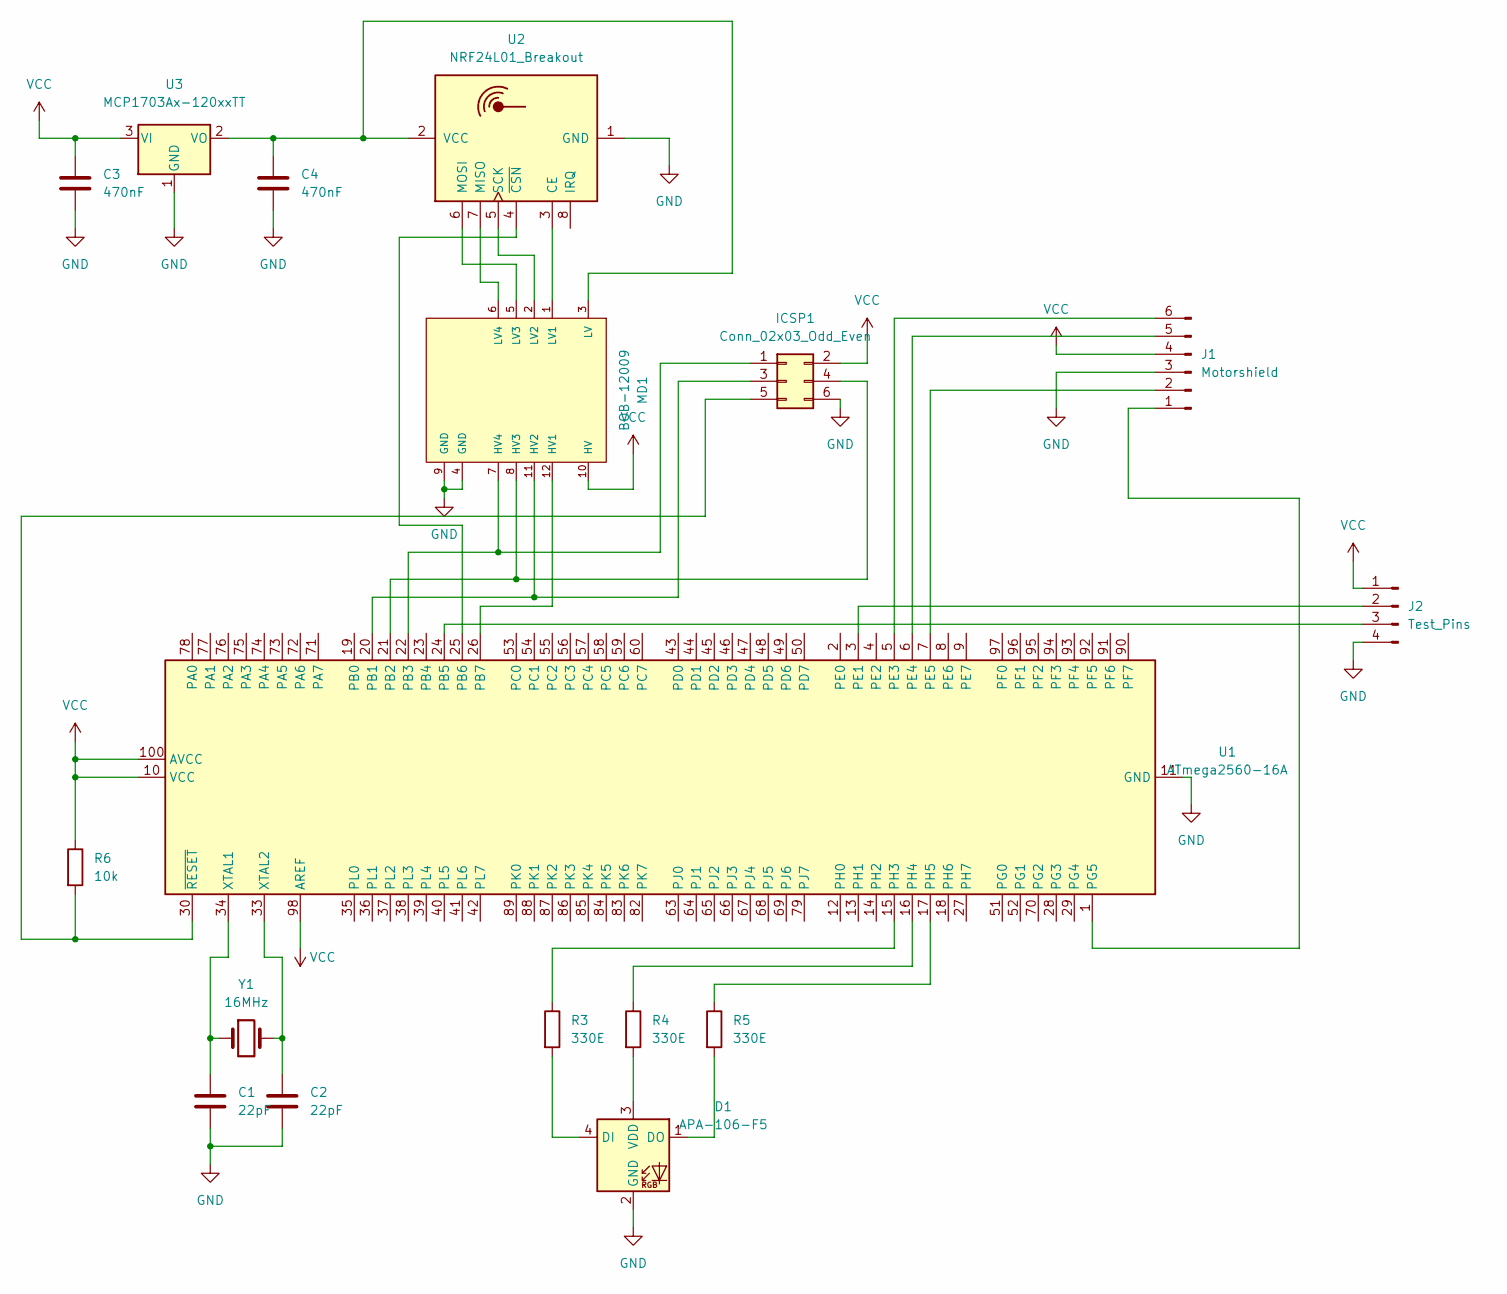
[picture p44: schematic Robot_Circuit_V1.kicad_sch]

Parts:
C1, C2: 22pF; C_1206_3216Metric
C3, C4: 470nF; C_1206_3216Metric
D1: APA-106-F5; LED_D5.0mm-4_RGB
ICSP1: Conn_02x03_Odd_Even; PinHeader_2x03_P2.54mm_Vertical
J1: Motorshield; PinHeader_1x06_P2.54mm_Vertical
J2: Test_Pins; PinSocket_1x04_P2.54mm_Vertical
MD1: BOB-12009; SparkFun-BOB-12009-MFG; mouser part number 474-BOB-12009; digikey description LOGIC LEVEL CONVERTER - BI-DIREC
R3, R4, R5: 330E; R_1206_3216Metric
R6: 10k; R_1206_3216Metric
U1: ATmega2560-16A; TQFP-100_14x14mm_P0.5mm
U2: NRF24L01_Breakout; nRF24L01_Breakout
U3: MCP1703Ax-120xxTT; SOT-23
Y1: 16MHz; Crystal_HC49-U_Vertical

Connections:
unnamed: C1.1, U1.34 (XTAL1), Y1.1
unnamed: C2.1, U1.33 (XTAL2), Y1.2
unnamed: C4.1, MD1.3 (LV), U2.2 (VCC), U3.2 (VO)
unnamed: D1.1 (DO), R5.2
unnamed: D1.3 (VDD), R4.2
unnamed: D1.4 (DI), R3.2
unnamed: ICSP1.1, MD1.7 (HV4), U1.22 (PB3)
unnamed: ICSP1.3, MD1.11 (HV2), U1.20 (PB1)
unnamed: ICSP1.4, MD1.8 (HV3), U1.21 (PB2)
unnamed: ICSP1.5, R6.2, U1.30 (~RESET)
unnamed: J1.1, U1.1 (PG5)
unnamed: J1.2, U1.7 (PE5)
unnamed: J1.5, U1.6 (PE4)
unnamed: J1.6, U1.5 (PE3)
unnamed: J2.2, U1.3 (PE1)
unnamed: J2.3, U1.24 (PB5)
unnamed: MD1.1 (LV1), U2.3 (CE)
unnamed: MD1.2 (LV2), U2.5 (SCK)
unnamed: MD1.5 (LV3), U2.6 (MOSI)
unnamed: MD1.6 (LV4), U2.7 (MISO)
unnamed: MD1.12 (HV1), U1.26 (PB7)
unnamed: R3.1, U1.15 (PH3)
unnamed: R4.1, U1.16 (PH4)
unnamed: R5.1, U1.17 (PH5)
unnamed: U1.25 (PB6), U2.4 (~CSN)
VCC: C3.1, ICSP1.2, J1.4, J2.1, MD1.10 (HV), R6.1, U1.10 (VCC), U1.31 (VCC), U1.61 (VCC), U1.80 (VCC), U1.98 (AREF), U1.100 (AVCC), U3.3 (VI)

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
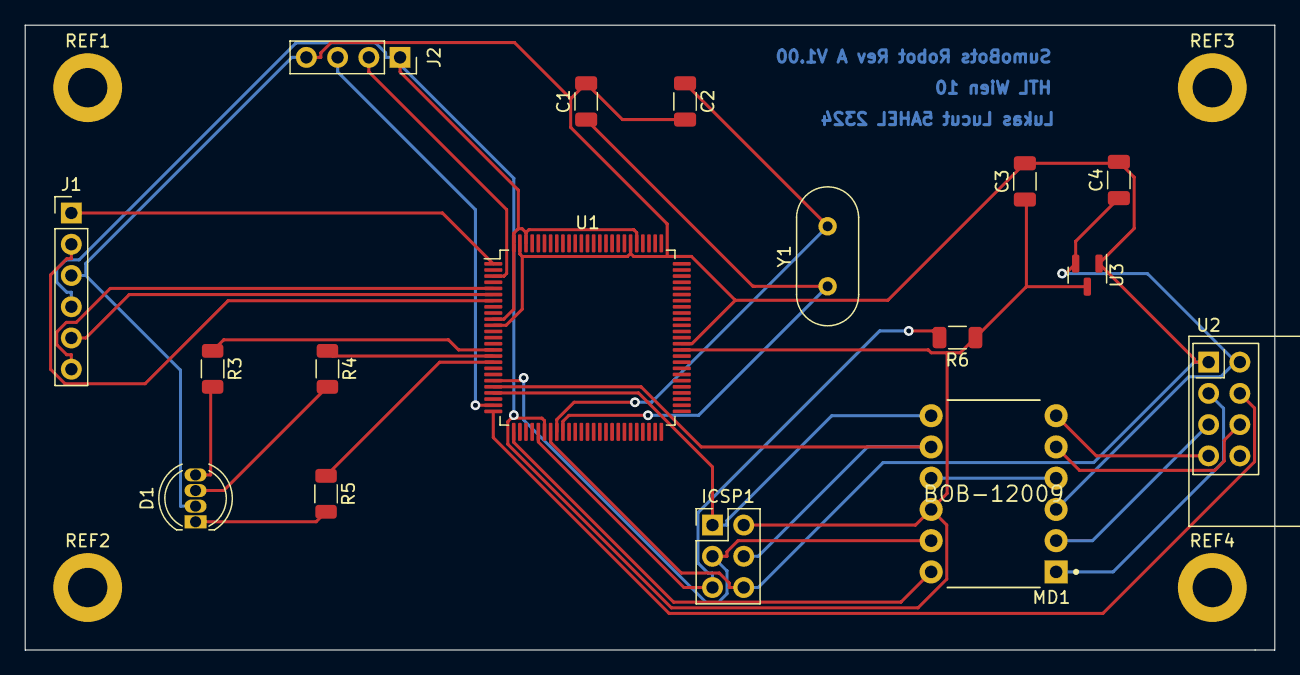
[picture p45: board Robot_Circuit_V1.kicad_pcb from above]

Board: 2 copper layers, 101.6 x 50.8 mm, 21 parts (0 on the bottom side), 28 nets.

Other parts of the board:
REF1, REF2, REF3, REF4: MountingHole_3.2mm_M3_DIN965_Pad

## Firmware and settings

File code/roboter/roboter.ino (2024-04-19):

/**
*   Auth: Yannick Zickler
*
*   Desc: Code for the robot. Handles communication, drives motors serial Interface and LED.
*/

#define robot1
#include "roboter.h"

/** Initialization **/

void setup() {
  // Setup Pins
  pinMode(p_lf, OUTPUT);
  pinMode(p_lb, OUTPUT);
  pinMode(p_rf, OUTPUT);
  pinMode(p_rb, OUTPUT);
  
  pinMode(p_red, OUTPUT);
  pinMode(p_green, OUTPUT);
  pinMode(p_blue, OUTPUT);

  pinMode(p_breakLight, OUTPUT);
  pinMode(p_lamp, OUTPUT);

  pinMode(p_vibration, INPUT);
  pinMode(p_color_s0, OUTPUT); digitalWrite(p_color_s0, 1);
  pinMode(p_color_s1, OUTPUT); digitalWrite(p_color_s1, 1);
  pinMode(p_color_s2, OUTPUT); digitalWrite(p_color_s2, 1);
  pinMode(p_color_s3, OUTPUT); digitalWrite(p_color_s3, 0);
  pinMode(p_color_out, INPUT);
  
  rgbWrite(1, 0, 0); // red
  configureRadio();

  if(mpu.begin()) {
    logMsg("Gyro Initialized.", 17);

    mpu.setAccelerometerRange(MPU6050_RANGE_8_G);
    mpu.setGyroRange(MPU6050_RANGE_500_DEG);
    mpu.setFilterBandwidth(MPU6050_BAND_21_HZ);
  }
  else {
    logMsg("Gyro not connected.", 19);
  }

  display.begin(SSD1306_SWITCHCAPVCC, 0x3C);
  drawFace(Default);
  
  logMsg("Initialization complete.", 24);  
}

void loop() {
  crntMillis = millis();

  if (radio.failureDetected) {
    drive(0, 0);

    //blocks until radio configured
    configureRadio();
    logMsg("Radio reconfigured after failure", 32);
  }

  if (radio.available()) {
    radio.read(inputs, sizeof(inputs)); 
    controllerConnected = 1;
    millisLastPacket = crntMillis;
  }

  else if (crntMillis - millisLastPacket >= 500) {
    controllerConnected = 0;
  }

  if (crntMillis - prevMillisDraw >= 250) {
    if (pulseIn(p_color_out, LOW) < 40) {
      drawFace(Dead);
    }
  
    else if ( sensor_a.acceleration.x + sensor_a.acceleration.y + sensor_a.acceleration.z >= 30) {
      drawFace(Surprised);
    }
  
    else {
      drawFace(Default);
    }
    prevMillisDraw = crntMillis;
  }

  if (crntMillis - prevMillisData > pushDataTimestamp) {
    serverConnected = sendSensorData();
    prevMillisData = crntMillis;
  }

  if (serverConnected && controllerConnected)
    rgbWrite(0, 1, 0); // green
  else if (!serverConnected && controllerConnected)
    rgbWrite(0, 0, 1); // blue
  else if (serverConnected && !controllerConnected)
    rgbWrite(1, 1, 0); // yellow
  else if (!serverConnected && !controllerConnected )
    rgbWrite(0, 1, 1); // cyan

  // Calculate Motor speeds.acceleration.
  if (SHO_R >= SHO_L) {
    speed = SHO_R;
    digitalWrite(p_lamp, 1);
    digitalWrite(p_breakLight, 0);
  }

  else {
    speed = -SHO_L;
    digitalWrite(p_lamp, 0);
    digitalWrite(p_breakLight, 1);
  }

  turn = (float)JOY_X / 256.0;  
  if (JOY_X < 0) {
    lm_turn = fmap(turn, -1.0, 0.0, -1.0, 1.0);
    rm_turn = 1.0;
  }

  else if (JOY_X >= 0) {
    lm_turn = 1.0;
    rm_turn = fmap(turn, 0.0, 1.0, 1.0, -1.0);
  }
  
  lm_soll = (int)(lm_turn * speed);
  rm_soll = (int)(rm_turn * speed);

  // Slow down acceleration of motors
  if (controllerConnected) {
    if (lm_ist > lm_soll)
      lm_ist -= 1;

    else if (lm_ist < lm_soll)
      lm_ist += 1;

    if (rm_ist > rm_soll)
      rm_ist -= 1;

    else if (rm_ist < rm_soll)
      rm_ist += 1;

    drive(lm_ist, rm_ist);
  }

  else {
    drive(0, 0);
  }
}

/** Functions **/

void configureRadio() {
  // Do nothing while radio module not connected
  while ( !radio.begin() ) {}
  
  radio.openReadingPipe(1, controllerAddress);
  radio.openWritingPipe(serverAddress); 
  radio.setPALevel(RF24_PA_MIN);
  radio.setRetries(4, 10);
}


void rgbWrite(int r, int g, int b) {
  digitalWrite(p_red, r);
  digitalWrite(p_green, g);
  digitalWrite(p_blue, b);
}

void drive(int left, int right) {
  left = -left;
  if (left > 0) {
    analogWrite(p_lf, left);
    analogWrite(p_lb, 0);
  } 
  else {
    analogWrite(p_lb, -left);
    analogWrite(p_lf, 0);
  }

  if (right > 0) {
    analogWrite(p_rf, right);
    analogWrite(p_rb, 0);
  } 
  else {
    analogWrite(p_rb, -right);
    analogWrite(p_rf, 0);
  }
}

int logMsg(char *x, int len) {
  radio.stopListening();

  int response = radio.write( x, len );

  radio.startListening();
  return response;
}

int sendSensorData() {
  radio.stopListening();

  mpu.getEvent(&sensor_a, &sensor_g, &sensor_temp);

  struct DataPayload payload = {
    0x00,
    sensor_g.gyro.x, sensor_g.gyro.y, sensor_g.gyro.z, 
    sensor_a.acceleration.x, sensor_a.acceleration.y, sensor_a.acceleration.z, 
    sensor_temp.temperature,
    controllerConnected,
    digitalRead(p_vibration)
  };
  int response = radio.write(&payload, sizeof(payload));

  radio.startListening();
  return response;
}

float fmap(float x, float in_min, float in_max, float out_min, float out_max) {
  return (x - in_min) * (out_max - out_min) / (in_max - in_min) + out_min;
}

void drawFace(face_t face) {
  display.clearDisplay();

  if (face == Default)
    display.drawBitmap(0, 0, defaultFace, SCREEN_WIDTH, SCREEN_HEIGHT, 1);
  else if (face == Dead)
    display.drawBitmap(0, 0, deadFace, SCREEN_WIDTH, SCREEN_HEIGHT, 1);
  else if (face == Surprised)
    display.drawBitmap(0, 0, surprisedFace, SCREEN_WIDTH, SCREEN_HEIGHT, 1);
 
  display.display();  
}

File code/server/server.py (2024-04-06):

import RPi.GPIO as gpio
from pyrf24 import *
from collections import deque
import threading, flask, time, struct

### Shared Memory ###
gyroX = [deque(maxlen=100),deque(maxlen=100),deque(maxlen=100)]
gyroY = [deque(maxlen=100),deque(maxlen=100),deque(maxlen=100)]
gyroZ = [deque(maxlen=100),deque(maxlen=100),deque(maxlen=100)]

accX = [deque(maxlen=100),deque(maxlen=100),deque(maxlen=100)]
accY = [deque(maxlen=100),deque(maxlen=100),deque(maxlen=100)]
accZ = [deque(maxlen=100),deque(maxlen=100),deque(maxlen=100)]

vibration = [deque(maxlen=10),deque(maxlen=10),deque(maxlen=10)]
temp = [deque(maxlen=10),deque(maxlen=10),deque(maxlen=10)]
log = [deque(maxlen=10),deque(maxlen=10),deque(maxlen=10)]

robotConnected = [False, False, False]
controllerConnected = [False, False, False]

### Rf24 Thread ###
def process(i, x):
    if ( x[0] == 0x00 ): #Data
        data = struct.unpack("< B 7f 2B B", x)

        print(i)
        print(data)
        gyroX[i].append(data[1])
        gyroY[i].append(data[2])
        gyroZ[i].append(data[3])

        accX[i].append(data[4])
        accY[i].append(data[5])
        accZ[i].append(data[6])

        temp[i].append(data[7])
        controllerConnected[i] = bool( data[8] )
        vibration[i] = data[9]

    else:
        data = struct.unpack("<32s", x)
        log[i].append( data[0].decode("ASCII").split( u"\x00" )[0] )


def serviceRadio():
    radio = RF24(25, 0)
    while (not radio.begin()):
        pass

    # Match Null-Terminated C "Strings"
    radio.openReadingPipe(0, bytearray( b"1-r-s\x00" ))
    radio.openReadingPipe(1, bytearray( b"2-r-s\x00" ))
    radio.openReadingPipe(2, bytearray( b"3-r-s\x00" ))

    radio.listen = True
    radio.print_details()

    timeNow = 0
    timeLastPacket = [0, 0, 0]
    index = 0

    print("Listening")
    while True:
        timeNow = time.time()

        hasPayload, index = radio.available_pipe()

        if ( hasPayload ):
            timeLastPacket[index] = timeNow
            robotConnected[index] = True

            rec = radio.read()

            try:
                process(index, rec)
            except Exception as e: print(e)


        for i in range(3):
            if ( timeNow - timeLastPacket[i] >= 0.250):
                robotConnected[i] = False
                controllerConnected[i] = False


threading.Thread(target=serviceRadio, args=() ).start()

#gyroX = [ [i for i in range(100)],  [50 for i in range(100)],  [100-i for i in range(100)] ]

### Webserver ###
app = flask.Flask(__name__)

@app.route("/")
def index():
    return flask.render_template("index.html")

@app.route("/about")
def about():
    return flask.render_template("about.html")

@app.route("/data/<name>/<id>")
def data(name,id):
    id = int(id)
    if name == "log": return list(log[id])
    elif name == "temp": return list(temp[id])
    elif name == "gyro": return { "x": list(gyroX[id]), "y": list(gyroY[id]), "z": list(gyroZ[id])}
    elif name == "acc": return { "x": list(accX[id]), "y": list(accY[id]), "z": list(accZ[id])}
    elif name == "status": return { "robotConnected": str( robotConnected[id] ), "controllerConnected": str( controllerConnected[id] ) }

    else: return "Ressource not found", 404

if __name__ == "__main__":
    app.run(host="0.0.0.0")

    flask.url_for("static", filename="style.css")
    flask.url_for("static", filename="source.js")

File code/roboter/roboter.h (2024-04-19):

#include <SPI.h>
#include <nRF24L01.h>
#include <RF24.h>
#include <string.h>

#include <Adafruit_MPU6050.h>
#include <Adafruit_Sensor.h>
#include <Wire.h>
#include <Adafruit_GFX.h>
#include <Adafruit_SSD1306.h>

// Different channels and pipes for every robot
#ifdef robot1
  const byte controllerAddress[6] = "c-r01";
  const byte serverAddress[6] = "1-r-s";

  #include "bitmaps/bitmap1.h"
#endif

#ifdef robot2
  const byte controllerAddress[6] = "c-r02";
  const byte serverAddress[6] = "2-r-s";
  
  #include "bitmaps/bitmap2.h"
#endif

#ifdef robot3
  const byte controllerAddress[6] = "c-r03";
  const byte serverAddress[6] = "3-r-s";

  #include "bitmaps/bitmap3.h"
#endif

#define p_red 8
#define p_green 7
#define p_blue 6

#define p_lf 5  //Left Forward Pin
#define p_lb 2
#define p_rf 3
#define p_rb 4  //Right Backward Pin

#define p_vibration 46

#define p_color_s0 45
#define p_color_s1 44
#define p_color_s2 48
#define p_color_s3 47
#define p_color_out 49

#define p_breakLight 9
#define p_lamp 41

const int pushDataTimestamp = 100;

//CE, CSN
RF24 radio(13, 12);
void configureRadio();
void drive(int left, int right);
void rgbWrite(int r, int g, int b);
float fmap(float x, float in_min, float in_max, float out_min, float out_max);
int logMsg(char *x, int len);
int sendSensorData();

int speed;
float turn;
float lm_turn, rm_turn;
int crntMillis, prevMillisData, millisLastPacket, prevMillisDraw;
int lm_ist, rm_ist, lm_soll, rm_soll;
uint8_t controllerConnected, serverConnected;

int inputs[4];
#define JOY_X inputs[0]
#define JOY_Y inputs[1]
#define SHO_L inputs[2]
#define SHO_R inputs[3]

Adafruit_MPU6050 mpu;

struct DataPayload {
  uint8_t zero; // should be 0x00 to signify to server it isn't a log message

  float gyroX;
  float gyroY; 
  float gyroZ;

  float accX;
  float accY;
  float accZ;

  float temp;
  
  uint8_t controllerConnected;
  uint8_t vibration;
};

sensors_event_t sensor_a, sensor_g, sensor_temp;

#define SCREEN_WIDTH 128 // OLED display width, in pixels
#define SCREEN_HEIGHT 64 // OLED display height, in pixels

// Declaration for an SSD1306 display connected to I2C (SDA, SCL pins)
#define OLED_RESET -1 // Reset pin # (or -1 if sharing Arduino reset pin)
Adafruit_SSD1306 display(SCREEN_WIDTH, SCREEN_HEIGHT, &Wire, OLED_RESET);

typedef enum { Default, Dead, Surprised} face_t;

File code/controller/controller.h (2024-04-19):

#include <SPI.h>
#include <nRF24L01.h>
#include <RF24.h>

#define p_lSchulter A3
#define p_rSchulter A2
#define p_joyX A1
#define p_joyY A0

#define p_red 4
#define p_green 5
#define p_blue 6

#define p_joyButton 0
#define p_buzzer 8


#ifdef controller1
  const byte robotAddress[6] = "c-r01";
#endif

#ifdef controller2
  const byte robotAddress[6] = "c-r02";
#endif

#ifdef controller3
  const byte robotAddress[6] = "c-r03";
#endif


int crntMillis, millisLastPacket, robotConnected, prevMillisLoading, millisBoost;
int loading;
#define BOOST_DURATION 5000

#include <LiquidCrystal_I2C.h>

#define I2C_ADDR    0x27
#define LCD_COLUMNS 16
#define LCD_LINES   2
LiquidCrystal_I2C lcd(I2C_ADDR, LCD_COLUMNS, LCD_LINES);

void lcdSwish();
void rgbWrite(int r, int g, int b);

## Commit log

2023-12-11 Initial Commit - moving files from google drive to github
    [NRF24L01.step, Robot_Circuit_V1.kicad_pcb, Robot_Circuit_V1.kicad_sch]
2023-12-15 AZE, stand 15.12.2023 13:53
    [2324_5AHEL_AZE_DA_SumoBots.xlsx]
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2023-12-16 abgegeben, 16-12-2023
    [2324_5AHEL_AZE_DA_SumoBots.xlsx]
2023-12-26 AZE aktualisiert
    [2324_5AHEL_AZE_DA_SumoBots.xlsx]
2023-12-27 AZE aktualisiert, Rev B fertig und Zatl geschickt (27.12.2023, 18:24:21)
    [2324_5AHEL_AZE_DA_SumoBots.xlsx, REVB_V1.00.csv, REVB_V1.00.kicad_pcb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]
2023-12-27 AZE nochmal, hab was vergessen
    [2324_5AHEL_AZE_DA_SumoBots.xlsx]
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2024-01-13 AZE stand 19:32:49, 13:01:2024
    [2324_5AHEL_AZE_DA_SumoBots.xlsx]
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2024-01-30 Neuer server code. Nicht fertig, Roboter code muss angepasst werden. Außerdem: pfadänderung der logs noch nicht in allen codes übernommen.
2024-01-31 AZE aktualisiert 😎, verbesserte Version der DA hochgeladen 🦁
    [2324_5AHEL_AZE_DA_SumoBots.xlsx]
2024-02-02 anpassung map funktion auf fmap. verbindung zw. roboter und controller und roboter und server funktioniert noch nicht gleichzeitig, jetzt verbindung zw. roboter und server auskommentiert. typecasting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
2024-02-03 Files umbennant. Roboter code refactored Alle Files wurden auf lowercase gestellt
    Roboter Code Reihenfolge von Read / Write und stopListening umgestellt. Vielleicht geht das ja jetzt. Auserdem Aenderung Read pipe von 0 auf 1. Funktioniert read() und isAvailable() trotzdem gleich?
    Refactoring von Variablennamen, Ort der Deklaration in roboter.ino und roboter.h
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2024-02-03 AZE aktualisiert, Farbsensor und OLED-Display dokumentiert
    [2324_5AHEL_AZE_DA_SumoBots.xlsx]
2024-02-08 AZE aktualisiert 😜, Infrarotsensor dokumentiert Komponente von Rev B sind fertig
    [2324_5AHEL_AZE_DA_SumoBots.xlsx]
2024-02-10 AZE aktualisiert, WR 20
    [2324_5AHEL_AZE_DA_SumoBots.xlsx]
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2024-02-13 Bug fixes
    Version geht noch immer nicht
    [controller.ino, roboter.h, roboter.ino]
2024-02-13 Bugfixes
    Berechnung für Motorsteuerung. Kom. hatte Fehler, nun auskommentiert.
    [controller.ino, roboter.ino]
2024-02-15 AZE aktualisiert 🔞
    [2324_5AHEL_AZE_DA_SumoBots.xlsx]
2024-02-16 Salvation
    Kom. mit Server und Controller funktioniert gleichzeitig. So kompliziert war die Lösung eh nicht 🙃
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2024-02-16 AZE aktualisiert Never gonna Give u up 🤣
    [2324_5AHEL_AZE_DA_SumoBots.xlsx]
2024-02-17 AZE optisch bearbeitet, Diplomarbeit PM-Teil umformuliert
    [2324_5AHEL_AZE_DA_SumoBots.xlsx]
2024-02-18 Dokumentation Server und Protokoll zw. Roboter und Server. Hinzufügung der Codes in den Anhang
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2024-02-19 Code: Bugfixes in implementierung von Gyroskop
    Problem: Im Gyroskop Datenpacket werden zu viele Bytes gesendet, das RF24 Modul kann max. 32 senden.
    To Do: Aufteilen des Packets in Acc, Gyro und Temp um das zu vermeiden
2024-02-19 Bugfixes für Gyroskop Roboter-seitig
    [roboter.h, roboter.ino]
2024-02-19 Code: Bugfix Gyroskop
    Die Packete des Gyroskops werden aufgeteilt, um das 32 Byte-limit des RF24 Moduls nicht zu erreichen.
    [roboter.ino]
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2024-02-19 kurz was umgeschrieben 😐
    [2324_5AHEL_AZE_DA_SumoBots.xlsx]
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2024-02-20 Code: Einige Änderungen in Roboter
    1. Array wird zwischen jedem Versenden mit clearDataArray komplett gelöscht.
    2. Check, ob Gyro auch angeschlossen wurde -> Fehler in Elektronik wurde aufgedeckt
    3. LED wird runtime geupdated, wenn er sich mit dem Server verbindet
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2024-02-20 AZE (auf Gönnungtour) aktualisiert, Controller Blockschaltbild eingefügt
    [2324_5AHEL_AZE_DA_SumoBots.xlsx]
2024-02-22 AZE aktualisiert :^)
    [2324_5AHEL_AZE_DA_SumoBots.xlsx]
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2024-02-23 Revert "merging"
    This reverts commit bf34cdf9def5635425216a1e9576eeff1efccdaf, reversing
    changes made to 7d91e4d6d1b951679c960df9d1e7a7bc1c21a0f7.
    [server.py]
2024-02-23 AZE und DA Dokumentation
    [2324_5AHEL_AZE_DA_SumoBots.xlsx]
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2024-02-24 Code: /data returns dict not 2d array. style.css fixed identation. replaced write_log with array.append. Added /about page
    [roboter.ino, server.py]
2024-02-26 AZE aktualisiert stand 26.02.2024
    [2324_5AHEL_AZE_DA_SumoBots.xlsx]
2024-02-28 AZE aktualisiert 😎
    [2324_5AHEL_AZE_DA_SumoBots.xlsx]
2024-03-01 AZE und HW-Teil erweitert
    [2324_5AHEL_AZE_DA_SumoBots.xlsx]
2024-03-04 AZE für Week 27 geöffnet, Montag eingetragen
    [2324_5AHEL_AZE_DA_SumoBots.xlsx]
2024-03-05 korrigierte Version von ZATL V1.8, noch zwei Versionen bis Sense ☠
2024-03-06 AZE aktualisiert 😶
    [2324_5AHEL_AZE_DA_SumoBots.xlsx]
2024-03-07 AZE aktualisiert 😋
    [2324_5AHEL_AZE_DA_SumoBots.xlsx]
2024-03-08 HW-Controller und Doc.
    [Controller_REVA_V1.kicad_pcb, Controller_REVA_V1.kicad_sch, PinDoc_RevA.xlsx]
2024-03-09 HW-Teil fertiggeschrieben (Raspi Zero u. ESP32 fehlt, wird bei korrekte Inbetriebnahme Dok.)
    [Controller_REVA_V1.kicad_sch]
2024-03-14 AZE aktualisiert & Sensornutzen dokumentiert
    [2324_5AHEL_AZE_DA_SumoBots.xlsx]
2024-03-15 AZE + Dok
    [2324_5AHEL_AZE_DA_SumoBots.xlsx]
2024-03-18 Dok. + AZE
    [2324_5AHEL_AZE_DA_SumoBots.xlsx]
2024-03-19 HW-Dokumentation auf den neusten Stand
    [2324_5AHEL_AZE_DA_SumoBots.xlsx]
2024-03-20 AZE aktualisiert, Dok: PCB u. Circuit im Anhang, neues OSP
    [2324_5AHEL_AZE_DA_SumoBots.xlsx]
2024-03-21 Documentation channels / pipes
    [Pipes_Channels.xlsx]
2024-03-21 AZE aktualisiert, Dokumentation: neues PSP, Roboter Rev A fertig, Controller Rev A fertig --> Rev B finale Ergebnisse mit Sensoren
    [2324_5AHEL_AZE_DA_SumoBots.xlsx]
2024-03-23 AZE homies
    [2324_5AHEL_AZE_DA_SumoBots.xlsx]
2024-03-24 AZE++; Dok: PM-Inhalte, neues Abstract; Bedienungsanleitung: Draft
    [2324_5AHEL_AZE_DA_SumoBots.xlsx]
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2024-04-01 Korrektur von Zatl, neuer Ganttchart, AZE aktualisiert
    [2324_5AHEL_AZE_DA_SumoBots.xlsx]
2024-04-02 BC, AZE, Dok
    [2324_5AHEL_AZE_DA_SumoBots.xlsx]
2024-04-03 small aze update
    [2324_5AHEL_AZE_DA_SumoBots.xlsx]
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2024-04-05 AZE + Dok.
    [2324_5AHEL_AZE_DA_SumoBots.xlsx]
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2024-04-09 Farbkopien sind teuer.
    [Binden_kosten.xlsx]
2024-04-19 Lösche noch mehr
    [Pipes_Channels.xlsx]
